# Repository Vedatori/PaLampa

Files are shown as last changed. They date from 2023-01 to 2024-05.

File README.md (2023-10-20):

# PaLampa [cz]
PaLampa je chytrá stolní lampička navržená jako výrobek na Letní robotický tábor 2023 organizovaný spolkem [Vědátoři](www.vedatori.cz). 
Jedná se o výrobek speciálně vyvinutý tak, aby si na něm člověk mohl zlepšit dovednosti při mechanické stavbě, pájení a programování. 
Účastníci dostali tento výrobek jako stavebnici, kdy pájeli nestandardní součástky na DPS s předem osazenými SMD součástkami a z předem připravených dílů sestavili mechanickou část. 
Po finalizaci je možné výrobek programovat a díky množství vstupních a výstupních periferií si naprogramované funkcionality přehledně demonstrovat. 
Nakonec je výrobek možné použít jako chytrou a praktickou stolní lampičku. 

Mechanickou část lze rozdělit na dvě hlavní části - spodní krabici a horní lampu. Vnější části krabice jsou vyřezány z překližky na laserové řezačce a obsahují zámkové západky. 
Ty se při stavbě lepí disperzním lepidlem a po vyschnutí tvoří pevný základ pro uložení ostatních dílů. 
Základní díl horní lampy je vytisknutý na 3D tiskárně a světelný difuzor je vyřezán z plexiskla, které bylo následně zmatněno. 
Spojení osmiček a krabice zajišťuje 3D tištěný nosník umístěný uvnitř krabice, který také fixuje desky plošných spojů (DPS). 
Spojení krabice a lampy zajišťuje překližkový nosník napojený skrze ohebné kouby, kdy spodní kloub disponuje aretací v několika polohách. 

Hlavní DPS obsahuje zejména mikrokontroler ESP32, který je na ni připájen. Programování a napájení je zajištěno přes USB-C. 
Hlavní DPS obsahuje také tlačítka, dotyková tlačítka, potenciometr, fotorezistory, teplotní senzor, OLED grafickou obrazovku a bzučák. 
V lampě je vsazena DPS osazená LED světly svítícími teplou a studenou bílou, stejně jako řadou adresovatelných RGB LED. Další takové LED jsou umístěny zezadu na nosníku, kde zajišťují ambientní podsvětlení prostoru za výrobkem. 
Výrobek je rozebiratelný, jednotlivé DPS jsou spojeny konektory, vzdálenější periferie pomocí kabelů.

Všechny periferie byly zvoleny tak, aby vytvořily výrobek s mnoha volitelnými postranními funkcionalitami. 
Díky nim je možné u účastníků tábora rozvíjet jejich schopnost algoritmizovat úlohu a programovat. 
Pro hodiny byla vytvořena softwarová knihovna, která výrazně zjednodušuje interakci s periferiemi. 
Pomocí této knihovny byl vytvořen vzorový software, pomocí kterého je možné výrobek používat v základním nastavení. 
Výrobek je možné ovládat pomocí vstupních periferií nebo přes WiFi skrz počítač nebo smartphone, které přistupojí k interně hostované webové stránce. 
Všechny tyto vlastnosti lze upravovat a přidávat nové funkcionality podle přání uživatele. Zařízení se programuje ve Visual studio Code v jazyce C++ pomocí frameworku esp32-arduino.

Myšlenkou tohoto projektu je, aby výrobek tvořil každodenní užitečný doplněk pokoje, ale aby mohl být jeho software jednoduše modifikován a rozvíjen tak, jak si každý jeho vlastník představuje.

## Návod
Při stavbě hodin Time-O-Mat postupujte podle připravených návodů v následujícím pořadí:
1. [Návod pro elektroniku](https://github.com/Vedatori/PaLampa/blob/main/Manuals/PaLampa_electronics_cz.md)
1. [Návod pro mechaniku](https://github.com/Vedatori/PaLampa/blob/main/Manuals/PaLampa_mechanics_cz.md)
1. [Návod pro programování](https://github.com/Vedatori/PaLampa/blob/main/Manuals/PaLampa_programming_cz.md)
1. [Lekce na programování](https://github.com/Vedatori/PaLampa/blob/main/Manuals/PaLampa_lectures_achievements.md)

# PaLampa [en]
PaLampa is a smart desk lamp designed as a product for the Summer Robotics Camp 2023 organized by the association Vědátoři. It is a product specially developed to help individuals improve their skills in mechanical construction, soldering, and programming. Participants received this product as a kit, where they soldered non-standard components onto a PCB with pre-mounted SMD components and assembled the mechanical part from pre-prepared pieces. After completion, the product can be programmed, and the programmed functionalities can be easily demonstrated thanks to the variety of input and output peripherals. In the end, the product can be used as a smart and practical desk lamp.

The mechanical part can be divided into two main components - the bottom box and the upper lamp. The outer parts of the box are laser-cut from plywood and include locking mechanisms. These are glued together with dispersion adhesive during construction, forming a sturdy foundation for the placement of other components.
The core component of the upper lamp is 3D-printed, and the light diffuser is cut from frosted plexiglass. The connection between the box and the lamp is ensured by a 3D-printed beam located inside the box, which also secures the printed circuit boards (PCBs).
The connection between the box and the lamp is facilitated by a plywood beam connected through flexible joints, with the lower joint having several locking positions.

The main PCB (Printed Circuit Board) primarily features the ESP32 microcontroller, which is soldered onto it. Programming and power supply are provided through USB-C. The main PCB also includes buttons, touch buttons, a potentiometer, photoresistors, a temperature sensor, an OLED graphic display, and a buzzer.
In the lamp, there is a PCB embedded with warm and cool white LEDs, as well as a series of addressable RGB LEDs. Additional LEDs of this kind are positioned at the rear on the beam, providing ambient lighting for the area behind the product. The product is modular, and the individual PCBs are connected via connectors, while remote peripherals are linked using cables.

All peripherals were selected to create a product with many optional side functionalities. Thanks to these features, participants in the camp can develop their ability to algorithmize tasks and program. A software library was developed for the lessons, significantly simplifying the interaction with peripherals. Using this library, a sample software was created that allows the product to be used in its basic configuration.
The product can be controlled through input peripherals or via Wi-Fi using a computer or smartphone connecting to an internally hosted web page. All of these features can be customized, and new functionalities can be added as per the user's desires. The device is programmed in Visual Studio Code using the C++ language and the esp32-arduino framework.

The idea behind this project is for the product to serve as an everyday useful addition to a room, but with software that can be easily modified and expanded as envisioned by each owner.

## Licence
* Obsah tohoto repozitáře mimo složku *Software* je sdílen pod licencí [Attribution-NonCommercial-ShareAlike 4.0 International (CC BY-NC-SA 4.0)](https://creativecommons.org/licenses/by-nc-sa/4.0/).
* Obsah složky *Software* je sdílen pod licencí [GNU Lesser General Public License v3.0](https://www.gnu.org/licenses/lgpl-3.0.en.html).

## License
* The contents of this repository excluding folder *Software* is shared under license [Attribution-NonCommercial-ShareAlike 4.0 International (CC BY-NC-SA 4.0)](https://creativecommons.org/licenses/by-nc-sa/4.0/).
* The contents of the folder *Software* is shared under license [GNU Lesser General Public License v3.0](https://www.gnu.org/licenses/lgpl-3.0.en.html).

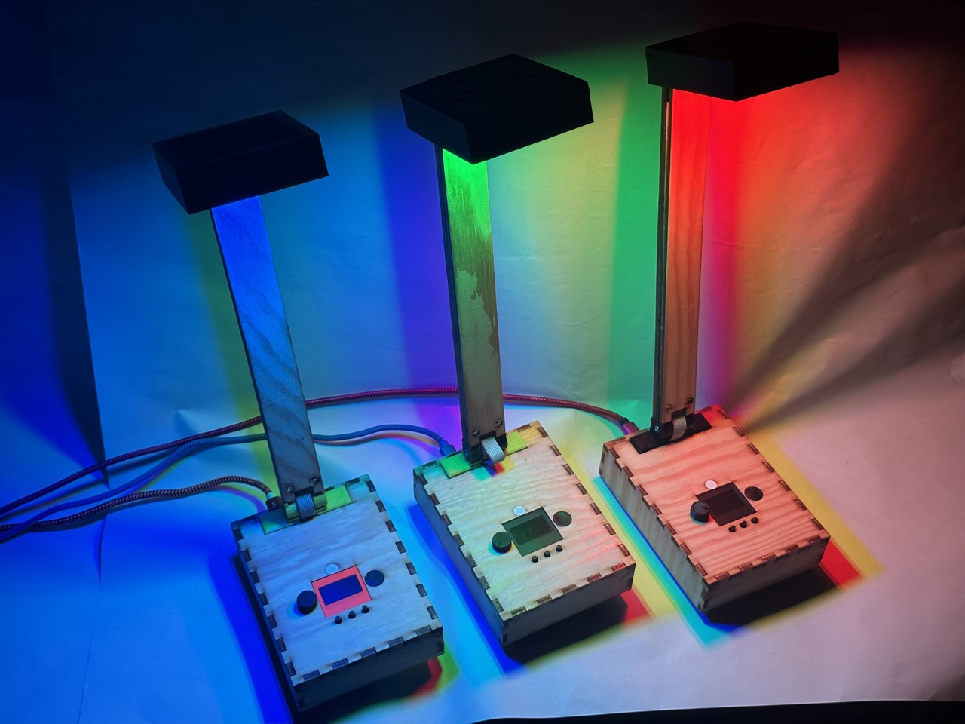
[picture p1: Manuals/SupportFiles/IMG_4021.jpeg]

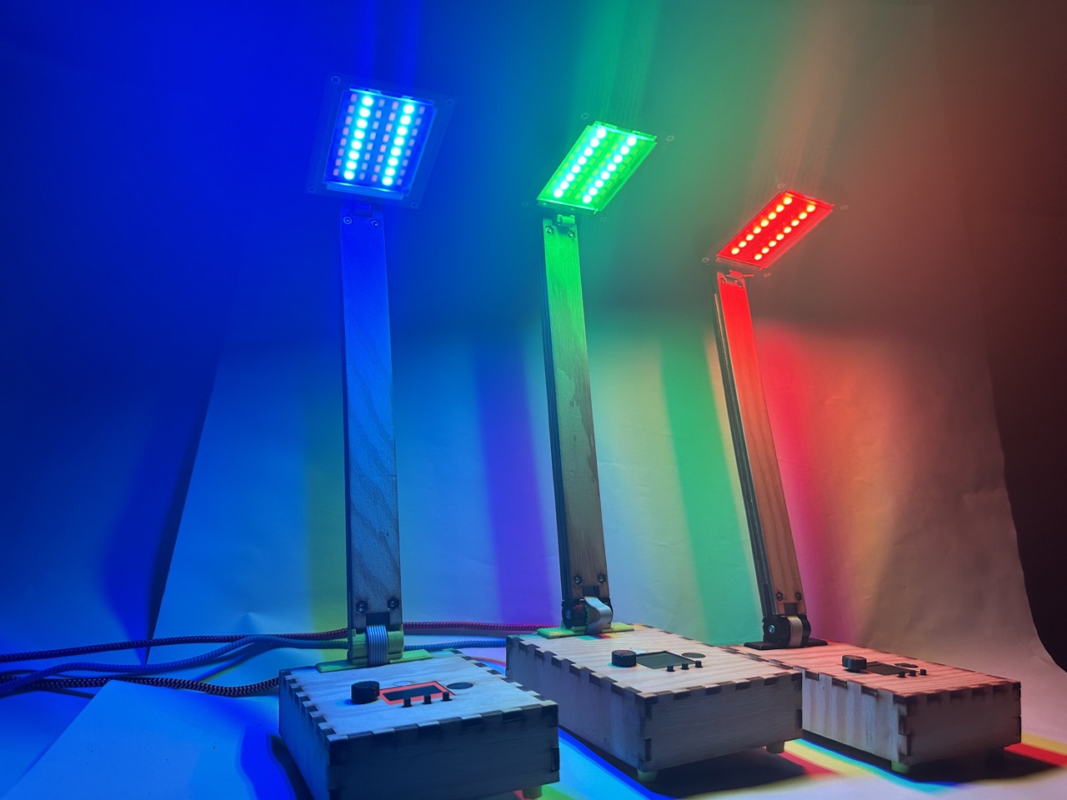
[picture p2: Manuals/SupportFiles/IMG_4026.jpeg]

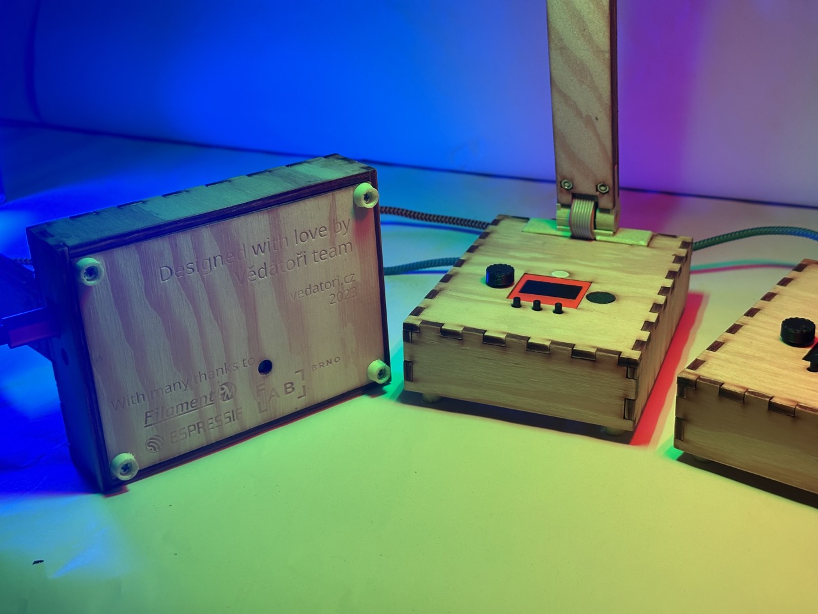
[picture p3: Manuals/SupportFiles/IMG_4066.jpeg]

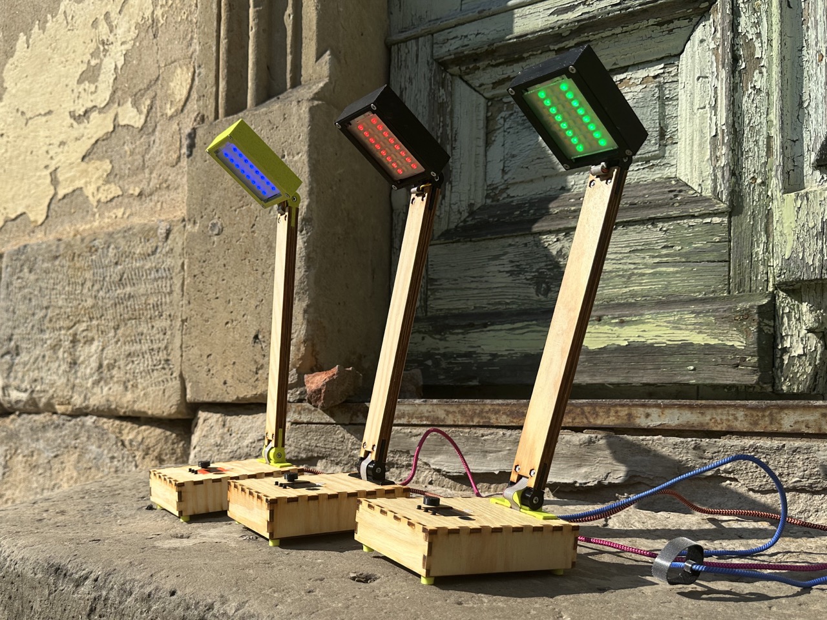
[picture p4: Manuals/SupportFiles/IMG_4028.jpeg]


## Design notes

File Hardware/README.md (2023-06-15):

# HW Designer's notes
## I2C addresses
+ OLED Display - `0x3C`
+ FUSB302 - `0x22`

## Current consumptions
+ Board's idle current consumption (with overhead) - ESP and OLED running, no LEDs - 150 - 200 mA
+ WW or CW string at 100% duty (without board's idle consumption) - 1400mA, the current consumption is approximately linear with the PWM duty cycle

## Misc
+ Potentiometer is wired backwards (eg. ADC value decreases when turning counter clockwise) - change it in the next Rev or in SW
+ Current sense resistor in the CC LED driver was probably DoA, check who's fault it was, maybye use 1206 reistors for current spikes from charged capacitors when connecting LEDs to running driver
+ Some LEDs were not soldered correctly - there is probably nothing I can do about it, just beware.
+ Change WW pin to IO17 (Pin 28), internal pullup on IO5 caused short flash on startup / ESP reset. The situation is much better on GPIO17, but for some reason the WW strings still flash on startup (but not on ESP rst, which is weird, might look into it later with more boards assembled).
+ Add JST for Neopixel
+ New Vedatori Logo

## 17.05.2023 - Developer's meeting
+ Add temperature measurement to LED board
+ Add milled grooves to LED board edges for better cooling
+ Add JST 3 pin for neopixel LEDs onto mainboard and create new Neopixel channel
+ Move one photoresistor to the back, switch it with the electrolytic capacitor, move the second photoresistor somewhere near
+ Add "do not remove while running" text near connectors 
+ Add 2 pin JST for touch
+ move buzzer

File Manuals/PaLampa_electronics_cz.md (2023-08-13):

V tomto dokumentu je uveden návod na osazení desky plošných spojů elektronickými součástkami. Některé součástky byly osazeny strojově při výrobě desek. Zbytek osazení je předmětem tohoto návodu.
Pro tento návod si zavedeme následující pojmy:
* DPS (Deska Plošných Spojů) - Laminátová deska pokrytá elektricky vodivými měděnými cestami, na kterou budeme nyní pájet součástky.
* PCB (Printed Circuit Board) - To stejné, co DPS.
* SMD (Surface Mount Device) - Tzv. bezvývodové elektronické součástky, které mají krátké nožičky. Tyto součástky jsou připájeny k DPS pouze z jedné strany. Tyto součástky byly osazevy strojově při výrobě DPS.
* THT (Through-hole Technology) - Tzv. vývodové elekotronické součástky, které mají dlouhé nožičky. Tyto nožičky jsou před zapájením součástky prostrčeny skrz otvory v DPS.

THT součástky budeme pájet následujícím způsobem:
1. Součástku vkládáme ze strany, kde je její obrys naznačen bílou čárou, tzv. silkscreenem.
1. Vývody (nožičky) součástek prostrčíme přisušnými otvory v DPS. Musí to jít lehce.
1. Součástku přitlačíme až k desce nebo co nejblíže.
1. Součástku pájíme ze strany, na kterou trčí její vývody. Tzn. z opačné strany, než je její bílý obrys na silkscreenu.
1. Vývody po zapájení zastřihneme.

___
# Obsah
* [Nízké součástky](#nizke)
* [Ovládací součástky](#ovladaci)
* [Měřicí součásstky](#meridla)
* [Vložení displeje](#displej)
* [LED deska](#LEDdeska)
* [Výroba kabelu](#tukabel)
* [Připevnění krytky](#krytka)
___

<!-- _________________________________________________________________ -->
# <a name = nizke>Nízké součástky</a>

## Potřebujeme:
* Hlavní PCB (černý)
* 2pin JST konektor
* piezoměnič
* 2x kondenzátor
* štípací kleště
* páječka

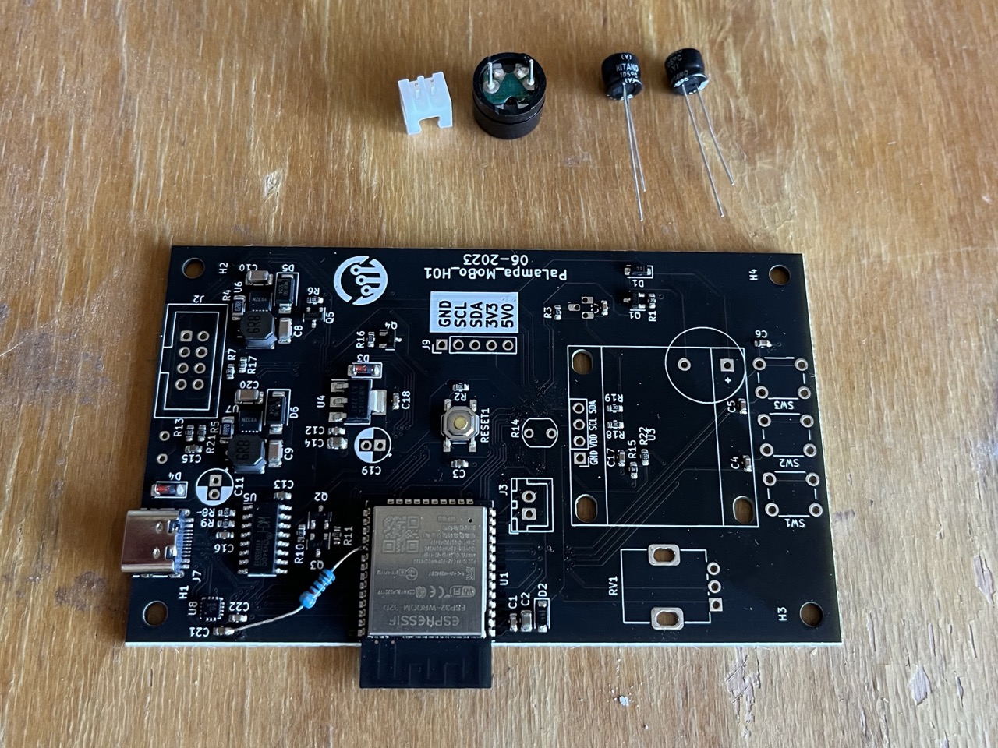
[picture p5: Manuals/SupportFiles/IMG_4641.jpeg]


## Postup:
Vložte piezoměnič na jeho místo v desce, Dávejte pozor na polaritu, symbol plus na součástce musí být u symbolu plus na desce.
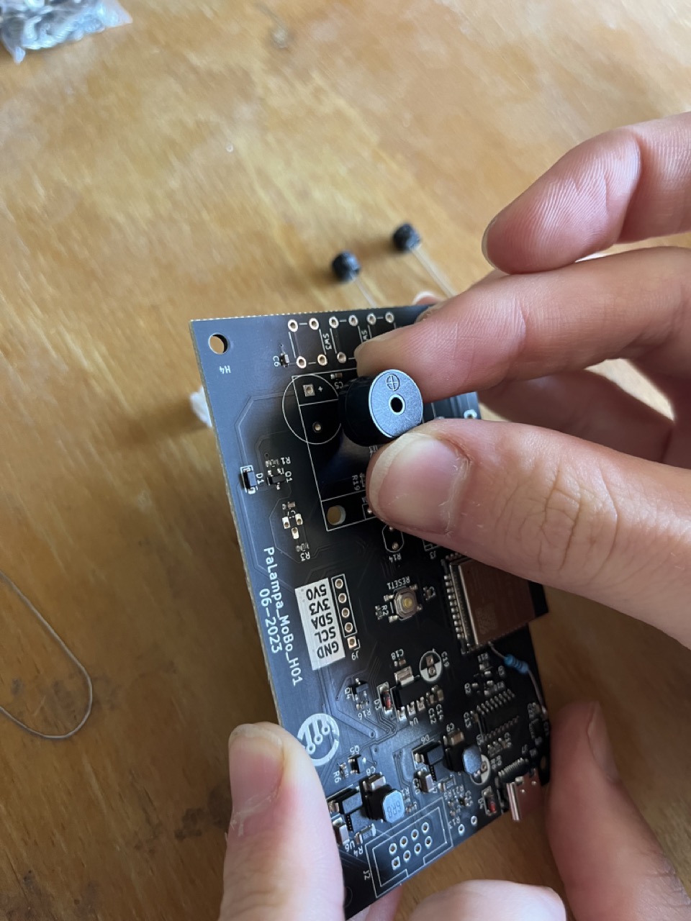
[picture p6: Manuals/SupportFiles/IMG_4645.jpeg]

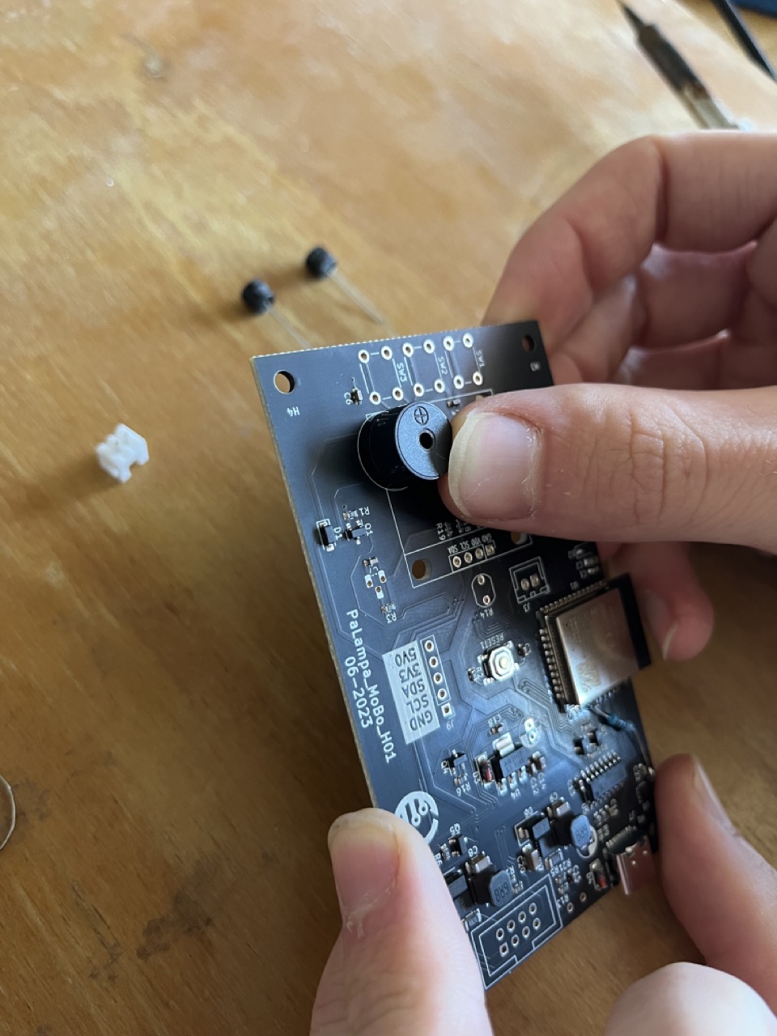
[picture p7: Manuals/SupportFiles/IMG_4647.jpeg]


Zapájejete piezoměnič. Pomocí štípacích kleští zakraťte vývody.
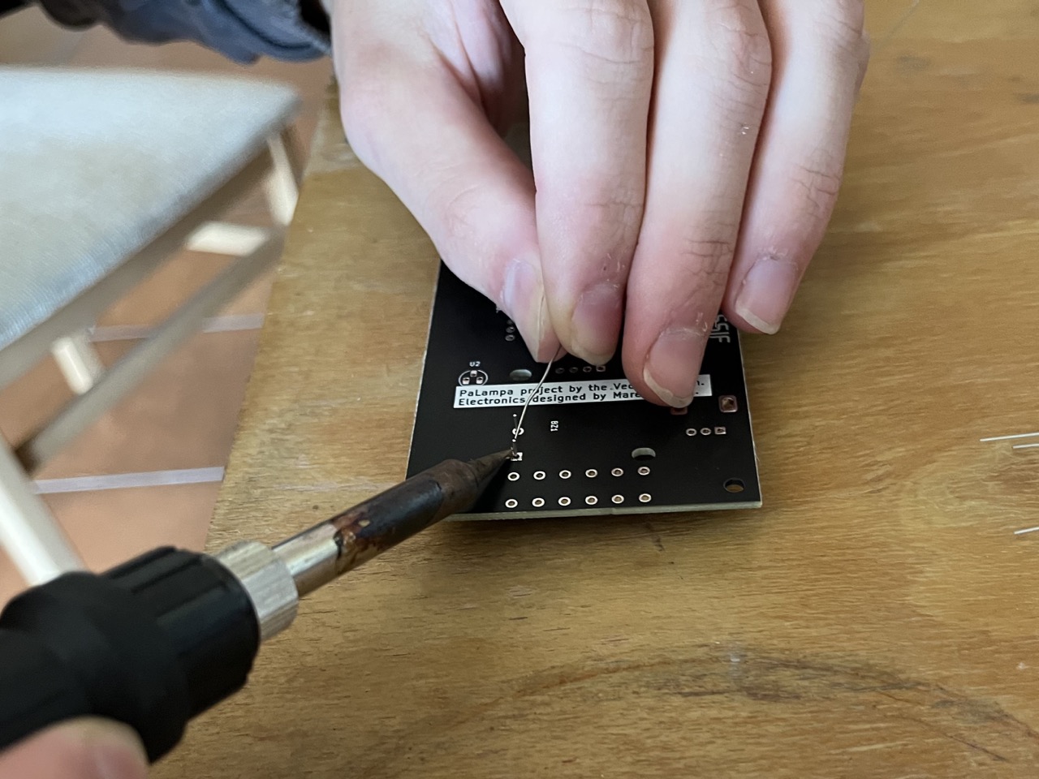
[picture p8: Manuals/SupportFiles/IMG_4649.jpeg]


Vložte do desky konektor JST.Pozor na orientaci, je důležité ho otočit přesně tak, jako je na obrázku.
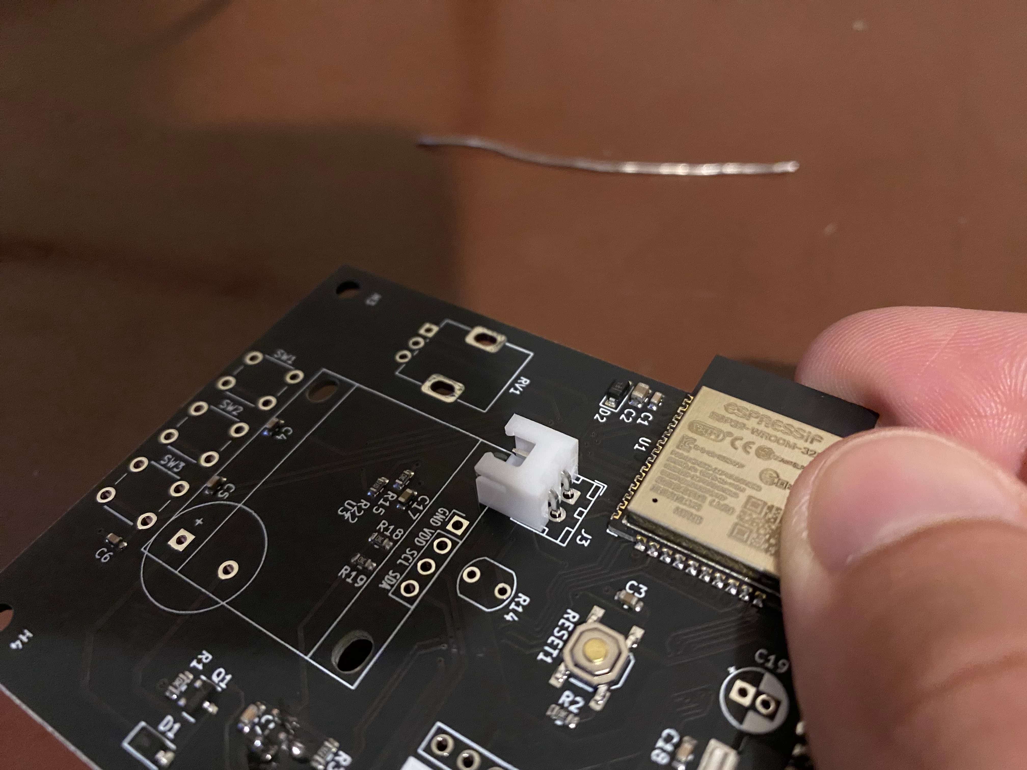
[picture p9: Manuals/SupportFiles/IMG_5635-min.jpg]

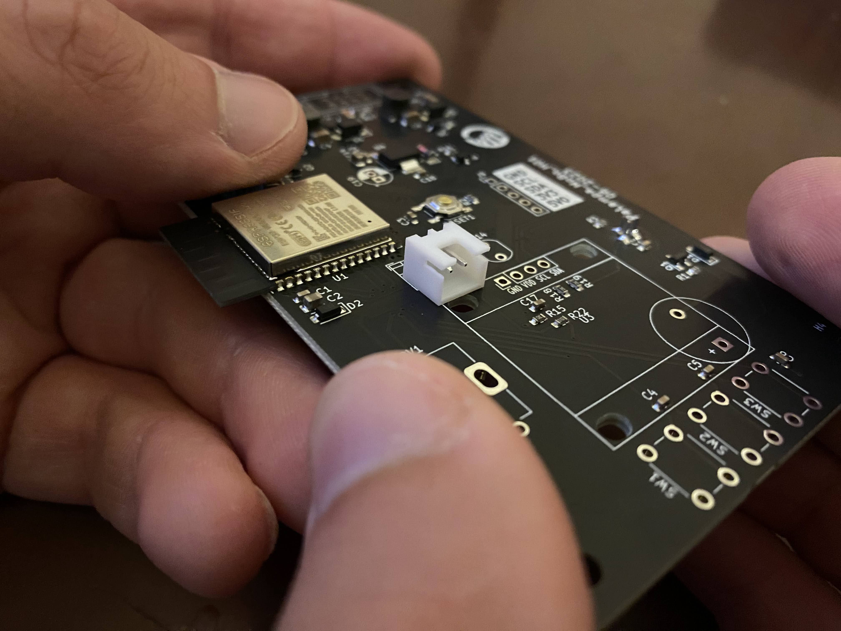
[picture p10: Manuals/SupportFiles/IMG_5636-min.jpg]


Zapájejte. Zakraťte vývody.
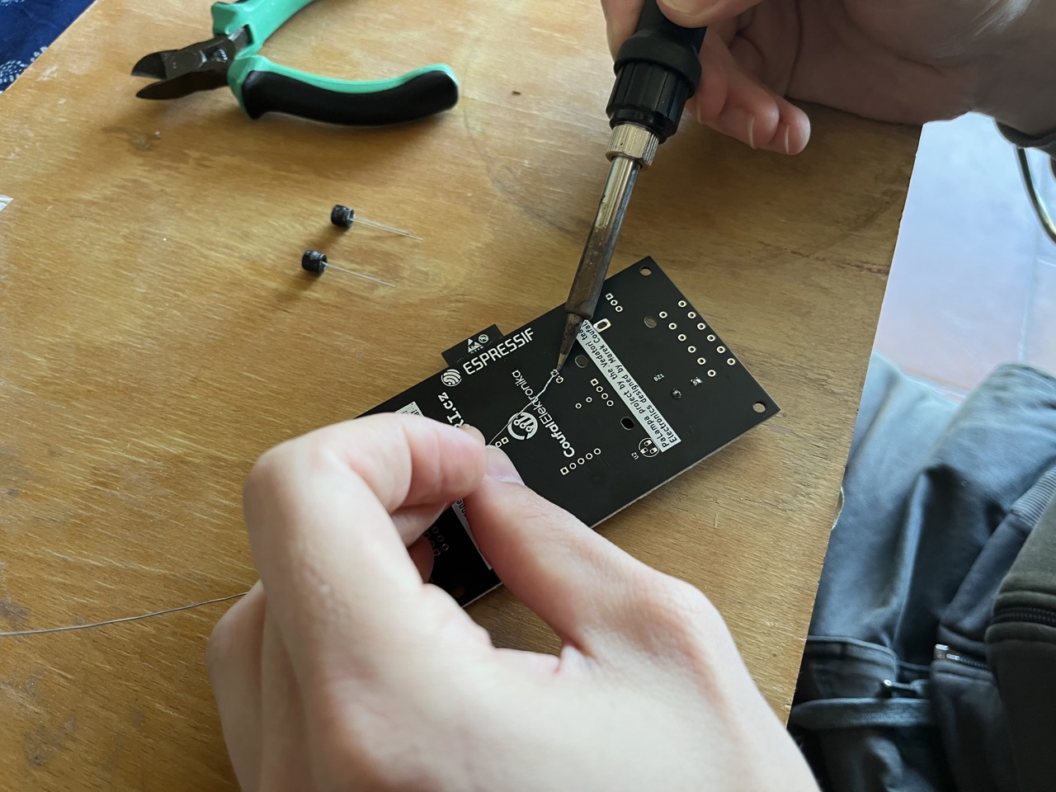
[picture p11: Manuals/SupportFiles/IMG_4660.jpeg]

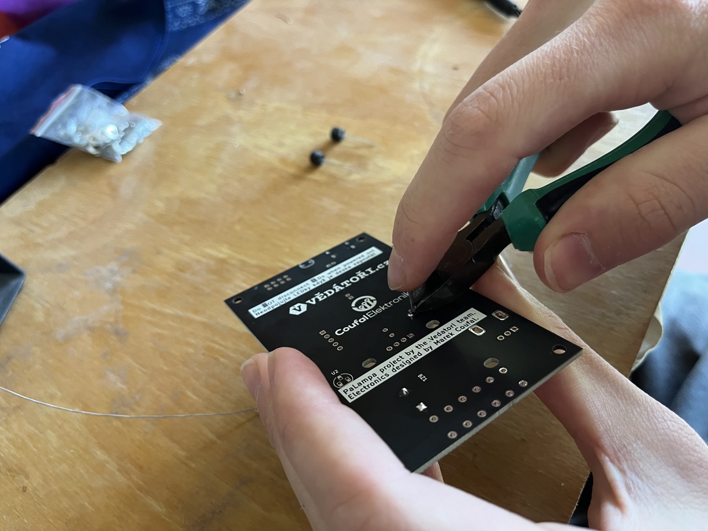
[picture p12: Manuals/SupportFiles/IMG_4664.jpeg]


Vložte do desky kondenzátor na místo označené C11. Pozor na polaritu, kratší vývod musí být zastrčený do poloviny kruhu, která je bíle vybarvená. Druhý kondenzátor vložte stejným způsobem na místo C19. Zapájejte, zakraťe vývody.
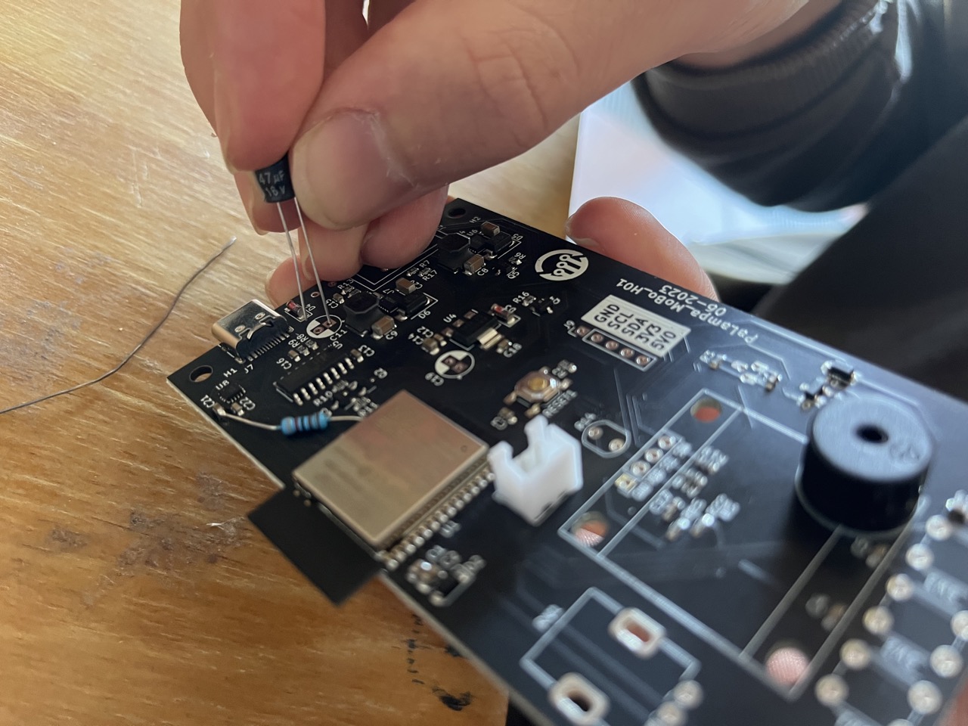
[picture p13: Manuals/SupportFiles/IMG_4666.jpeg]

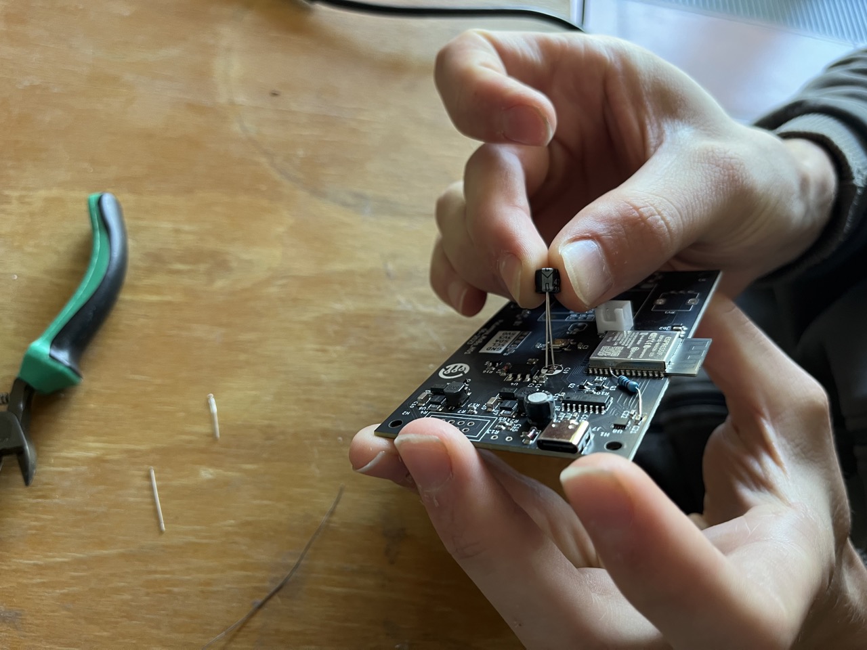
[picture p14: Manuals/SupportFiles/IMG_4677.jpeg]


Takto má deska vypadat po zapájení prvních součástí.
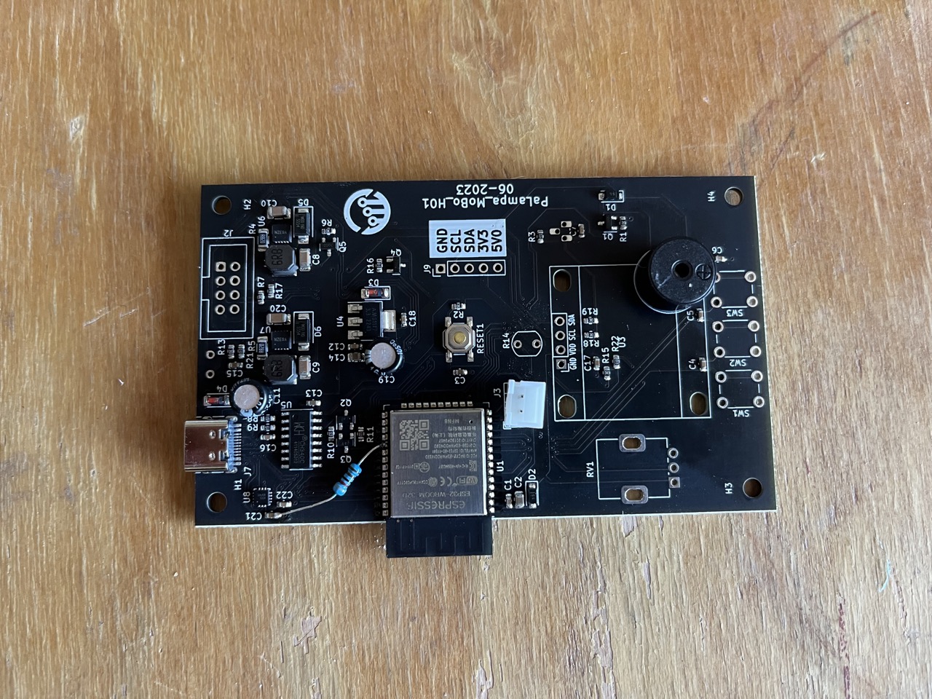
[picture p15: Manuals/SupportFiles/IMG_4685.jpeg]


Kleštěmi oddělte 4 piny z dutinkové lišty. Lištu rozstřihněte na místě, kde je pátý pin od kraje, ten se tím zničí.
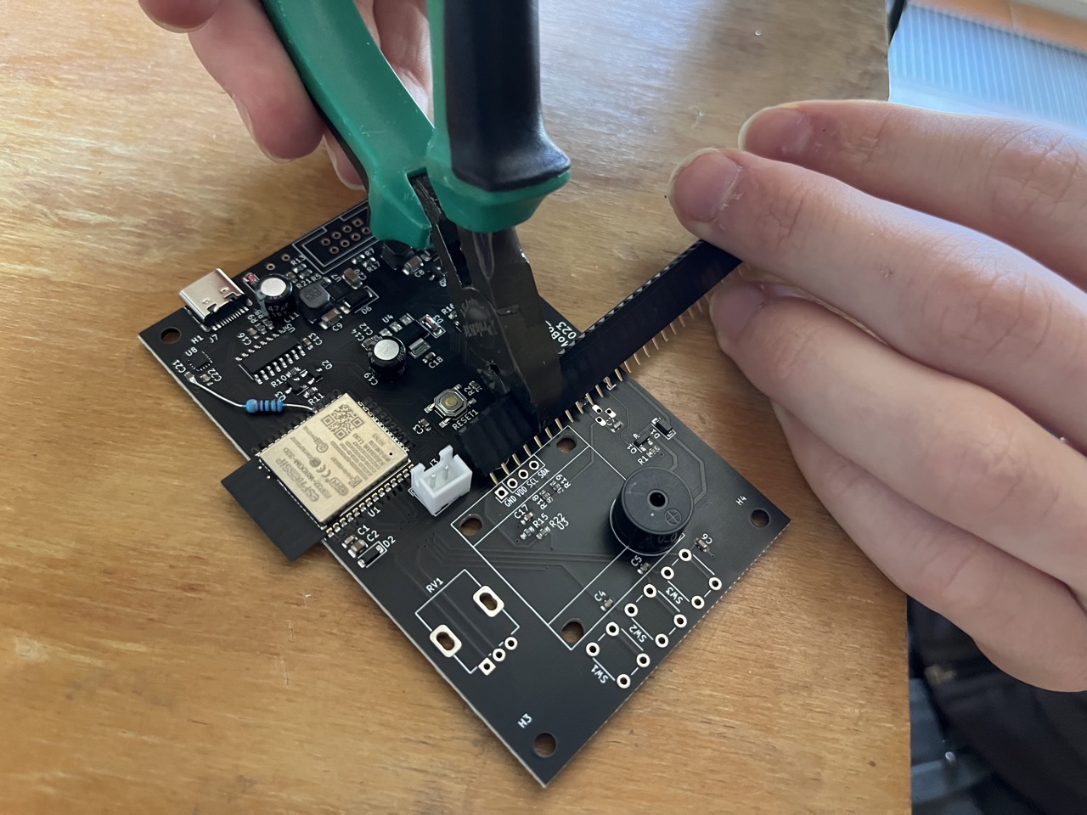
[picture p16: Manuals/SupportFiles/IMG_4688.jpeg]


Opatrně zařízněte boky lišty.
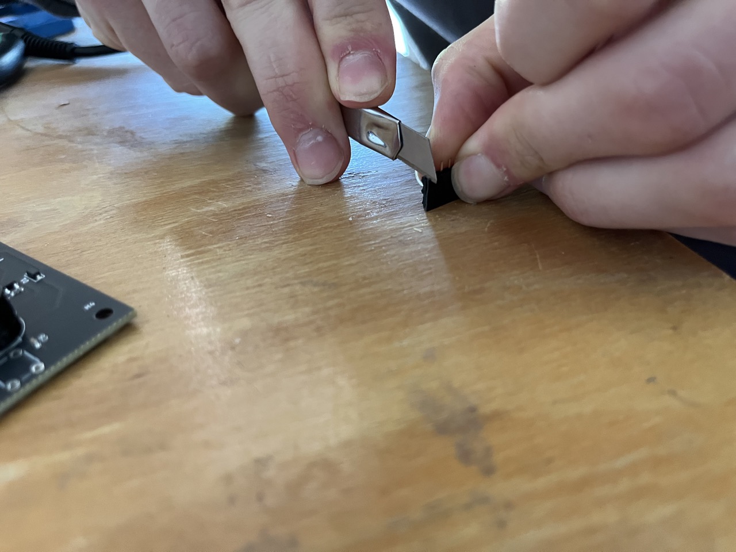
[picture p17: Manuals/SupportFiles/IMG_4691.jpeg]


Lištu vložte do prostoru konektoru na displej, jak vidíte na obrázku. Zapájejte ji.
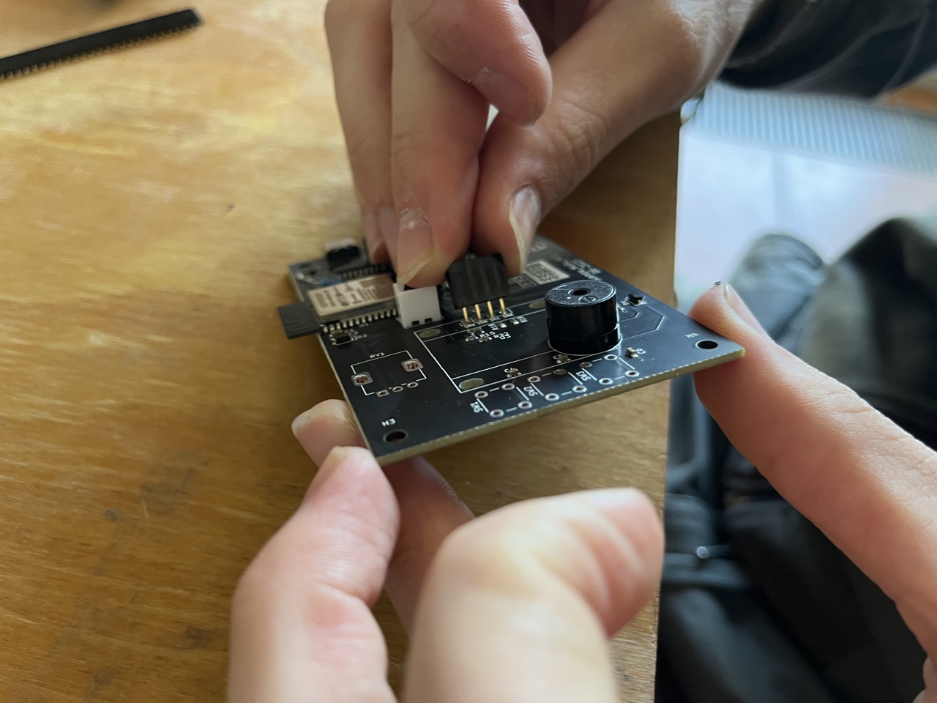
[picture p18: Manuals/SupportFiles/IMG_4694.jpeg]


Výsledný pohled
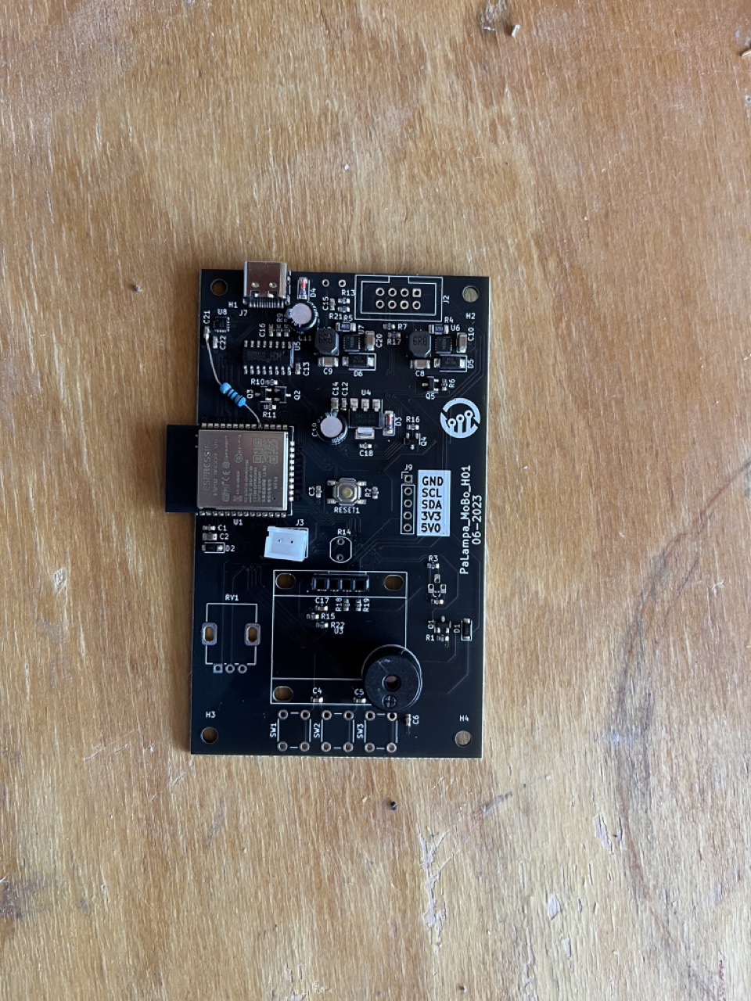
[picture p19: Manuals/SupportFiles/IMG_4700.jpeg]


<!-- _________________________________________________________________ -->
# <a name = ovladaci>Ovládací součástky</a>

## Potřebujeme:
* Hlavní PCB
* 3D tištěný tool pro tlačítka (3 díry)
* 3x tlačítko
* Potenciometr
* Konektor
* štípací kleště
* páječka

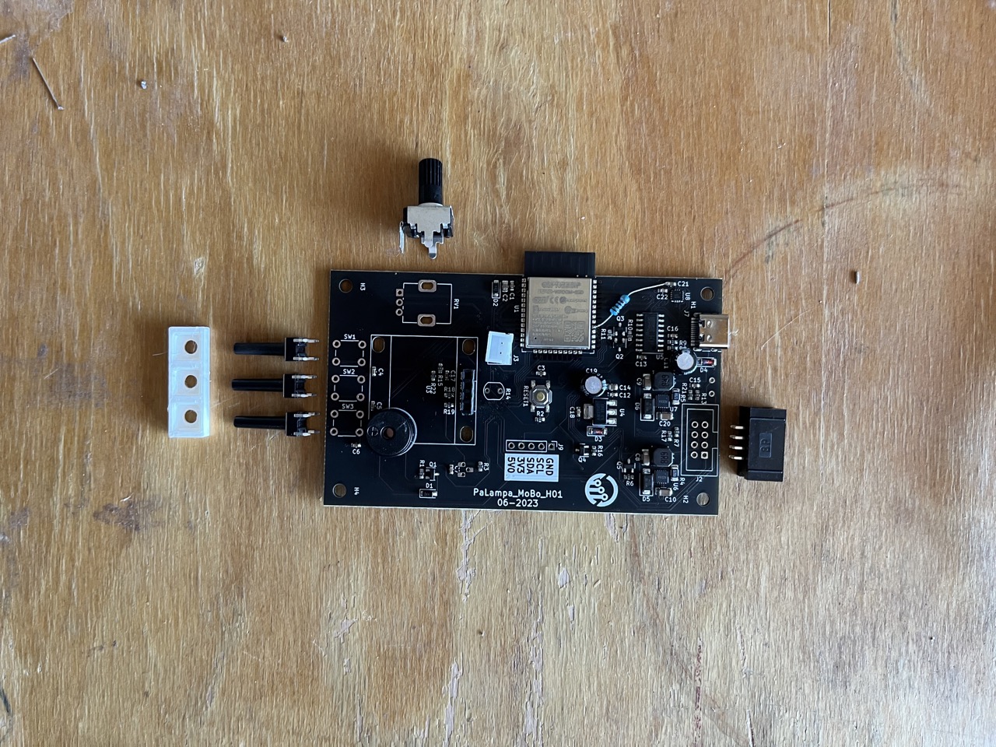
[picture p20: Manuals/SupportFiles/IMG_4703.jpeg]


## Postup:
Nasaďte konektor na hlavní PCB. POZOR! Mezi součástkami jsou dva podobné konektory, tady musíte použít ten, který má krátké nezahnuté nožičky. Konektor musí mít správnou polaritu, výřez musí být směřován na stejnou stranu, jako je na obrázku. Konektor zapájejte.
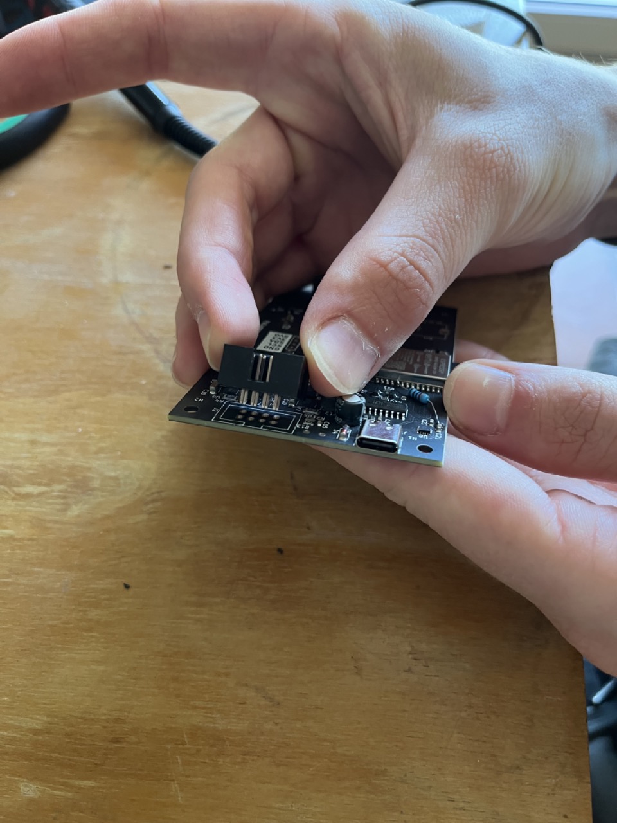
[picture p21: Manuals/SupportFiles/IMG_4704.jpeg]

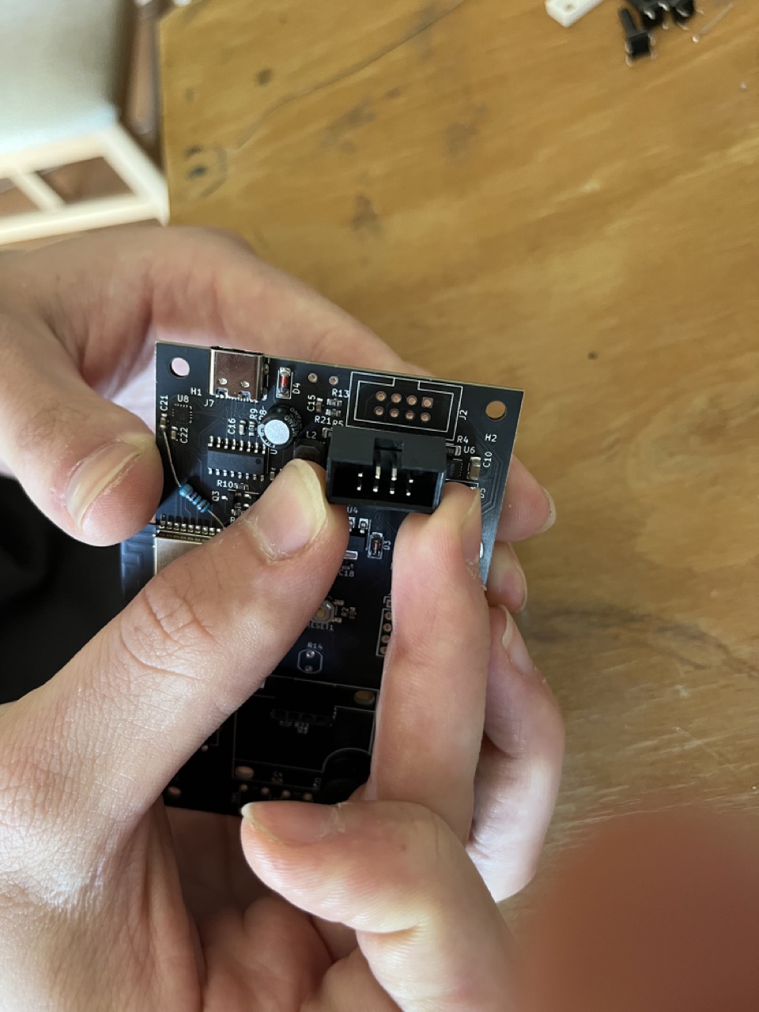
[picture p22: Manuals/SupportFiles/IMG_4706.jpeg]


Usaďte do desky potenciometr.
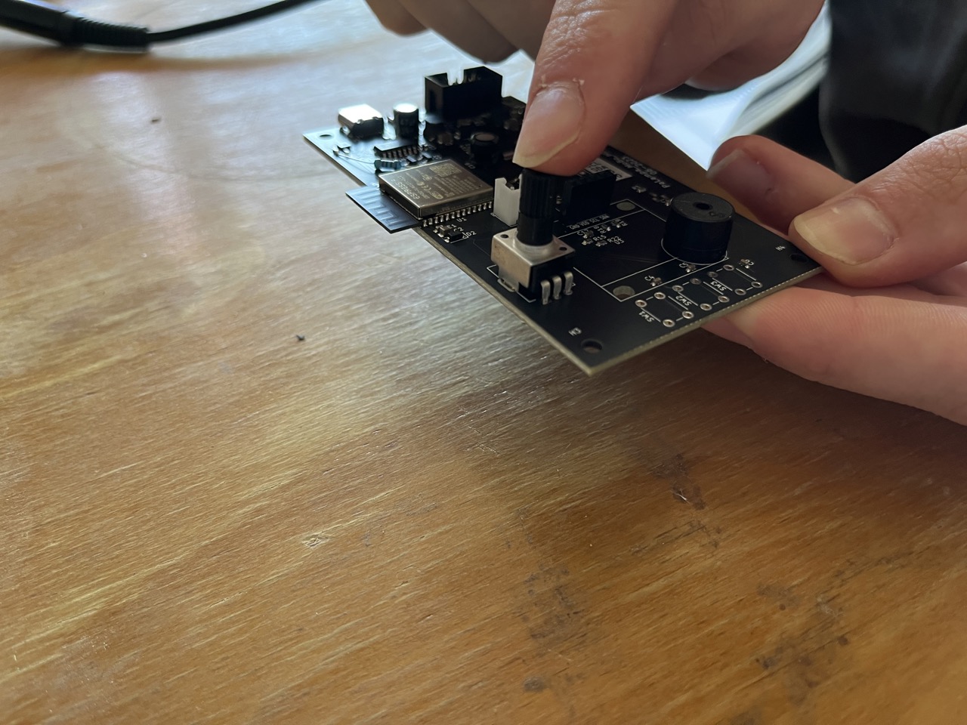
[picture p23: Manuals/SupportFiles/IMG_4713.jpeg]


 Zapájejte všechny vývody včetně velkých plochých. Zakraťte vývody.
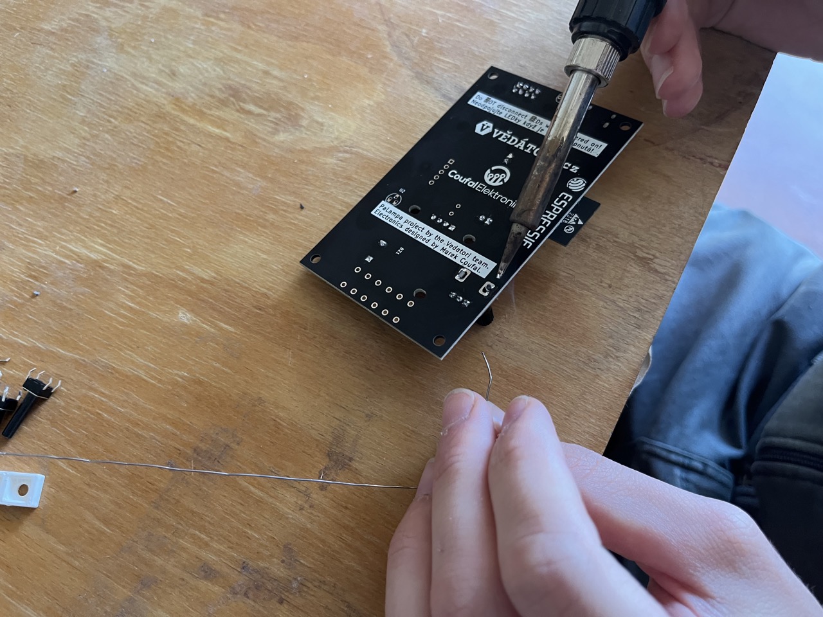
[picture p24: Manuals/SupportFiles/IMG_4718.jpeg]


Vložte tlačítka do hlavního PCB. 
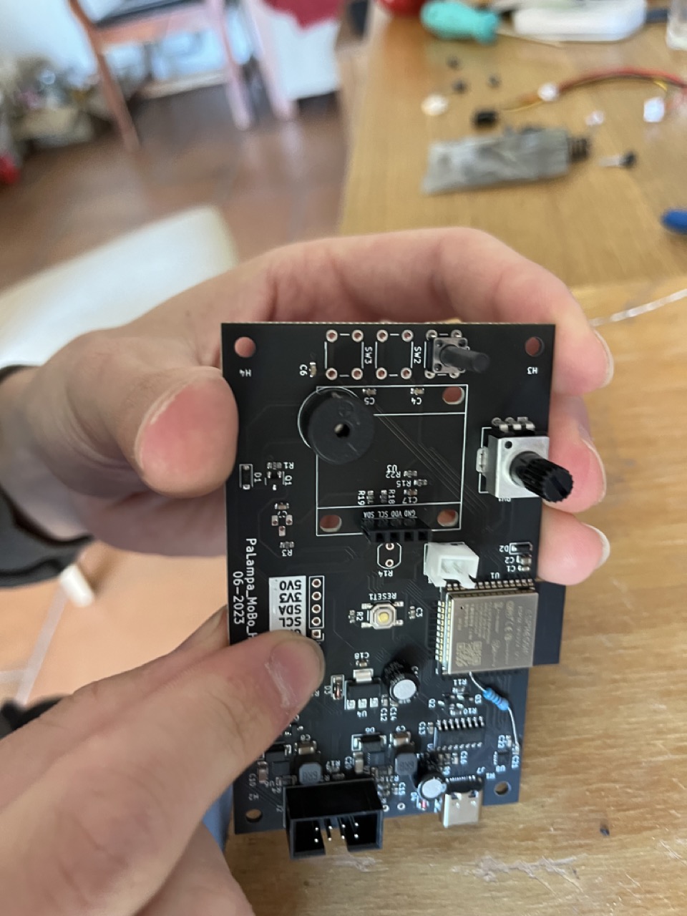
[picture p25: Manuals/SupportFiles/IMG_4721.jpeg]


Na tlačítka nasuňte nástroj s děrami. Musí padnout na všechna zároveň.
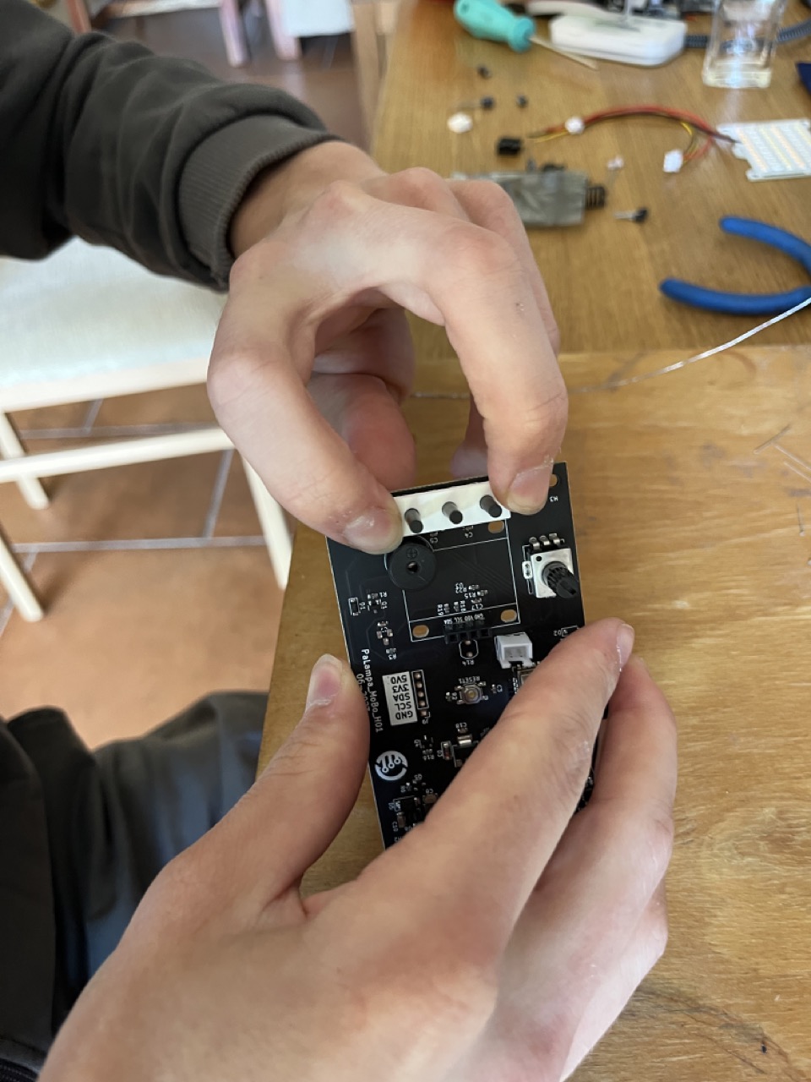
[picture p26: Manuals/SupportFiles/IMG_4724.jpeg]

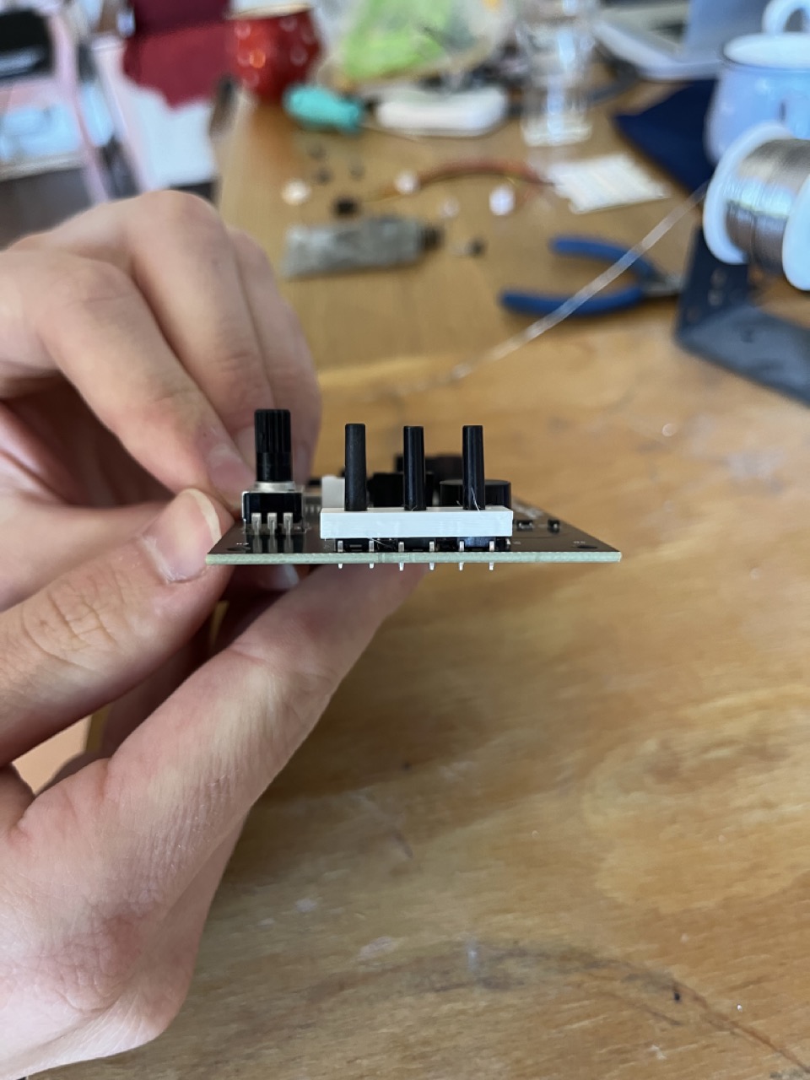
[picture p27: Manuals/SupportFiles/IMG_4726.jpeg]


Zapájejte tlačítka na hlavní PCB. Zakraťte vývody.

<!-- _________________________________________________________________ -->
# <a name = meridla>Měřicí součástky</a>

## Potřebujeme:
* Hlavní PCB
* 2x fotorezistor
* teplotní senzor
* Distanční díl na fotorezistor
* štípací kleště
* páječka

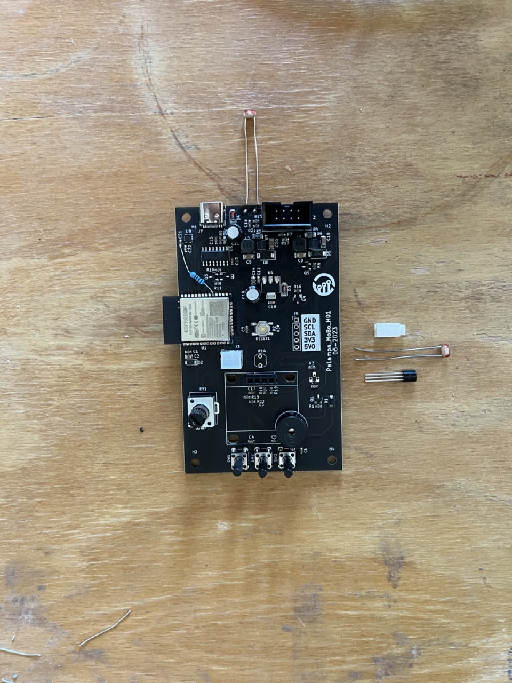
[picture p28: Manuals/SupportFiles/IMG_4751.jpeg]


Do otvoru označeného R13 nasuňte fotorezistor. Odměřte ho podle dříve použitého toolu tak, jak ukazuje obrázek. Zapájejte.




Druhý fotorezistor nasuňte do 3D tištěného distančního dílu. Zapájejte na místo R14. Zakraťte vývody obou fotorezitstorů.




Výsledný pohled na spodní fotorezistor.


Teplotní senzor zasuňte do desky pouze na několik milimetrů. 


Podložte si desku, aby se senzor při pájení neohnul.


Zapájejte. Po zapájení jednoho vývodu ověřte, že je senzor postavený rovně. Pokud ne, tak si senzor ohněte do směru kolmého k desce.


<!-- _________________________________________________________________ -->
# <a name = displej>Vložení displeje</a>

## Potřebujeme:
* hlavní PCB
* Displej s připájenou kolíkovou lištou
* Plastový držák displeje



# Postup:
Zastřihněte vývody kolíkové lišty vedoucí do displeje.


Opatrně vložte displej do držáku. Můžete ho mírně rozevřít, ale dávejte pozor, ať bok nevylomíte.



Zasuňte displej s držákem do hlavní desky pomocí kolíkové lišty.



<!-- _________________________________________________________________ -->
# <a name = LEDdeska>LED deska</a>

## Potřebujeme:
* LED desku
* Teplotní senzor
* Úhlový konektor černý 8 pin
* Úhlový konektor bílý JST 3 pin
* Nástroj pro usazení teplotního senzoru
* Epoxidové lepidlo s kovovým plnivem (namíchá vedoucí)
* Dávkovací špejli
* páječku



## Postup:
Vložte teplotní senzor do 3D tištěného nástroje tak, aby nápis směřoval směrem dovnitř. Ohněte podle nástroje nožičky.


Otočte senzor teploty tak, aby byl čitelný nápis na něm.


Naneste malé množství připraveného epoxidu na plochu senzoru.


Vložte senzor do desky tak, aby směřoval směrem doprostřed desky. Tento krok provádějte pod dohledem vedoucího.


Desku se senzorem pořád umístěným v nástroji přitlačte z druhé strany směrem ke stolu.


Senzor připájejte, zakraťte vývody.


Do desky vložte 3pin bílý konektor. Připájejte a zaktaťte vývody.


Černý konektor vložte do desky stejným směrem, jako vidíte na obrázku.


Desku z druhé strany podepřete nástrojem použitým v minulém kroku.


Konektor připájejte. Výsledný pohled


<!-- _________________________________________________________________ -->
# <a name = tukabel>Výroba kabelu</a>

## Potřebujeme:
* kabel o délce 46 cm
* Kleště nebo malý svěrák na krimpování kabelu
* 2x konektor
* 1x krytka konektoru



POZOR! Kabel se vyrábí pouze na speciálním stanovišti pod dohledem vedoucího. Pokud se konektory nakrimpují špatně, musí se odstřihnout a tím se celý kabel zničí.

## Postup:
Odměřte a ustřihněte si kabel o délce 46 cm.


Nasuňte konektor na kabel tak, aby výstupek směřoval ke kraji kabelu. Šipka na konektoru musí směřovat k červené žíle kabelu.


Zarovnejte konec kabelu s konektorem. Stlačením kabel nakrimpujte. Pozor, je to nevratná operace, nechte si tento krok předem potvrdit vedoucím.


Ohněte kabel přes konektor a upněte ho do krytky. Ta se do konektoru nacvakne.



Na druhý konec kabelu nasuňte konektor tak, aby výstupek směřoval ke kraji kabelu. Šipka na konektoru musí směřovat k červené žíle kabelu.


Zarovnejte konec kabelu s konektorem. Stlačením kabel nakrimpujte. Pozor, je to nevratná operace, nechte si tento krok předem potvrdit vedoucím.


Zapojte kabel. Konec kabelu, kde je na konektoru krytka, se zapojuje do bílé desky s LED, druhý konec do černé hlavní desky. Společně s vedoucím nahrajte firmware a proveďte funkční test sestavy.


<!-- _________________________________________________________________ -->
# <a name = krytka>Připevnění krytky</a>

## Potřebujeme:
* Epoxid bez kovového plniče (namíchá vedoucí)
* Dávkovací špejli
* LED desku
* 3D tištěnou krytku na vývody konektoru



## Postup:
Naneste malé množství epoxidu na plochy na krajích krytky.


Přilepte krytku přes vývody konektoru. Krytka musí být zarovnaná s krajem desky.


<!-- _________________________________________________________________ -->
# <a name = pasek>LED pásek</a>

## Potřebujeme:
* Kabel se 3 vývody
* LED pásek
* pájku



## Postup:
Naneste trochu cínu na LED pásek. Dávejte pozor, z jaké strany pásek pájíte, musí se připojovat na stranu, kde je na střední plošce napsáno Din. Strana, kde je u prostřední plošky napsáno Do musí zůstat volná.


Připájejte kabely v následujícím pořadí:
Černá - 5V
Žlutá - Din
Červená GND


Výsledné zapojení


<!-- _________________________________________________________________ -->
# <a name = touch>Kabel na touch senzor</a>

## Potřebujeme:
* Kabel se 2 vývody
* Měděná páska
* Záslepku pro dotykové tlačítko

## Postup:
Ustřihněte si kusy měděné pásky o délce 10 mm a 20 mm. 


Na střed obou kusů naneste cín.


K 10mm kusu připájejte červený drátek z kabelu. Cu pásku pájejte kolmo ke kabelu.



Stejným způsobem připájejte i černý akbel k 20mm kusu pásky.

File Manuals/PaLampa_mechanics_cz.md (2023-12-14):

Tento dokument je návodem k sestavení mechanické části PaLampy. Hlavními postupy jsou lepení disperzním lepidlem (Herkules) a spojování šrouby.
Lepení dílů je mnohdy nevratný postup! Pokud si před zalepením dílu nejste něčím jistí, je dobré si to buďto vyzkoušet ještě před nanesením lepidla a nebo zavolat vedoucího, který vám poradí. 

Používaná lepidla a jejich vlastnosti
* **Herkules** - disperzní vodou ředitelné lepidlo na dřevo. Doba zasychání záleží na objemu naneseného lepidla, obecně platí, že pomocí tečkování aplikátorem ho naneseme takové množství, aby moc nebo vůbec nevytékalo z lepeného spoje po jeho zmáčknutí. Nanášíme pouze na jednu lepenou plochu a tečky můžeme poté špičkou lepidla rozetřít do plochy.
* **Lepidlo na plasty** - slouží pro upevnění matek ve slotových dírách. Sloty jsou udělané tak, aby se v nich matka nemohla protočit, lepidlo má pouze zafixovat matku, aby celá nevypadla. Nejlepší je tedy nanést malé množství lepidla na hranu matky (nezanášet lepidlem závit) a matku poté zatlačit až na doraz do slotu.

Při práci je důležité mít pořád čisté ruce a pracovní podložku, abyste si dřevo neumazali.
K lakování jsme vybrali polyurethanový lak, který je ředitelný vodou. Pro dobrý výsledek stačí nanést tenkou vrstvu laku na ohlazený a očištěný povrch tak, aby byla pokrytá celá lakovaná plocha (poznáte po naklonění plochy proti světlu). Nanáší se dvě vrstvy, to je v návodu popsáno.

**Pohledové plochy** poznáte tak, že je okolo okrajů lehká rovnoměrná stopa po ožehu a má světle hnědou barvu. Druhá strana není pohledová a obsahuje po obvodu tmavě hnědé nebo černé stopy. 



___
# Obsah
* [Vylití podstavy sádrou](#sadra)
* [Příprava plexiskla](#plexisklo)
* [Příprava překližkových dílů](#preklizka)
* [Sestavení krku](#krk)
* [Slepení krabičky](#krabice)
* [Sestavení části s hexagony](#hexagony)
* [Sestavení podstavy](#spodek)
* [Sestavení spodního kloubu](#spodnikloub)
* [Sestavení horního dílu](#hornidil)
* [Sestavení horního kloubu](#hornikloub)
* [Finalizace](#finalizace)
* [Příloha: Seznam spojovacího materiálu](#spojovacimaterial)
___

<!-- _________________________________________________________________ -->
# <a name = sadra>Vylití podstavy sádrou</a>

## Potřebujeme:
* Spodní díl krabice
* Ohrádku na sádru
* Sádru
* Vodu
* Sádrovací misku
* Špachtli
* Igelitový sáček
* 4 šrouby M3x30 + matky 



## Postup:
Ukliďte si pracovní plochu po předchozích krocích, tj. odstraňte pájku, příslušenství k pájení a zbytky po něm.
Odlévání sádry nedělejte sami. Proveďte to po skupinách pod dozorem vedoucího.

*Připravte si dopředu všechny díly a potřeby. Pokud si je nepřipravíte předem, budete je hledat, když bude sádra tuhnout a místo odlitku budete mít nekompatibilní sádrový talířek.*

Protáhněte šroub jednou dírou v rohu dřeva. Igelit propíchněte šroubem.



Na šroub dejte ohrádku na sádru tak, jak vidíte na obrázku. 



Našroubujte matku, zcela neutahujte.

Než budete propichovat igleit dalšími šrouby, natáhněte jej. Obdobným způsobem provlečte ostatní tři šrouby. Celá plocha igelitu by měla být přiměřeně napnutá.

Na šrouby nasaďte matky a utáhněte je.



Rozmíchejte sádru s vodou do mírně řidší konzistence. 

Sádru vylejte do připravené vaničky. Hladina sádry by měla být jeden až dva milimetry pod úrovní ohrádky. 



Pro lepší rozlití sádry ve vaničce můžete s odlévaným dílem lehce zatřást nebo lehce klepat o nějaký povrch. 

Výsledný díl vylitý sádrou by měl vypadat přibližně takto:



Nechte sádru zatuhnout a mezitím připravte plexisklo podle dalšího kroku.

<!-- _________________________________________________________________ -->
# <a name = plexisklo>Příprava plexiskla</a>

## Potřebujeme:
* díl z plexiskla
* Hrubý smirek (hnědý - 240)
* Jemný smirek (černý - 600)
* Brusná pasta 
* Papírová utěrka



## Postup:
Z plexiskla odstraňte krycí fólie. 



Hrubým smirkem lehce zaoblete hrany dílu z plexiskla. 



Nyní krouživým pohybem hrubým smirkem zdrsněte průhlednou plochu plexiskla z obou stran.  



Stejný postup proveďte s jemným smirkem (600).



Výsledný povrch plexiskla by měl vypadat následovně:



Nyní plexisklo položte na papírový ubrousek. To je důležité kvůli tomu, aby při leštění nedošlo k jeho poškrábání nečistotami!

Na vrchní stranu plexiskla dřívkem naneste malé množství brusné pasty z kelímku. 



Druhým ubrouskem brusnou pastu krouživými pohyby roztírejte po povrchu plexiskla, čímž dojde k jeho vyleštění. 



Stejný postup opakujte i pro druhou stranu plexiskla. Po dokončení leštění díl umyjte. 

<!-- _________________________________________________________________ -->
# <a name = preklizka>Příprava překližkových dílů</a>

## Potřebujeme:
* všechny díly z překližky 
* Hrubý smirek (žlutý - 240)
* Jemný smirek (černý - 600)

## Postup:
Ukliďte si do čista pracovní plochu. Jakékoli zbytky sádry nebo jiného nepořádku zašpiní překližku.

Pokud dřevo stále obsahuje nějaké části, které měly po vyřezání laserem vypadnout, odstraňte je tak, že je vytlačíte ven. Vytlačte je směrem k nepohledové pološe. 



Pokud dřevo obsahuje nějaké otřepy a zbytky po vytlačení odpadních částí, odstaňte je buďto rukou, nožem nebo hrubým (žlutým) smirkem. Ten můžete kvůli tomu přehnout, ale přehněte pouze část u kraje. Dále podle obrázku níže zkoste nožem hranu asi do 1,5 cm od okraje, a to na obou stranách. 



Obruste smirkem pohledové plochy překližky. Přeburuste plochu nejdříve hrubým smirkem (žlutým) a potom ji dohlaďte jemným (černým) smirkem. Většinou je plocha už od začátku v pořádku, takže není potřeba moc brousit, stačí pouze mírně obrousit lehce opálené okraje pohledové strany.



<!-- _________________________________________________________________ -->

# <a name = krk>Sestavení krku</a>

Ukliďte si pracovní plochu po předchozích krocích, tj. setřete prach vzniklý broušením (nejlépe mokrou hadrou nebo kapesníkem).

## Potřebujeme: 
* Děravý a neděravý díl krku
* 2 díly na bok krku (úzké dlouhé tyčky)
* LED pásek s napájenými přívodními drátky
* Tenký dřevěný díl na oporu LED pásku
* 4 díly kloubů
* Herkules
* Tavná pistole
* Nůž
* 4 šrouby M3x12 se zápustnou hlavou + matky

 

## Postup:
Na nepohledové straně dílu v místě naznačeném na obrázku seřízněte nožem vnitřní hranu. Jedná se o hranu směrem k plastovému kloubu s kulatými okraji (bez zoubků).



Od této chvíle je potřeba dávat pozor, aby byl výřez na vrchní straně krku. V dalších krocích budou výřezem protaženy kabely k LED pásku, které musí vést shora. 

Sestavte vždy 2 a 2 díly kloubů dohromady podle obrázku níže. Později je vyndáte, takže nemusíte přemýšlet, jaká dvojice přijde kam. 



Přišroubujte klouby k děravému dílu krku na obou stranách. Matky dejte tak, aby kopírovaly natočení, které je vystouplé z dílu.



Zkusmo přiložíte neděravý díl krku, matky do něj musí padnout na obou stranách. 



Díl zase odstraňte.

Na jednu stranu úzké tyčky naneste lepidlo. 



K dílu s otvorem přilepte první úzkou dlouhou tyčku tak, aby bok tyčky byl souběžný s bokem podkladového dílu.



Stejným způsobem přilepte druhou tyčku. 



Na okraje tenkého podpůrného dílu naneste lepilo podle následujícího obrázku a do otvoru vložte LED pásek tak, aby jeho kabely směřovaly směrem k vytvořenému výřezu. Pozor, kabely LED pásku směřují k plastovému kloubu s kulatými okraji (bez zoubků), ne tak jako na obrázku (křížek) i dalších obrázcích.



Podpůrný díl přilepte do drážky podle obrázku níže. Výřez v podpůrném dílu přisuňte k hraně s kabelem. 



Po zaschnutí lepidla na podpůrném dílu odlepte krycí fólii na zadní straně LED pásku. 



LED pásek nalepte na podpůrný díl podle obrázku:



Pod vystupující kabely LED pásku naneste kapku z tavné pistole. Kabely do ní vmáčkněte:



Nechte zchládnout.

Do vzniklého prostoru vložte plochý kabel. **POZOR! orientace kabelu musí být přesně taková, jako je na obrázku.** Zkontrolujte si, že máte na stejné pozici červený pás na kabelu i stejně orientované konektory.



V horní části dílu s otvory pro matky udělejte z vnitřní (nepohledové) strany výřez pro vyvedení kabelů: 



Naneste lepidlo na úzké části:



Přilepte poslední díl krku.



<!-- _________________________________________________________________ -->
# <a name = krabice>Slepení krabičky</a>

## Potřebujeme:
* Všechny díly krabice kromě spodního
* Lepidlo Herkules
* Papírová páska



## Dobrá rada pro lepení:
Nanášejte vždy odpovídající množství lepidla. 



Pokud vám lepidlo po stlačení dílů vyteče na pohledové hraně, otřete ho papírovým ubrouskem směrem ven z krabice, nikdy směrem dovnitř.



## Postup:
Slepte "ohrádku" ze zadní, přední, levé a pravé stěny krabičky. Zalepte první spoj, lepidlo naneste na všechny plochy, které se spojí. Slepený spoj poté stáhněte kusem papírové pásky o délce cca 5 cm. Pro držení tvaru je možné použít horní díl, zatím ho nelepte. Dávejte pozor, abyste správně nalepili díl, kde je díra na USB konektor (viz fotky níže).





Stejně slepte i další rohy.

Před přilepením horního dílu se ujistěte, že je správně otočený - široká členitá díra má být u té strany krabice, kde je díra na USB konektor.



Přilepený díl zajistěte na cca 4 místech páskou. Ujistěte se, že nejsou nikde mezery mezi díly. Pokud ano, vedoucí vám pomůže.

Případné nedořezy ve členitém otvoru spravte pomocí nože nebo hrubého (žlutého) brusného papíru. 

Zkuste do otvoru vsadit tištěný díl s pantem podle obrázku:



Pokud je možné bez problémů díl vsunout do krabičky, můžete pokračovat k dalšímu kroku.

<!-- _________________________________________________________________ -->
# <a name = hexagony>Sestavení části s hexagony</a>

## Potřebujeme:
* Překližka s šestiúhleníkovými výřezy
* 4 rohové díly s šestihrannými otvory
* 4 rohové díly s kruhovými otvory
* Jemný brusný papír (černý)
* Lepilo Herkules
* 2 tooly na lepení rohových dílů



## Postup: 
Dřevo s šestiúhleníkovými výřezy položte pohledovou stranou dolů. S pomocí tištěného toolu přilepte do rohu desky dílek s šestiúhleníkovým otvorem na matku. Všechny hrany musí být v jedné rovině, jinak je nebude možné později vsadit do tištěného dílu. 

Dávejte pozor na pořadí lepených dílů, na velkou obdélníkovou část musí být přilepený díl, který má výřez na matku. 



Po zaschnutí lepidla na tento dílek přilepte rohový díl s kruhovým otvorem pro šroub, jak je ukázáno na obrázku:



Stejným způsobem přilepte i dílky ve zbývajících rozích. Výsledek:



<!-- _________________________________________________________________ -->
# <a name = lak1>Nanesení první vrstvy laku</a>

## Potřebujeme:
* Slepená krabička
* Spodní část krabice
* Slepený krk
* Slepená část s hexagony
* Štětec
* Kelímek s polyurethanovým lakem, kelímek s vodou pro odložení štětce
* Čistá odkládací plocha, obrácený hrníček na odložení krabice

## Postup: 
Ukliďte si do čista pracovní plochu a očistěte krabičku od prachu.  Jakýkoli nepořádek, který se na dřevo v této fázi přichytí, je velmi těžké odstranit. Štětcem naneste první vrstvu bezbarvého laku na horní stranu krabičky. 



Po zaschnutí naneste lak na další strany a nechte zaschnout. Laku nenanášejte velké množství, stékal by a vytvořil by kapky na okrajích dřeva. Nakloněním dílu proti světlu zkontrolujte, že máte lakem pokrytou cleou plochu. Stejným způsobem nalakujte i zbylé pohledové polochy. Lakované plochy se snažte co nejméně dotýkat.

Štětec po skončení práce odložte do kelímku s vodou, nesmí zatuhnout. Nechte lak dostatečně zaschnout.

Stejným způsobem nalakujte i složený díl krku. 



Nalakujte také spodní stranu krabičky. 



Lak nechte zaschnout. Tímto je lakování první vrstvy hotové. 

<!-- _________________________________________________________________ -->
# <a name = lak2>Nanesení druhé vrstvy laku</a>

## Potřebujeme:
* Slepená krabička
* Spodní část krabice
* Slepený krk
* Slepená část s hexagony
* Štětec
* Kelímek s polyurethanovým lakem, kelímek s vodou pro odložení štětce
* Čistá odkládací plocha, obrácený hrníček na odložení krabice
* Jemný (černý) smirek

## Postup:

Ověřte si, že je lak suchý. Když se dílu dotknete, nesmí lepit. 
Jemným smirkem zbruste lakované plochy. Vystoupla z nich na některých místech struktura dřeva, tu je potřeba zabrousit. Mělo by stačit jemné přejetí smirkem, nezbrušujte celou plochu. Dotekem kontrolujte, jestli už je dřevo hladké, přestaňte. 

**Důležité - osmirkované díly očistěte od pilin navlhčeným ubrouskem - výsledný povrch bude hladší.**

Ukliďte si do čista pracovní plochu. Jakýkoli nepořádek, který se na dřevo v této fázi přichytí, je velmi těžké odstranit.

Naneste druhou vrstvu laku. Štětec po dokončení práce odlože do kelímku s vodou.

Nalakujte díly druhou vrstvou laku. Pokryjte všechny pohledové plochy a přilehlé hrany. Když díl nakloníte, v odlesku uvidíte, jeslti je pokrytá celá plocha. Lakované plochy se snažte co nejméně dotýkat.

Nechte lak dostatečně zaschnout.

<!-- _________________________________________________________________ -->
# <a name = spodek>Sestavení podstavy</a>

## Potřebujeme:
* Slepená nalakovaná krabička
* Zasádrovaný díl
* Spodní část krabičky
* 3D tištěný držák konstrukce
* Část spodního kloubu se širokou podstavou
* Hlavní PCB 
* Sestava krku
* Menší 3D tištěný kruhový kryt fotorezistoru
* Větší 3D tištěná plocha kapacitního tlačítka
* 1x šroub M3x8 
* 2x šroub M3x12
* 2x šroub M3x16
* 4x šroub M3x30
* 9x matice M3
* 4x podložka M3
* 4x gumová nožička
* Lepidlo Pattex



## Postup:
Do otvorů v 3D tištěném držáku konstrukce vsuňte matky. 



V případě, že matku nejde vložit snadno, použijte k jejímu zatlačení do otvoru šroubovák.



Výsledný díl bude vypadat takto:



**Důležité:**
Dalším krokem je vsazení matek do části spodního kloubu se širokou podstavou. Na tento krok nezapomeňte, protože to jinak se to bude muset celé rozmontovat :-)

Na bok matky naneste malé množství lepidla a vsuňte ji do prostředního otvoru.





Stejným způsobem vložte matky s kapkou lepidla i do bočních otvorů. 



V případě, že je matku obtížné vsunout, pomozte si nějakým nástrojem. 



Lepidlo nechte chvíli zatvrdnout, aby matky nevypadly. Dalším krokem je prostrčení šedého kabelu shora do krabičky podle obrázku:



Shora do krabičky zasuňte 3D tištěný díl kloubu se širokou podstavou podle obrázku:



Dalším krokem je vložení držáku konstrukce do krabičky, širší stranou ke členitému otvoru v krabičce - podle obrázku:



Nyní šroubem M3x8 (nejkratší z připravených pro tento krok) sešroubujte díl vnitřní konstrukce s dílem kloubu podle obrázku:



Flex kabel vedoucí do krabice přehněte podle obrázku a lehce přehyby zmáčkněte prsty, aby kabel držel požadovaný tvar. To je důležité pro to, aby se kabel dal připojit k základové desce. Šroubovák na fotce je jen kvůli přidržení kabelu na fotku. 



Nyní si připravte hlavní PCB s připájeným fotorezistorem. Ten zahněte do pravého úhlu směrem ven z desky, nezahýbejte ho však hned nad deskou, ale s malým odstupem od desky, aby se jeho vývody nezlomily. 



Konektor přehnutého kabelu zasuňte do hlavní desky podle obrázku:



Připravte si červeno-černý dvoužilový kabel s konektorem a napájenými měděnými ploškami. Dále si připravte plastový díl kapacitního tlačítka (kruhový plastový díl s **větším** průměrem). Přiložte menší měděnou plošku od červeného kabelu z vnitřní strany k plastovém dílu a zastřihněte její rohy tak, aby se vešla dovnitř.



Odlepte krycí fólii této zastřižené plošky a nalepte ji dovnitř plastového dílu.



Na okraj kapacitního tlačítka naneste malé množství lepidla na plasty Pattex. Konektor protáhněte otvorem a tlačítko vmáčkněte **zvěnčí** do připraveného otvoru, případné vyteklé lepidlo otřete papírovým ubrouskem.



Plošku tlačítka zarovnejte s plochou dřeva, jak je ukázání na obrázku:



Po zaschnutí lepidla na plasty naneste do vnitřku kapacitního tlačítka kapku z tavné pistole, aby byl spoj mezi měděnou ploškou a plastovým tělem tlačítka spolehlivější. Nechte zchládnout. 

Po obvodu menšího 3D tištěného kruhového krytu fotorezistoru naneste malé množství lepidla Pattex a opět jej vmáčkněte z vnější strany krabičky dovnitř a zarovnejte plošku krytky s plochou dřeva. 



Černý kabel s měděnou ploškou umístěte libovolně po obvodu nebo vrchní straně krabičky. Tím vytvoříte vaše *tajné* tlačítko. 

Ohnutý flex kabel a kabel kapacitních tlačítek připojte k hlavní PCB:



PCB vsuňte do krabičky tak, že nejprve nasunete fotorezistor do připraveného otvoru vedle otvoru pro USB a desku *"položíte"* dovnitř. 

Nyní si připravte 4 kusy podložky M3 a dvě dvojice šroubů M3x12 a M3x16. Na každý šroub navlečte podložku. Kratšími šrouby nejprve zašroubujte zadní okraj desky (okraj dále od USB konektoru). Šrouby zatím neutahujte napevno. Zbylými dvěma delšími šrouby (M3x16) přišroubujte desku ve zbylých místech. Pokud se šrouby protáčí a nejde je zašroubovat, asi jste zapomněli vložit matky :-/.

Nyní si připravte 4 šrouby M3x30, 4 gumové nožičky, díl vylitý sádrou a spodní díl krabičky.



Gumové podložky navlečte na šrouby. 



Nyní všechny šrouby protáhněte skrz spodní díl krabičky a sádrový výlitek tak, aby otvor v dřevěném dílu lícoval s otvorem v sádrovém výlitku. 



Sádrový výlitek má na jedné kratší straně zkosení kvůli fotorezistoru. Dřevěné dno se sádrovým výlitkem otočte zkosením k fotorezistoru. 

Spodní díl krabičky zatím nešroubujte k kornímu dílu, pouze jej přitlačte. Pokud se vám některá nožička součástky obtiskla do sádry, vyškrábněte v tomto místě sádru a udělejte tak místo pro nožičku/nožičky. 



Tímto je spodek lampy sestavený. 

<!-- _________________________________________________________________ -->
# <a name = spodnikloub>Sestavení spodního kloubu</a>

## Potřebujeme:
* 2 tištěné díly spodního kloubu (jeden se zoubky a protikus)
* 1 šroub M3x25
* 1 samojistná matka (s gumovým kroužkem uvnitř)
* 2 šrouby M3x12 se zápustnou hlavou 
* 2 matky M3
* 1 gumový O-kroužek

## Postup:
Vyšroubujte 2 šrouby M3x12 ze spodní části krku. Šrouby vyjměte i s matkami a následně vyjmětě plastové díly z krku.
Zkontrolujte, že máte správné plastové díly - spodní kloub je z jedné strany tvořen zoubky. K němu najděte protikus, jehož zámečky do něj zapadají. Pokud nemáte správné, vyměňte je s díly z horní části krku.

Na díl s kruhovou drážkou nasaďte jeden z O-kroužků podle obrázku. 



Díl přitiskněte k dílu kloubu, který je již přištoubován v podtavci, viz obrázek níže:



Protikus se zoubky přilož k podstavcovému dílu z druhé strany, jak je ukázáno na obrázku tak, aby zoubky zapadly do sebe:



Nyní otáčením dílku s O-kroužkem zacvakni zámečky na dílech do sebe. Kloub by nyní měl vypadat takto:



Do dílku, ve kterém je šestiúhleníkový otvor vlož samojistnou matku. Šroub M3x25 prošroubuj z druhé strany a lehce dotáhni v matce. 



Slepený díl krku nyní nasuň na plastový kloub, který jsme právě vytvořili:



Do šestiúhleníkových otvorů ve dřevě nyní vlož 2 obyčejné matky M3, které jsme dříve vyjmuli. 



Ty teď z druhé strany je zašroubuj dvěma šrouby M3x12, které jsme dříve vyjmuli.



<!-- _________________________________________________________________ -->
# <a name = hornidil>Sestavení horního dílu</a>

## Potřebujeme:
* PCB s LEDkami
* 2 tenké 3D tištěné držáčky PCB
* 3D tištěný držák dřevěného dílu vrchu (na obrázku níže)
* složený dřevěný díl s šestiúhleníkovými otvory a rohovými držáky matek
* Vnější 3D tištěný díl s kloubem
* Držák plexiskla
* Plexisklo
* 4 šrouby M3x12 se zápustnou hlavou
* 4 šrouby M3x20 se zápustnou hlavou
* 8 matek M3 
* Úzkou tištěnou sponu na kabely
* Krytku konektoru
* Lepidlo Herkules
* Lepidlo Pattex



## Postup:
Šedý flex kabel a tři barevné dráty vedoucí k LED pásku secvakněte pomocí tištěné spony podle obrázku níže:



Konektor flex kabelu provlečte krytkou konektoru, která je na obrázku níže. Krytku neche volně na kabelu, ten poté připojte a následně krytku přetáhněte přes spojené konektory. Krytka je zde kvůli tomu, aby se při velkém otočení krku lampy konektory nerozpojily.



Konektor LED pásku připojte k PCB s diodami:



Oběma otvory tenkého tištěného držáčku PCB protáhněte šrouby M3x12 se zápustnou hlavou podle obrázku:



Držáčky nyní nasaďte na PCB ze strany LED diod tak, aby výstupky na držáčcích směřovaly směrem *dovnitř* k LED diodám. Nyní na PCB nasaďte 3D tištěný držák dřevěného dílu tak, jak je zobrazeno na obrázku níže, tedy drážkou tak, aby jí prošly kabely:





Pozn.: Na předchozích obrázcích není na spojení černých konektorů nasazená krytka, my ji tam ale správně máme :-). 

Nyní do otvorů v rozích dřevěného slepeného dílu vložte 4 matky. Na každou z nich naneste trochu lepidla a nechte jej zaschnout.



Dřevěný díl s vlepenými matičkami vložte na plastový díl podle obrázku níže a zašroubujte šrouby do matiček:



Nyní si připravte: 
* Vnější 3D tištěný díl s kloubem
* Zbylou dvojici pantů
* Plexisklo
* Držák plexiskla
* 4 matky M3
* 4 šrouby M3x20
* 1 šroub M3x25
* Samojistnou matku



Do otvorů ve vnějším tištěném dílu s kloubem vložte 4 matky M3 a pojistěte je proti vypadnutí kapkou lepidla Pattex. Při vsazování do otvorů si můžete pomoct kleštěmi. 



Lepidlo nechte zaschnout.

Plexisklo vsaďte do držáku plexiskla tak, aby držák plexiskla byl hladkou stranou směrem dolů a plexisklo leželo shora. 



Tento díl nyní nasuňte zespodu na dříve složenou část plexisklem k diodám a výřezem ke kabelu podle obrázku:





Díly k sobě stlačte podle obrázku:



Na takto složený vrch lampy nyní shora nasuňte vnější díl s výstupkem kloubu:



Nasazený díl zatlačte tak, aby byla jeho hrana zarovnaná s povrchem dřeva.

Celý díl sešroubujte čtyřmi šrouby M3x20:



<!-- _________________________________________________________________ -->
# <a name = hornikloub>Sestavení horního kloubu</a>

## Potřebujeme:
* 2 tištěné díly horního kloubu (zbylé)
* 1 šroub M3x25
* 1 samojistná matka (s gumovým kroužkem uvnitř)
* 2 gumové O-kroužky

Vyšroubujte 2 šrouby M3x12 z horní části krku. Šrouby vyjměte i s matkami a následně vyjmětě plastové díly z krku.

Vložte jeden O-kroužek mezi výstup z vršku lampy a boční díl kloubu. 



Stejným způsobem vložte druhý O-kroužek na druhé straně a otáčením jedním z bočních dílků zacvakněte zámečky do sebe.





Do šestiúhleníkového otvoru vložte samojistnou matku a celý kloub prošroubujte šroubem M3x25. 



Stejně jako při stavbě spodního kloubu, vsuňte plastový díl do drážky v dřevěném krku lampy. 



Do šestiúhelníkových otvorů ze spodní strany krku vložte dvě dříve vyjmuté matky M3 a z druhé strany je přišroubujte dříve vyjmutými šrouby M3x12 se zápustnou hlavou, stejně jako na spodní straně krku.

V případě potřeby dotáhněte / povolte šrouby v kloubech.

<!-- _________________________________________________________________ -->
# <a name = finalizace>Finalizace</a>

Natočte potenciometr úplně doleva (na minimum). Přiložte krytku potenciometru tak, aby její značka byla vlevo dole.



Nasaďte takto natočenou krytku na potenciometr a zatlačte tak, aby se na něj zasunula až na doraz.



Gratulujeme - tímto je mechanická stavba hotová :-).

<!-- _________________________________________________________________ -->
# <a name = spojovacimaterial>Příloha: Seznam spojovacího materiálu</a>

1. Šroub M3x30 s kulatou hlavou: 4
1. Šroub M3x25 s kulatou hlavou: 2
1. Šroub M3x20 se zápustnou hlavou: 4
1. Šroub M3x16 s kulatou hlavou: 2
1. Šroub M3x12 s kulatou hlavou: 2
1. Šroub M3x12 se zápustnou hlavou: 8
1. Šroub M3x8 s kulatou hlavou: 1
1. Matice M3: 21
1. Samojistná matice M3: 2
1. Podložka M3: 4



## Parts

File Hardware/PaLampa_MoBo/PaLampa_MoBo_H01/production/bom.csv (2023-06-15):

Designator | Footprint | Quantity | Value | LCSC Part #
BZ1 | Buzzer_12x9.5RM6.6 | 1 | Buzzer
C1, C12, C16, C18, C22, C4, C5, C6, C7 | 0603 | 9 | 100n | C14663
C10, C20, C8, C9 | 1206 | 4 | 10u/50V | C13585
C11, C19 | CP_Radial_D5.0mm_P2.00mm | 2 | 100u | C43348
C13, C21 | 0603 | 2 | 10u | C19702
C14, C2 | 0805 | 2 | 10u | C15850
C15, C17, C3 | 0603 | 3 | 1u | C15849
D1, D2 | D_SOD-123 | 2 | B5819W | C8598
D3 | D_MiniMELF | 1 | 3V3 | C8056
D4 | D_MiniMELF | 1 | 5V6 | C8062
D5, D6 | D_SMA | 2 | SS54 | C22452
J2 | IDC-Header_2x04_P2.54mm_Vertical | 1 | Conn_02x04_Odd_Even
J3 | JST_XH_B2B-XH-A_1x02_P2.50mm_Vertical | 1 | Conn_01x02
J7 | USB_C_Receptacle_HRO_TYPE-C-31-M-12 | 1 | 918-418K2023S40001 | C167321
J9 | PinHeader_1x05_P2.54mm_Vertical | 1 | Conn_01x05_Male
L1, L2 | L_Cenker_CKCS5040 | 2 | 6u8 | C354608
Q1, Q4, Q5 | SOT-23 | 3 | 2N7002 | C8545
Q2, Q3 | SOT-23 | 2 | S8050 | C2146
R1, R13, R15, R18, R19, R2, R6, R7 | 0603 | 8 | 10K | C25804
R10, R11 | 0603 | 2 | 12K | C22790
R12, R14 | R_LDR_5.1x4.3mm_P3.4mm_Vertical | 2 | R_Photo
R16, R17 | 0603 | 2 | 1K | C21190
R21, R22 | 0603 | 2 | 100K | C25803
R3 | 0603 | 1 | 4K7 | C23162
R4, R5 | 1206 | 2 | 820m | C175854
R8, R9 | 0603 | 2 | 470R | C23179
RESET1 | SW_SPST_TL3342 | 1 | SW_SPST | C318884
RV1 | Potentiometer_Alps_RK09K_Single_Vertical | 1 | R_Potentiometer
SW1, SW2, SW3 | SW_PUSH_6mm_H13mm | 3 | SW_SPST
U1 | ESP32-WROOM-32 | 1 | ESP32-WROOM-32D | C529577
U2 | TO-92_HandSolder | 1 | DS18B20
U3 | Display_128x64_096_I2C_3Hole | 1 | OLED_I2C
U4 | SOT-223-3_TabPin2 | 1 | AMS1117-3.3 | C6186
U5 | SOIC-16_3.9x9.9mm_P1.27mm | 1 | CH340G | C84681
U6, U7 | DFN-10-1EP_3x3mm_P0.5mm_EP1.75x2.6mm | 2 | SY7203 | C125894
U8 | WQFN-14-1EP_2.5x2.5mm_P0.5mm_EP1.45x1.45mm | 1 | FUSB302BMPX | C132291

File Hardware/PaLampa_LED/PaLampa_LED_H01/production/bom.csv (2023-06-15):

Designator | Footprint | Quantity | Value | LCSC Part #
C1, C2 | 0603 | 2 | 10uF | C19702
CW1, CW10, CW11, CW12, CW13, CW14, CW15, CW16, CW2, CW3, CW4, CW5, CW6, CW7, CW8, CW9 | HL-A-5730 | 16 | HL-A-5730D1W-S1-08-HR3(LY) | C210348
CWS1, CWS10, CWS11, CWS12, CWS13, CWS14, CWS15, CWS16, CWS2, CWS3, CWS4, CWS5, CWS6, CWS7, CWS8, CWS9 | 0402 | 16 | 100n | C1525
G1 | Coufal_elektronika_notext_10mm | 1 | CoufalElektronika_logo
G2 | VedatoriNew_40x5,7mm | 1 | Vedatori_logo
H1, H2, H3, H4 | MountingHole_3.2mm_M3 | 4 | MountingHole
J1 | IDC-Header_2x04_P2.54mm_Horizontal | 1 | Conn_02x04_Odd_Even
J2 | JST_XH_S3B-XH-A_1x03_P2.50mm_Horizontal | 1 | Conn_01x03
R1 | 0402 | 1 | 470R | C25117
R2 | 0402 | 1 | R | C25900
U1 | TO-92_Inline | 1 | DS18B20
WS1, WS10, WS11, WS12, WS13, WS14, WS15, WS16, WS2, WS3, WS4, WS5, WS6, WS7, WS8, WS9 | LED_WS2812B_PLCC4_5.0x5.0mm_P3.2mm | 16 | XL-5050RGBC-WS2812B | C2843785
WW1, WW10, WW11, WW12, WW13, WW14, WW15, WW16, WW2, WW3, WW4, WW5, WW6, WW7, WW8, WW9 | HL-A-5730 | 16 | HL-A-5730D34W-S1-08-HR3(LY) | C210345

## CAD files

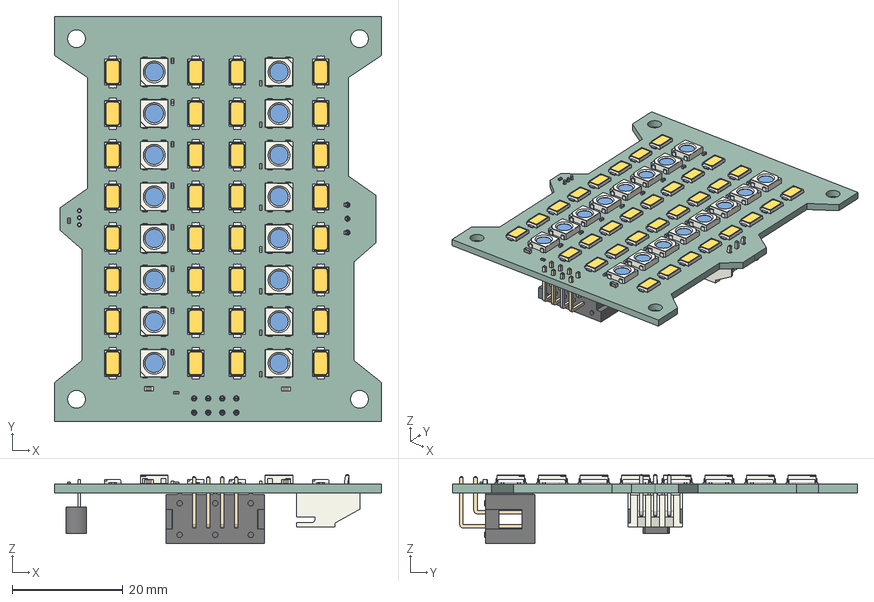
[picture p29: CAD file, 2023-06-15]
Hardware/PaLampa_LED/PaLampa_LED_H01/PaLampa_LED_H01.step
59.0 x 73.0 x 12.5 mm
PCB

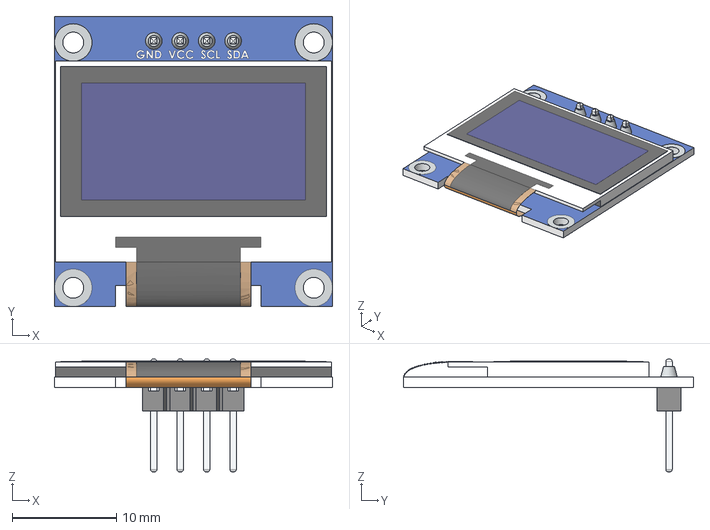
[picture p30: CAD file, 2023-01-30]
Hardware/PaLampa_Library/OLED-128x64-0.96.step
26.7 x 27.9 x 10.8 mm

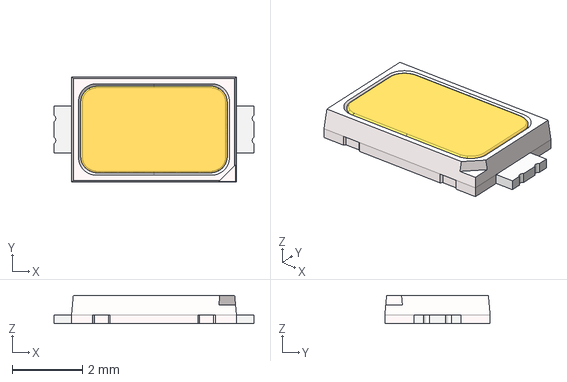
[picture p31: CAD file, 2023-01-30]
Hardware/PaLampa_Library/LED 5730.stp
5.70 x 3.00 x 0.8 mm

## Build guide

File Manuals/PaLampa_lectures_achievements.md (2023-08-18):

V tomto dokumentu se nachází rozpis programovacích lekcí a zadání programovacích úkolů. 

**Programovací lekce** nejsou povinné, ale jsou velmi vhodné pro začátečníky.

**Programovací úkoly** jsou úkoly, které budete řešit samostatně. Ke každému úkolu potřebujete soubor znalostí, který je obsažen v některých z lekcí.

# Lekce 0
Zprovozníme programovací prostředí VS Code + PlatformIO tak, abyste mohli nahrát kód do PaLampy z vašeho PC.

## Úkol 0 - Demo program
Nahrát do výrobku připravený demo program z PaLampa repozitáře.

# Lekce 1
Blikneme LED světlem ve funkci `setup` a budeme jím blikat ve funci `loop`.

## Výsledný kód

```cpp
#include "PaLampa/PaLampa.h"

void setup() {
    paLampa.begin();
    // id panelu, (0 = warm, 1 = cool)
    // brightness, (0-1)
    paLampa.lights.setWhite(0, 0.5);
    
    // delay(ms), 2000 ms = 5 s
    delay(2000);
    paLampa.lights.setWhite(0, 0.0);
}

void loop() {
    paLampa.lights.setWhite(1, 0.5);
    delay(500);
    paLampa.lights.setWhite(1, 0.0);
    delay(500);
}
```

## Úkol 1 - Rozsviť teplé ledky
Napište program, který každou vteřinu krátce rozsvítí teplé bíle ledky. Doba zobrazení je 250 ms v každé vteřině.

## Úkol 2 - Rozsviť studené a teplé ledky střídavě
Napište program, který bude blikat jako železniční přejezd. Blikat budou střídavě studené ledky, a teplé ledky v 500 ms intervalu.

# Lekce 2
Rozsviť barevné LED na horním a zadním segmentu.

## Výsledný kód
```cpp
#include "PaLampa/PaLampa.h"

void setup() {
    paLampa.begin();
    // panel, (0 = top, 1 = back)
    // id, (0-15 top, 0-6 back)
    // color, (red, blue ...)
    paLampa.lights.setColor(0, 0, red);
    paLampa.lights.setColor(1, 0, blue);
}

void loop() {
    paLampa.lights.setColorPanel(0, red);
    delay(500);
    paLampa.lights.setColorPanel(0, black);
    delay(500);
}
```

## Úkol 3 - Blikání LED
Napište program, který bude blikat třetí barevnou LED ze zadního segmentu červenou barvou. Doba svitu i doba zhasnutí je 300 ms.

## Úkol 4 - Železniční přejezd na horním segmentu
Napište program, který bude blikat jako železniční přejezd. Blikat budou LED 0 a 15 na horním panelu, oba červenou barvou.

## Úkol 5 - Noční jezdec
Napište program, který bude postupně rozvěcovat LED na zadním segmentu červenou barvou tak, že vždy svítí jen jedna LED a každá svítí 333 ms.

# Lekce 3
Přečteme stav tlačítka, ukážeme si binární proměnnou a v závislosti na ní rozesvítíme LED.

## Výsledný kód

```cpp
#include "PaLampa/PaLampa.h"

void setup() {
    paLampa.begin();
}

void loop() {
    // čísla tlačítek jsou zleva 0, 1, 2
    if(paLampa.buttonRead(0)) {
        paLampa.lights.setWhite(0, 0.1);
    }
    else {
        paLampa.lights.setWhite(0, 0);
    }
}
```

## Úkol 6 - Manuální blikání LED 
Napište program, který bliká libovolnou LED pouze při stisknutém pravém tlačítku. Doba svícení je 200 ms. Doba zhasnutí je 200 ms.

## Úkol 7 - Stabilní stav LED
Napište program, který bude stiskem tlačítka přepínat svícení dvou různých LED. Vždy bude svítit pouze jedena LED, stiskem tlačítka se jedna LED vypne a zapne se ta druhá. Dalším stiskem tlačítka se znovu zapne pouze ta původní LED a proces lze opakovat.

# Lekce 4
Přečteme stav potenciometru a zapíšeme ho do červeného kanálu na horním rgb panelu.

Vlastní rgb barvy si můžeme vytvořít pomocí ColorRGB{R, G, B}. Hodnoty R, G a B zaměňte za hodnoty 0-1 které chcete nastavit.

```cpp
#include "PaLampa/PaLampa.h"

void setup() {
    paLampa.begin();
}

void loop() {
    float potVal = paLampa.potentiometerRead();
    ColorRGB color = {potVal, 0, 0};
    paLampa.lights.setColorPanel(0, color);
    delay(100);
}
```

## Úkol 8 - Zesilování LED
Napište program, který bude regulovat jas teplé LED pomocí potenciometru.

## Úkol 9 - Barevný formát HSV
Napište program, který bude při otočení potenciometru postupně měnit barvy barevné LED.

# Lekce 5
Ukážeme si fotorezistor a hodnotu jeho výstupu si zobrazíme na LED.

```cpp
#include "PaLampa/PaLampa.h"

void setup() {
    paLampa.begin();
}

void loop() {
    float illumination = paLampa.photoresistor.get(1);
    paLampa.light.setWhite(0, illumination / 2);
}
```

## Úkol 10 - Světelná signaliazce tmy
Napište program, který zvýší jas pokud vstoupíme s PaLampou do tmy. Doporučuji dělit hodnotu z fotorezistoru číslem 3.

## Úkol 11 - Automatické světlo
Napište program, který upravuje svítivost LED podle okolního osvětlení. Čím temější prostředí tím víc bude lampa svítit, a čím světlejší tím bude lampa méně svítit. Doporučuji použít zadní fotorezistor.

# Lekce 6
Ukážeme si ja zjistit hodnotu teploměru a jak se pracuje se sériovou linkou

## Výsledný kód

```cpp
#include "PaLampa/PaLampa.h"

void setup() {
    paLampa.begin();
}

void loop() {
    float topTemp = paLampa.thermometer.get(1 /*0 = bottom, 1 = top*/);
    float bottomTemp = paLampa.thermometer.get(0);
    Serial.print("top = ");
    Serial.print(topTemp);
    Serial.print("°C, bottom = ");
    Serial.print(bottomTemp);
    Serial.println("°C");
    delay(500);
}

```

## Úkol 13 - Přehřívání 
Napište program, který bude hlídat teplotu horního segmentu za pomoci teploměru a když teplota přesáhne 30°C tak vypne LED světla.

## Úkol 14 - Teplota okolí 
Napište program, který bude hlídat teplotu zadního teploměru a podle ní bude měnit barvu RGB podle zadání. Modrá je pod 25°C, zelená je 25°C až 28°C, žlutá 28°C až 30°C, červená je 30°C plus.

# Lekce 7

Ukážeme si jak funguje dotykové tlačítko a funkce random();

```cpp
#include "PaLampa/PaLampa.h"

void setup()
{
    paLampa.begin();
}

void loop()
{
    paLampa.capButton.update(); // update hodnoty tlačítka.

    if(paLampa.capButton.getPadPressed(0/*id, (0 = upper, 1 = secret)*/)){
        //nastavíme celý led pásek na černou
        paLampa.lights.setColorPanel(1, black);
        //nastavíme náhodný pixel na červenou
        paLampa.lights.setColor(1, random(7), red);
        delay(500);
    }
    delay(20)
}
```

## Úkol 14 - Dotyk
Napiš program, který zapne a vypne jakoukoliv sadu LED pomocí horního dotykového tlačítka a pomocí vašeho tajného tlačítka změní barvu na náhodnou barvu pomocí funkce random.

# Lekce 8 
Ukážeme si jak rozeznít piezo.

## Výsledný kód

```cpp
#include "PaLampa/PaLampa.h"

void setup() {
    paLampa.begin();
    paLampa.piezo.begin(3, 13);
}

void loop() {
    if(paLampa.buttonRead(0)) {
        paLampa.piezo.tone(100);
    }
    else {
        paLampa.piezo.stop();
    }
    delay(20);
}
```

## Úkol 15 - Dlouhé pííp
Napište program, který po stisknutí horního kapacitního tlačítka rozezní piezo tónem komorní a (a', A4). Zvuk je vypnut až po stisknutí tajného kapacitního tlačítka.

## Úkol 16 - Základní melodie
Napište program, který na piezu přehraje krátkou melodii po stisknutí libovolného tlačítka.

# Lekce 9 
Ukážeme si jak ovládat obrazovku.

PaLampa ještě nemá hotové funkce na displej = tato lekce nelze udělat.

## Výsledný kód

```cpp
#include "ToMat/ToMat.h"

void setup() {
    ToMat.begin();
}

void loop() {
    ToMat.display.setLED(0, 5, blue);
    delay(500);

    ToMat.display.setLED(0, 5, black);
    delay(500);    
}
```

## Úkol 17 - TEXT 
Zobrazte na displeji libovolný krátký text.

## Úkol 18 - Tvar 
Zobrazte na displeji čtverec.

## Úkol 19 - Obrázek 
Zobrazte na displeji obrázek libovolného výběru.

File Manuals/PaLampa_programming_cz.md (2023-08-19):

Toto je návod na programování výrobku PaLampa. Začneme instalací vývojového prostředí na váš PC, následně si ukážeme základní pravidla programovacího jazyka C++ a poté začneme využívat funkce výrobku PaLampa.

V tomto návodu se budeme zabývat programováním mikrokontroléru (mikropočítače) ESP32. K tomu je od výrobce ESP32 připraven framework (sada nástrojů urychlujících vývoj) ESP-IDF v jazyce C. Nadstavbou tohoto frameworku je další framework [arduino-esp32](https://github.com/espressif/arduino-esp32), který přidává další sadu nástrojů a je již napsán v jazyce C++. Framework Arduino-esp32 používáme pro programování výrobku PaLampa. Bylo k němu potřeba přidat množství kódu (knihovna *PaLampa*), který se stará o *základní životní funkce* a umožňuje jednodušší používání jeho funkcionalit (z `main.cpp`). V tomto návodě se budeme zabývat jen uživatelským pohledem na používání knihovny *PaLampa*.

___
# Obsah

* [Vývojové prostředí](#IDE)
* [Nahrání demo programu - kontrola](#kontrola)
* [Ovládání demo programu](#ovladani)
* [Nový projekt](#novyprojekt)
* [První program](#prvniprogram)
* [Komentáře](#komentare)
* [Proměnné](#promenne)
* [Podmínky](#podminky)
* [Cyklus](#cyklus)
* [Funkce](#funkce)
* [LEDky](#ledky)
* [Tlačítka](#tlacitka)
* [Kapacitní tlačítka](#kapacitní-tlačítka)
* [Piezoakustický měnič](#piezo)
* [Fotorezistory](#fotorezistory)
* [Dotyková lišta](#lista)
* [Teploměr](#teplomer)
* [Sériová linka](#seriovka)
* [Pokročilé ovládání LED](#ledky2)
* [Obrazovka](#obrazovka)
* [WiFi](#wifi)
* [Vzdálený příkazový řádek](#prikazy)
___

<!-- _________________________________________________________________ -->
# <a name = IDE>Vývojové prostředí</a>

Pro programování PaLampa je použito vývojové prostředí [Visual Studio Code](https://code.visualstudio.com/download) s rozšířením PlatformIO. Pro instalaci prostředí a rozšíření můžete použít tento [návod](https://docs.platformio.org/en/latest/ide/vscode.html#installation), jehož hlavní část je na obrázku níže:

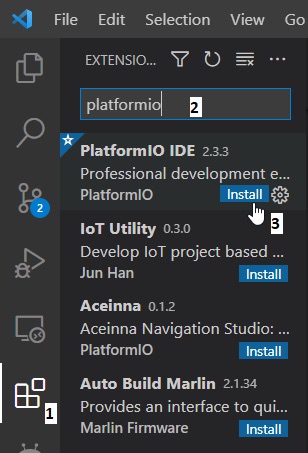
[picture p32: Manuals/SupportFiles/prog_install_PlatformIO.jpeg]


<!-- _________________________________________________________________ -->
# <a name = kontrola>Nahrání demo programu - kontrola</a>

V této části nahrajete do PaLampa připravený program pro jeho otestování a poskytující základní funkcí výrobku.

Pro naprogramování výrobku je potřeba si stáhnout knihovnu s připraveným software. Toho je možné dosáhnout dvěma způsoby. 
* Jednodušším způsobem je stažení [tohoto repozitáře](https://github.com/vedatori/PaLampa/archive/refs/heads/main.zip). Stáhnutý soubor *PaLampa-main.zip* si rozbalte na disk svého PC na libovolnou lokaci tak, abyste ho našli. Tento způsob má však z dlouhodobějšího hlediska nevýhody jako náročnější aktualizaci software a nemožnost kooperace ve vývoji.
* Složitějším způsobem je použití programu [Github Desktop](https://desktop.github.com) případně jiného Git klienta. Po instalaci Github Desktop si zkopírujte [URL adresu tohoto repozitáře ve webovém prohlížeči](https://github.com/Vedatori/PaLampa/). Po stisku tlačítek *Add*, *Clone repository* a *URL* zadejte do Github Desktop zkopírovanou adresu a potvrďte klonování repozitáře na váš lokální disk, nejlépe do nabízené souborové cesty.

**Pozor:** PlatformIO nedokáže pracovat s diakritikou v cestě souborového systému k projektu. Všechny projekty musí být uloženy v cestě bez háčků a čárek!
Pokud vaše uživatelské jméno obsahuje diakritiku, tak nemůžete používat Plochu ani složku Dokumenty, ale musíte vytvořit například *C:/Vedatori/PaLampa-main*.

Ve VS Code otevřete nabídku *File*, klikněte na *Open Folder* a zvolte složku *Software/demo_project* ze stažené složky-repozitáře *PaLampa*.

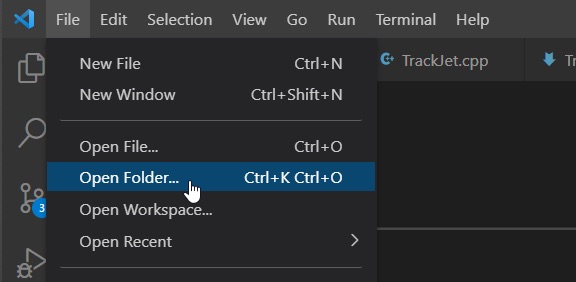
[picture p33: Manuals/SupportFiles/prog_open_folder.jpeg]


Otevřete soubor *main.cpp* který je v cestě *demo_project/src/main.cpp*.

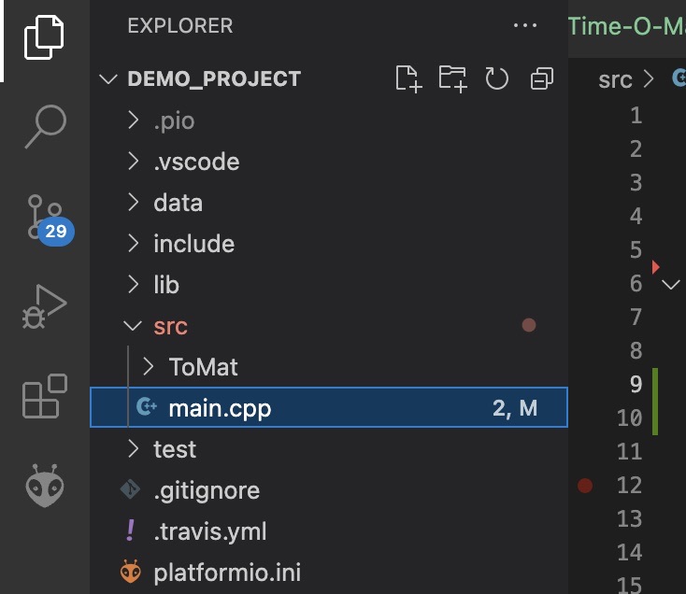
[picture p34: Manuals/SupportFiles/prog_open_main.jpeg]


V souboru *main.cpp* upravte název výrobku "<your_name>" tak, aby byl poznatelný, např. jako "Jirka" nebo "Blanka".
Je možné přidat i heslo pro přihlašování např. takto
`paLampa.startWiFiCaptain("<your_name>", "12345678");`.
Heslo musí mít minimálně 8 znaků, jinak nebude použito.

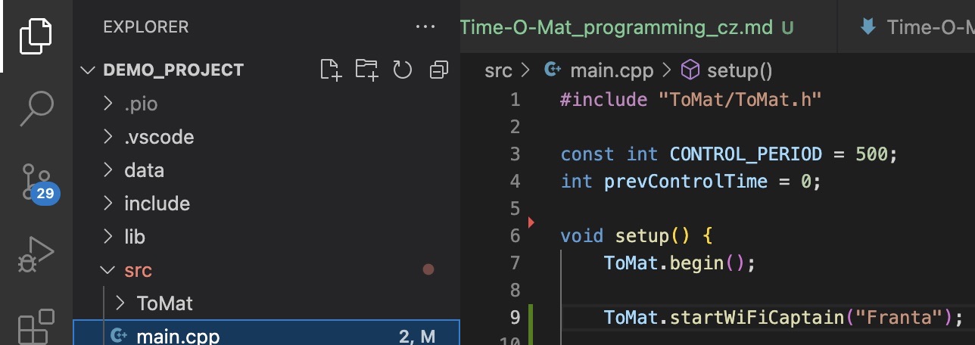
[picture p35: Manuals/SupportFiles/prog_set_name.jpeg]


Po otevření projektu bude VS Code chvíli pracovat. Pokud ještě pracuje, počkejte, dokud text na dolní liště nezmizí.



Připojte PaLampa pomocí USB-C kabelu k PC.

V dolní liště PlatformIO stiskněte šipku a tím nahrejte program do výrobku.



Počkejte, až se dokončí nahrávání a zobrazí v dolním terminálu *SUCCESS*.

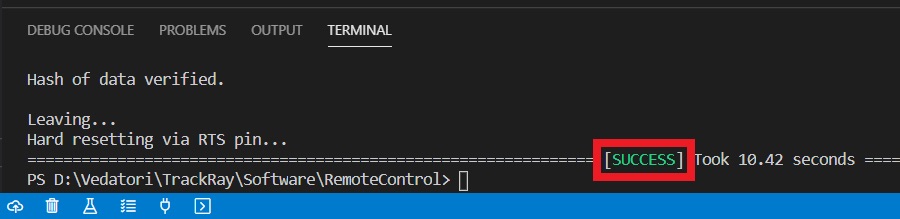
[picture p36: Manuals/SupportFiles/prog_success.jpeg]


V dolní liště PlatformIO stiskněte tlačítko úplně v pravo a tím spusťe PlatformIO terminál.

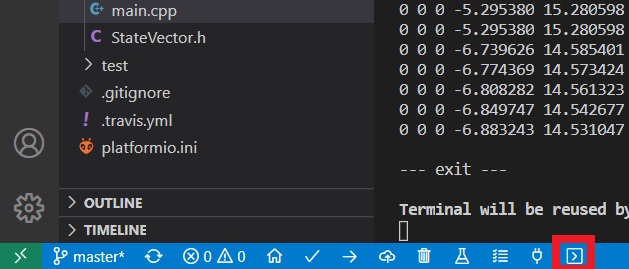
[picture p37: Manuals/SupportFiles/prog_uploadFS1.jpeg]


Do nově otevřeného termínálu v dolní částí VS Code zadejte příkaz `pio run -t uploadfs` a stiskněte *ENTER*. Tímto nahrajeme soubory webových stránek hostovaných ve výrobku pro jeho ovládání a další potřebné soubory.

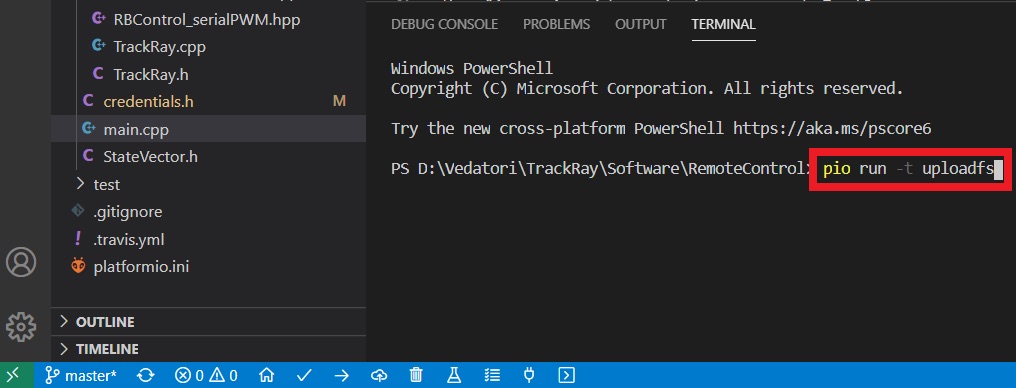
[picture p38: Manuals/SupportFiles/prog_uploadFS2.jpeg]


Počkejte, až se dokončí nahrávání a zobrazí v dolním terminálu *SUCCESS*.



Nyní je výrobek plně naprogramován. Pro ovládání na svém chytrém zařízení vyhledejte WiFi síť s názvem *PaLampa_<your_name>*. Zadejte do webového prohlížeče adresu *192.168.4.1* nebo jakoukoli jinou ve tvaru *www.neco.cz*. Načte se hlavní stránka pro ovládání PaLampa.

Pro přihlášení PaLampa k externí WiFi síti klikněte na tlačítko *WiFi setup*. Po delší chvíli se zobrazí stránka s dostupnými WiFi sítěmi. Zde zadejte přihlašovací údaje od externí WiFi a potvrďte přihlášení. Pro úspěšné přihlášení k externí WiFi síti může být potřeba ještě restart výrobku.

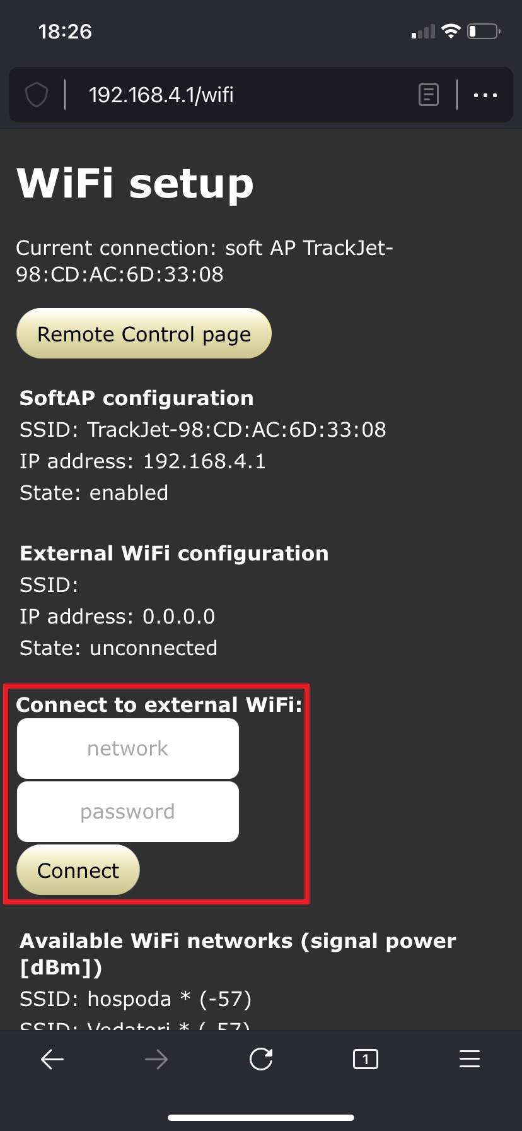
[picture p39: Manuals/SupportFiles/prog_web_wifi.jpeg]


Pokud přihlášení k externí WiFi proběhne úspěšně, objeví se potvrzení *connected* a přidělená IP adresa. Tato síť bude uložena a vyhledána i po restartu. Připojte se se svým chytrým zařízením také na externí WiFi a zadejte do prohlížeče IP adresu přidělenou PaLampa. V tomto případě *192.168.88.197*.

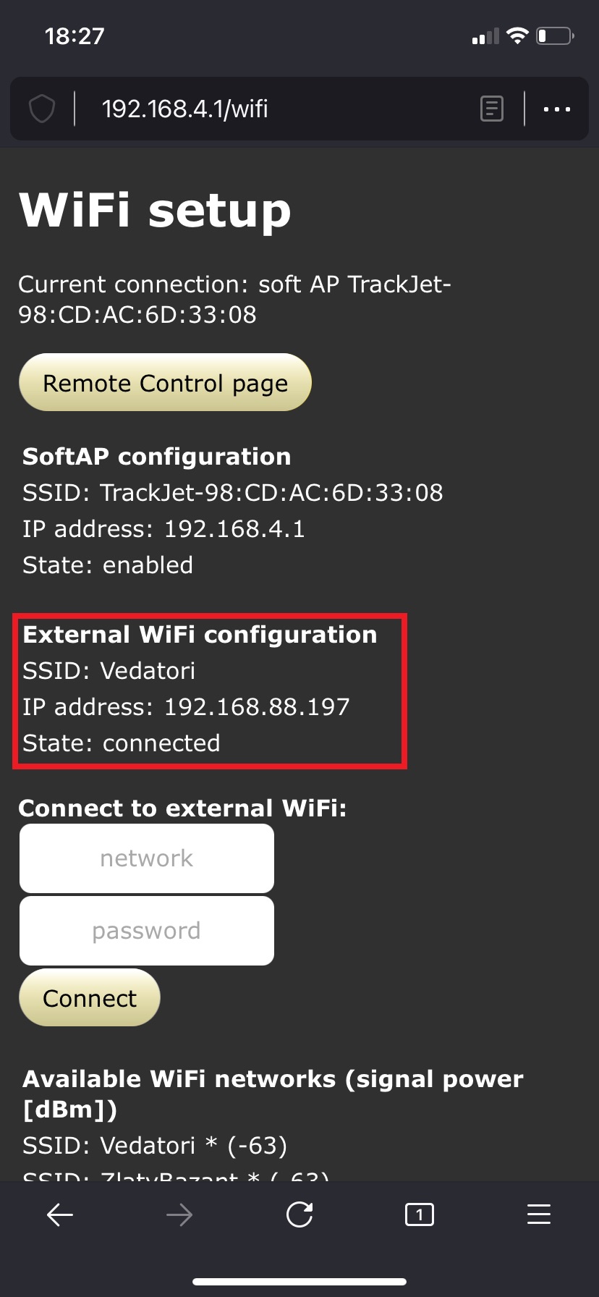
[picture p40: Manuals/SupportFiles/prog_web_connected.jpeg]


Načte se opět hlavní stránka ovládání PaLampa. Po několika minutách bez připojeného zařízení na interní WiFi síťi *PaLampa_<your_name>* bude tato síť vypnuta. Pro její opětovné zapnutí přejděte do nastavení WiFi a klikněte na tlačítko *Enable AP* nebo restartujte PaLampa.

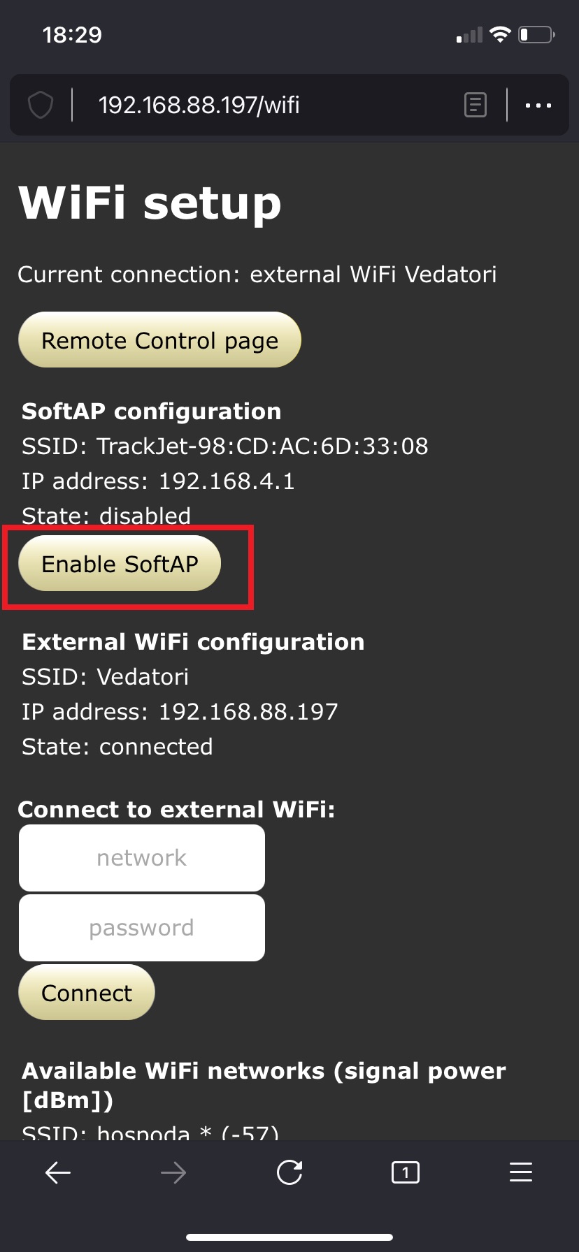
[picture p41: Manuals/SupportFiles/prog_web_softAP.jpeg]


Demo program umožňuje také následující nastavení výrobku:
* Nastavení jasu a barvy světla pomocí tlačítek a potenciometru.

<!-- _________________________________________________________________ -->
# <a name = ovladani>Ovládání demo programu</a>

Výrobek je možné skrze právě nahraný demo program uživatelsky ovládat a nastavovat jeho parametry. Jedná se o uživatelské funkce PaLampa SW knihovny, které jsou zpravidla nastaveny v hlavním souboru *main.cpp*. Zde je také možné je jednoduše měnit a přizpůsobovat si funkčnost PaLavýrobkumpa. Demo program je možné ovládat násedujícími způsoby:

## Fyzická tlačítka a dotyková lišta
* Nastavení jasu světla:
* Nastavení barvy světla:
* Nastavení času:
* Zahrání táborové znělky: Stiskem ______ spustíme demo skladbu *We are not going to make it*.
* Reset:

## Webové rozhraní
* Nastavení času: Do pole *Command entry* zadáme příkaz je ve tvaru `settime HH MM`. Parametry `HH` a `MM` odpovídají hodinám a minutám. Například pro nastavení času 12:34 použijeme příkaz `settime 12 34`. Příkaz odešleme stiskem tlačítka *Enter*.
* Nastavení časové zóny: Do pole *Command entry* zadáme příkaz je ve tvaru `setzone X`. Parametr `X` je textový řetězec (kód) popisující danou časovou zónu. [Seznam časových zón a jejich kódů je zde](https://github.com/nayarsystems/posix_tz_db/blob/master/zones.csv). Například pro nastavení české časové zóny včetně časových posuvů použijeme příkaz `setzone CET-1CEST,M3.5.0,M10.5.0/3`. Změna času po úspěšné změně časové zóny se za dostupného internetu projeví okamžitě. Pozor, v případě zadání nesprávného kódu časové zóny bude automatická sychronizace času vypnuta (neprobíhá kontrola validnosti zadaného kódu).
* Nastavení barvy světla: Do pole *Command entry* zadáme příkaz je ve tvaru `rgb R G B`. Parametry `R`, `G` a `B` odpovídají jednotlivým hodnotám RGB kódu zvolené barvy v rozsahu 0-255. Například pro nastavení zelené barvy použijeme příkaz `rgb 0 255 0`. Příkaz odešleme stiskem tlačítka *Enter*.

<!-- _________________________________________________________________ -->
# <a name = novyprojekt>Nový projekt</a>

Vytvoříme nový projekt a nahrajeme program do PaLampa.

## Postup
Vytvořte si na disku svého PC složku pro vaše budoucí programy, například *C:/user/Dokumenty/PaLampa-programy*.

Do této nové složky překopírujte soubor ze stáhnutého repozitáře *Software/demo_project/src/main.cpp* ze stáhnutého repozitáře *PaLampa-main*. V nové složec si soubor přejmenujte třeba na *original.cpp*. Tento soubor bude obsahovat původně poskytnutý kód pro výrobek, přesněji jeho hlavní, uživatelskou část v *main.cpp*. Podobným způsobem si budete ukládat další své vlastní programy, vždy jako nový textový soubor *nazev_programu.cpp" v nově vytvořené složce. Pro práci na daném programu a jeho nahrání do výrobku si obsah daného textového souboru překopírujete do *main.cpp* ve stáhnutém repozitáři. 

Ve VS Code otevřete soubor *main.cpp* ve stáhnutém repozitáři a nahraďte jeho obsah následujícím kódem šablony:
```cpp
#include "PaLampa/PaLampa.h"

void setup() {
    paLampa.begin();
}

void loop() {
    
}
```
Jednotlivé řádky šablony mají následující význam:
* `#include "PaLampa/PaLampa.h"` - Příkaz *#include* přidává do našeho programu kód z jiných míst. Nyní nám stačí přidání knihovny *PaLampa.h* ze složky PaLampa.
* `void setup() {}` - Toto je definice funkce. Funkce jsou kusy kódu, které můžete opakovaně spustit tak, že zavoláte jejich jméno. Kód (tělo) funkce je ohraničen složenými závorkami { a }, a mezi nimi odsazen. Tato funkce se jmenuje *setup* a je spuštěna jedenkrát po zapnutí PaLampa. O to se postará arduino-esp32 framework.
* `paLampa.begin();` - Toto je volání funkce z knihovny *PaLampa*, která knihovnu inicializuje a připraví všechny její komponenty pro budoucí použití. Toto je třeba provést pouze jednou po startu výrobku, proto je příkaz umístěn ve funkci *setup*.
* `void loop() {}` - Toto je definice funkce *loop*. Ta je spouštěna stále dokola dokud je výrobek zapnutý s provádí kód umístěný mezi složenými závorkami.

Připojte PaLampa pomocí USB-C kabelu k PC.

V dolní liště PlatformIO stiskněte šipku (*Upload*) a tím nahrajte program do PaLampa.


Počkejte až se dokončí nahrávání a zobrazí v dolním terminálu *SUCCESS*. Nyní je nový program nahrán.


<!-- _________________________________________________________________ -->
# <a name = prvniprogram>První program</a>

Nyní napíšete svůj první vlastní program pro PaLampa. Do šablony kódu na konec funkce *setup* připiště příkaz `PaLampa.lights.setWhite(0, 0.5);`, tedy nad uzavírací závorku `}`. Tento příkaz vydá požadavek, aby se LED svítící teplou bílou barvou rozsvítily na 50% výkonu.

Všimněte si, že při psaní vám VS Code napovídá. Stačí napsat `PaLampa.` a uvidíte nabídku připravených modulů a funkcí z knihovny *PaLampa*. Pokud se tak nestane, nabídku vyvoláte stisknutím *Ctrl + Space*.


Nahrajte program do PaLampa a počkejte, až se LED rozsvítí. Gratulujeme, toto byl váš první vlastní program pro PaLampa :-)

## Výsledný kód

```cpp
#include "PaLampa/PaLampa.h"

void setup() {
    paLampa.begin();
    paLampa.lights.setWhite(0, 0.5);
}

void loop() {}
```

<!-- _________________________________________________________________ -->
# <a name = komentare>Komentáře</a>

Do svého kódu je někdy vhodné psát komentáře. Komentáře jsou kusy textu, které jsou viditelné pro programátora, čili vás, ale TracJet si jich nevšímá (ani se do něj nenahrají). Jsou vhodné zejména v místech, kdy ze samotného funkčního kódu není zřejmé, co dělá a k čemu slouží.

V jazyce C++ máme 2 typy komentářů:
1. Jenořádkový komentář je uvozen dvojitým lomítkem `//`. Celý zbytek řádku za dvojitým lomítkem je považován za komentář.
1. Víceřádkový komentář je uvozen lomítkem a hvězdičkou `/*`. Ukončen je hvězdičkou a lomítkem `*/`. Veškerý text mezi je považován za komentář. Začátek a konec mohou být na různých řádcích.

Příklad: Tento program rozsvítí LED a nechá ji rozsvícenou.
```cpp
#include "PaLampa/PaLampa.h"

void setup() {
    paLampa.begin();
    paLampa.lights.setWhite(0, 0.5); // Toto je komentář
    //paLampa.lights.setWhite(0, 0.0); tento řádek se neprovede

    /* Toto je 
    víceřádkový komentář. */
}

void loop() {}
```

<!-- _________________________________________________________________ -->
# <a name = promenne>Proměnné</a>

## Motivace
Při psaní programů brzy dojdete k tomu, že potřebujete, aby si program něco *zapamatoval*. Může se jednat o výsledek matematicé operace, počítadlo kroků, uchování měřené hodnoty a tak dále. K tomuto účelu se v programech používají **proměnné**. Proměnné si můžeme představovat jako šuplíky s textovými popisky na sobě. Do šuplíku můžeme *vložit* nějakou informaci a někdy později ji opět vytáhnout. Popisek šuplíku zde představuje název proměnné.

## Vytvoření proměnné
Proměnnou vytvoříme následujícím příkazem:
```
typ_promenne nazev_promenne = hodnota;
```
`typ_promenne` udává jaký typ informace budeme do proměnné ukládat. Říkáme mu také *datový typ proměnné*. Může to být číslo, text atd.

`nazev_promenne` udává název proměnné, pomocí kterého dokážeme od sebe jednotlivé proměnné odlišit. Proto musí mít každá proměnná svůj jedinečný název. Snaž se pojménovávat proměnné výstižně, tedy např. *rychlost* je mnohem lepší než *prom*. V názvu proměnné můžeš používat znaky anglické abecedy, tj. bez diakritiky, velká a malá písmena, čísla a speciální znaky jako podrtžítko `_`. Podtžítkem můžeme oddělovat slova v názvu jedné proměnné.

`=` je operátor sloužící k přiřazení (vložení) určité hodnoty do proměnné.

`;` čili středník slouží k oddělování příkazů a píšeme ho vždy na konec příkazu. Na české klávesnici se nachází pod klávesou *ESC* vlevo nahoře.

## Základní datové typy proměnných
* `int` označuje proměnnou pro ukládání celých čísel, například `3`.
* `float` označuje proměnnou pro ukládání desetinných čísel, například `3.14`.
* `char` označuje jeden textový znak -> znak se udává v apostrofech, například `'c'` označuje znak *c*.
* `bool` označuje pravdivostní hodnotu -> *true* pro pravdu a *false* pro nepravdu.
* `String` označuje řetězec textových znaků -> řetězec se ohraničuje uvozovkami, například `"Ahoj svete"`.

## Operace s proměnnými

Operace *přiřazení* slouží k uložení dané hodnoty do proměnné. Hodnota, která je napravo od rovnítka `=` je uložena do proměnné uvedené nalevo od `=`: 
```
nazev_promenne = hodnota;
```

Číselné proměnné můžeme sčítat (+), odečítat (-), násobit (*) a dělit (/). 

Příklad:
```cpp
#include "PaLampa/PaLampa.h"

void setup() {
    paLampa.begin();
    int cele_cislo = 0;
    cele_cislo = cele_cislo + 10;   // Zvýšíme hodnotu v proměnné o 10
    cele_cislo += 10;   // Zkrácený zápis stejné operace jako výše
    // Nyní je v proměnné cele_cislo uložena hodnota 20
}

void loop() {}
```

Zde jsou uvedeny příklady vytvoření proměnných zmíněných datových typů a uložení hodnoty do nich.
```
// proměnná pro celá čísla se jménem cele_cislo, ve které je hodnota 0
int cele_cislo = 0; 

// promenna pro desetinne cislo ve které je hodnota 3.14
float desetinne_cislo = 3.14; 

// proměnná znak, do které jsme uložili znak 'a'
char znak = 'a';

// proměnná otevreno, do které jsme uložili hodnotu pravda (true)
bool otevreno = true; 

// proměnná pro textový řetězec s hodnotou "nejaky text"
String text = "nejaky text";
```

<!-- _________________________________________________________________ -->
# <a name = podminky>Podmínky</a>

## Motivace
Při programování brzo zjistíte, že potřebujete, aby se váš program choval různě v různých situacích. Jinými slovy aby prováděl určité úseky kódu pouze za splnění daných podmínek. K tomu se používají *podmínky*. Ty umožňují programu provádět *rozhodnutí*.

## Konstrukce `if`
`if` je základní podmínka. Základem této konstrukce je *podmínka*, která se uvádí za `if` do kulatých závorek. Podmínka může být proměnná nebo logický výraz.
```
if(podminka) {
    ...kód který se provede, pokud je podmínka splněna (true)...
}
```

U `if` konstrukce docházi k vyhodnocení podmínky, tj. zjistí se, zda je podmínka pravdivá (`true`) nebo nepravdivá (`false(`). Pokud je pravdivá, provede se kód, který je za `if` uveden ve složených závorkách `{...kód...}`. V opačném případě program pokračuje až za `if`.

## Konstrukce `else`
Může existovat jen v případě, že před ní byl uvedený `if`. Úkolem `else` je provést kód v něm napsaný jen v případě, že předchozí `if` nebyl splněn.
```
if(podminka) {
    ...kód který se provede, pokud je podmínka splněna (true)...
}
else {
    ...kód který se provede, pokud není podmínka splněna (false)...
}
```

## Konstrukce `else if`
Pokud chceme postihnout více možných příapadů než dva dříve zmíněné (`true` a `false`), použijeme konstrukci `else if`.
```
if(podminka_1) {
    ...kód který se provede, pokud je podmínka 1 splněna (true)...
}
else if(podminka_2) {
    ...kód který se provede, pokud je podmínka 2 splněna (true)...
}
else {
    ...kód který se provede, pokud není podmínka 1 ani 2 splněna (false)...
}
```

Poznámka: Do jednotlivých konstrukcí větvení je možné libovolně vnořovat další konstrukce větvení.

## Podmínka
Podmínka dotazovaná při větvení určuje zda se bude daný úsek kódu provádět. K tomu je porovnávána s logickými hodnotami `true` a `false`. Tato hodnota může být uložena v pravdivostní proměnné typu `bool`:
```
bool podminka = true;
if(podminka) {
    ...kód je vykonán, protože podmínka je pravdivá...
}
```

K vytvoření podmínky z číselné hodnoty budeme používat tzv. *relační operátory*:
* `==` označuje porovnávání, takže 1 == 1 označuje, že se 1 rovná 1
* `!=` vykřičník před rovnítkem označuje opak, tudíž tento operátor značí nerovnost, tedy 1 != 2 označuje, že se 1 nerovná 2
* `<` menší než
* `>` větší než
* `<=` menší nebo rovno než
* `>=` větší nebo rovno než
Výsledek výrazu s relačními operátory nabývá hodnotu pravda `true` nebo nepravda `false`.
Příklad relačního operátoru:
```
int cele_cislo = 3;
if(cele_cislo < 5) {
    if (cele_cislo > -5) {
        cele_cislo = 0;
    }
}
// V proměnné cele_cislo je uložena hodnota 0, protože obě podmínky byly splněny
```

## Propojování podmínek
Podmínky je možné propojovat do jedné složitější pomocí logických operátorů. Jsou jimi
* `&&` (logické *A*) říká nám, že musí platit obě podmínky, aby byla podmínka splněna, jinak je nesplněna
* `||` (logické *NEBO*) říká nám, že musí platit alespoň jedna podmínka z nich, aby byla podmínka splněna, jinak je nesplněna
Ukázka: Následující program funguje stejně jako předchozí, používá ovšem využívá logické operátory.
```
int cele_cislo = 3;
if(cele_cislo < 5 && cele_cislo > -5) {
    cele_cislo = 0;
}
// V proměnné cele_cislo je uložena hodnota 0, protože obě podmínky byly splněny
```

<!-- _________________________________________________________________ -->
# <a name = cyklus>Cyklus</a>

## Motivace
Při programování se nám často stane, že potřebujeme některé úkony vykonat vícekrát. Případně vykonat velké množství podobných úkonů. K tomuto budeme používat *cykly*, které nám umožní opakovaně vykonávat úseky kódu.

Pro jedno bliknutí LEDkou poslouží tento program:
```cpp
#include "PaLampa/PaLampa.h"

void setup() {
    paLampa.begin();
    paLampa.lights.setWhite(0, 0.5);
    delay(500);
    paLampa.lights.setWhite(0, 0.0);
}

void loop() {}
```

V tomto programu používáme příkaz *delay()* pro čekání na místu v kódu o určitý čas. Tento čas čekání je určen v milisekundách (1000 ms = 1s).

Pro 2 bliknutí LEDkou poslouží tento program, ve kterém jsme pouze zopakovali příkazy z minulého:
```cpp
#include "PaLampa/PaLampa.h"

void setup() {
    paLampa.begin();

    paLampa.lights.setWhite(0, 0.5);
    delay(500);
    paLampa.lights.setWhite(0, 0.0);
    delay(500);
    paLampa.lights.setWhite(0, 0.5);
    delay(500);
    paLampa.lights.setWhite(0, 0.0);
}

void loop() {}
```

Ale co kdybychom chtěli bliknout 1000 krát? Kód by nás přerostl. Cykly nám pomohou tento problém vyřešit. 

## Cyklus `while`
Cyklus `while` použijeme v případě, kdy předem nevíme, kolikrát chceme kód opakovat. Cyklus `while` se opakuje dokud je splněna jeho podmínka (`true`).
```
while(podminka){
    ...Co se ma provest pri kazdem opakovani...
}
```

V následném úseku kódu budeme blikat LEDkou dokud bude výrobek zapnutý:
```
while(true){
    paLampa.lights.setWhite(0, 0.5);
    delay(500);
    paLampa.lights.setWhite(0, 0.0);
    delay(500);
}
```

## Cyklus `for`
Cyklus `for` použijeme v případě, kdy dopředu známe, kolikrát chceme kód opakovat. Cyklus `for` má následující formu:
```
for(vytvoreni_promenne; podminka; operace){
    ...Co se ma provest pri kazdem opakovani...
}
```

Oproti cyklu while je zde podmínková část složitější. Skládá se ze 3 částí:
* Vytvoř proměnnou, kterou využiješ v podmínce
* Zadej podmínku, která bude udávat, do kdy máme kód opakovat
* Uprav hodnotu proměnné, pokud je podmínka splněna

Následující program ukazuje, jak bliknout 10x s LED číslo 1 pomocí cyklus `for`.
```
for(int pocet_bliku = 0; pocet_bliku < 10; pocet_bliku++){
    paLampa.lights.setWhite(0, 0.5);
    delay(500);
    paLampa.lights.setWhite(0, 0.0);
    delay(500);
}
```
Vytvořili jsme proměnnou `pocet_bliku`, která obsahuje celé číslo 0. Dokud je hodnota této proměnné menší než 10, zvýší se její hodnota 1 a provede se kód uvnitř cyklu. Jakmile hodnota proměnné rovna 10, cyklus se ukončí a program pokračuje směrem dolů.

<!-- _________________________________________________________________ -->
# <a name = ledky>LEDky</a>
V této kapitole si podrobněji ukážeme ovládání LED světel na výrobku.

Bílá LED světla ovládáme pomocí již známého příkazu `PaLampa.lights.setWhite(int ledID, float brightness)`. Jedná se o volání funkce s parametry v kulatých závorkách:
* `ledID` udává, kterou LED daného digitu chceme ovládat.
* `brightness` udává, jak jasně má daná LED svítit.

Parametr `ledID` nabývá následujících hodnot:
* `0` pro teplou bílou LED.
* `1` pro studenou bílou LED.
==================

Barevná LED světla ovládáme pomocí příkazu `PaLampa.lights.setColor(int segmentID, int ledID, ColorRGB color)`. Jedná se o volání funkce s parametry v kulatých závorkách:
* `segmentID` udává, který digit chceme ovládat.
* `ledID` udává, kterou LED daného digitu chceme ovládat.
* `color` udává, jakou barvou má daná LED svítit. Můžeme použít předdefinované barvy *red, green, blue, cyan, magenta, yellow, black, white*, nebo si definovat vlastní.

Parametr `segmentID` nabývá následujících hodnot:
* `0` pro horní segment.
* `1` pro zadní segment.

Parametr `ledID` čísluje LEDky v jednotlivých digitech v následujícím pořadí:
* `0` až `15` pro horní segment.
* `0` až `6` pro zadní segment.

Pro definování vlastní barvy použijeme kontrukci podobnou vytváření proměnných. Existují 2 formáty, pomocí kterých můžeme definovat vlastní barvu:
* RGB (red-červená, green-zelená, blue-modrá) příkazem `ColorRGB cervena = {1, 0, 0};`
* HSV (hue-chromatičnost, saturation-saturace, value-jas) příkazem `ColorHSV cervena = {0, 1, 1};`

Oba formáty dokážou definovat jakoukoli barvu, kterou umí barevné LEDky vysvítit, ale každý má své výhody a nevýhody. RGB popisuje barvy podobně jako stroje, tj. jak intenzivně má svítit která barevná složka každé z LEDek v rozsahu 0 až 1, např. 0.5. HSV naopak popisuje barvy podobně, jako lidé a je v mnoha případech pohodlnější k použití, např. pro změnu barvy při zachování jasu.

Pomocí komentářů si v následujícím kódu vyberte jednu z definic barvy `cervena` a ověřte, že výsledkem je stejná červená barva.
```cpp
#include "PaLampa/PaLampa.h"

void setup() {
    paLampa.begin();

    ColorRGB cervena = {1, 0, 0};
    ColorHSV cervena = {0, 1, 1};
    paLampa.lights.setColor(0, 0, cervena);
}

void loop() {}
```

<!-- _________________________________________________________________ -->
# <a name = tlacitka>Tlačítka</a>
Nejjednodušším způsobem, jak můžete PaLampa ovládat je pomocí tlačítek, která najdete na podstavě pod obrazovkou. Pro zjištění jestli je tlačítko zmáčknuto, budeme používat příkaz `PaLampa.buttonRead(int buttonID)`. Parametrem `buttonID` určujeme, na které tlačítko se ptáme. Tlačítka jsou číslována od 0 (vlevo) po 2 (vpravo).

Příklad: Tento program rozsvítí LED při stisku tlačítka 0.
```cpp
#include "PaLampa/PaLampa.h"

void setup() {
    paLampa.begin();
}

void loop() {
    if(paLampa.buttonRead(0)) {
        paLampa.lights.setColor(0, 0, white);
    }
    else {
        paLampa.lights.setColor(0, 0, black);
    }
    delay(20);
}
```

<!-- _________________________________________________________________ -->
# <a name = KapacitniTlacitka>Kapacitní tlačítka</a>
Pro získaní stavu tlačítka voláme funkci paLampa.capButton.getPadPressed(pinID);
pinID může mít hodnotu 0 = viditelné tlačítko vedle displeje, a hodnotu 1 = vámi skryté tlačítko.

Příklad: Tento program rozsvítí LED při stisku kapacitního tlačítka 0.
```cpp
#include "PaLampa/PaLampa.h"

void setup() {
    paLampa.begin();
}

void loop() {
    paLampa.capButton.update(); // update hodnoty tlačítka.
    if(paLampa.capButton.getPadPressed(0)) { // zjištění stavu tlačítka
        paLampa.lights.setColor(0, 0, white);
    }
    else {
        paLampa.lights.setColor(0, 0, black);
    }
    delay(20);
}
```

<!-- _________________________________________________________________ -->
# <a name = piezo>Piezoakustický měnič</a>
## Základy
PaLampa obsahuje tzv. piezoakustický měnič, pomocí kterého dokáže vydávat zvuk.

* Stálý tón zapneme pomocí `paLampa.piezo.tone(uint16_t freq);`, kde `freq` je freqence v Hz.
* Veškerý zvuk vypneme pomocí `paLampa.piezo.stop();`.

Následující příklad přerušovaně "pípá" na frekvenci 1kHz.
```cpp
#include "PaLampa/PaLampa.h"

void setup() {
    paLampa.begin();
}

void loop() {
    paLampa.piezo.tone(1000);
    delay(500);
    paLampa.piezo.stop();
    delay(500);
}
```

## Melodie
PaLampa zvládá i jednoduché melodie. Jen pamatujte na to, že nedokáže hrát více tónů zároveň.
Pro spuštění melodie budeme používat `paLampa.piezo.playMelody(melodie);`.

### Melodie z Arduino songs
Asi nejjednoduším způsobem, jak přehrát melodii, je stáhnout ji z https://github.com/robsoncouto/arduino-songs.
Tam si najděte melodii, otevřte ji a zkopírujte `int melody[] = { ...` a `int tempo = ...`.
Melodii poté přehrajete pomocí `paLampa.piezo.playMelody(melody, sizeof(melody)/sizeof(melody[0]), tempo);`

Následující příklad zahraje melodi Nokie.

```cpp
#include "PaLampa/PaLampa.h"

// Zkopírováno z Arduino songs
int nokieTempo = 180;
int nokieMelody[] = {
  // Nokia Ringtone, Score available at https://musescore.com/user/29944637/scores/5266155
  NOTE_E5, 8, NOTE_D5, 8, NOTE_FS4, 4, NOTE_GS4, 4, 
  NOTE_CS5, 8, NOTE_B4, 8, NOTE_D4, 4, NOTE_E4, 4, 
  NOTE_B4, 8, NOTE_A4, 8, NOTE_CS4, 4, NOTE_E4, 4,
  NOTE_A4, 2, 
};

void setup() {
    paLampa.begin();
    paLampa.piezo.playMelody(nokieMelody, sizeof(nokieMelody)/sizeof(nokieMelody[0]), nokieTempo);
}

void loop() {}
```

### Vlastní melodie
Psaní vlastních melodií je trochu složitější, ale zvládnutelné.

Vlastní melodii budeme zapisovat pomocí klasického notového zápisu, který v našem provedení vypadá následovně (celou melodii musíme psát do uvozovek): 
`Melody nazevMelodie("F5#/8 F5#/8 D5/8 B4/8 R/8*");`

Každá nota se skládá ze dvou částí.
* Před lomítkem se udává výška noty. `#` zvedá notu o 1/2 noty. `R` znamená pauza.
* Za lomítkem se udává délka noty. `*` prodlužuje notu o půlku.
    * `1` -> celá nota
    * `8` -> 1/8 celé noty
    * `2*` -> 1/2 + 1/4 -> 3/4 celé noty

#### Tempo
Vlastní melodii musíme nastavit i tempo. To se udává v BPM (beats per minute), nebo-li počet čtvrtnot za minutu.
Tempo lze nastavit dvěma způsoby.

Při definici melodie: 
```
Melody nazevMelodie("TEMPO=180 F5#/8 F5#/8 D5/8 B4/8 R/8*");
```

Nebo později:
```
Melody nazevMelodie("F5#/8 F5#/8 D5/8 B4/8 R/8*");
nazevMelodie.tempo = 180;
```
Ale pozor! `nazevMelodie.tempo = 180;` lze volat pouze uvnitř funkce (`void setup()`, `void loop()`, ... ). Proto doporučuji spíše první způsob.

#### Přehrání
Vlastní melodii přehrajeme pomocí `paLampa.piezo.playMelody(nazevMelodie);`.

Příklad:
```cpp
#include "PaLampa/PaLampa.h"

Melody melodyTest("TEMPO=180 c3/4 d3/4 e3/4 f3/4 g3/4 g3/4 a3/4 h3/4 c4/2* c4#/1*");

void setup() {
    paLampa.begin();
	paLampa.piezo.playMelody(melodyTest);
}

void loop() {
}
```

## Další funkce PaLampa.piezo
`paLampa.piezo.getState();` vrací aktuální stav.
* `0` -> nic nehraje
* `1` -> stálý tón
* `2` -> hraje melodie

<!-- _________________________________________________________________ -->
# <a name = fotorezistory>Fotorezistory</a>

Pro snímání úrovně osvětlení v okolí výrobku slouží fotorezistory. Výrobek je osazen dvěma fotorezistory:
* Fotorezistor ID 0 je umístěn na horní straně spodní podstavy, pod plastovým krytem nad obrazovkou.
* Fotorezistor ID 1 je umístěn na zadní straně spodní podstavy.

Pro zjištění úrovně osvitu jednotlivých fotorezistorů použijeme příkaz `paLampa.photoresistor.get(int photoresID);`, kde `photoresID` udává index fotorezistoru. Vrácena je nám celočíselná hodnota v rozsahu 0.0 (tma) až 1.0 (světlo).

Následující příklad zjistí hodnotu osvitu fotorezistoru 0 a nastaví podle něj červený jas LED.
```cpp
#include "PaLampa/PaLampa.h"

void setup() {
    paLampa.begin();
}

void loop() {
    float osvit = paLampa.photoresistor.get(0);
    ColorRGB barva = {osvit*255, 0, 0};
    paLampa.lights.setColor(0, 0, barva);
    delay(20);
}
```

<!-- _________________________________________________________________ -->
# <a name = lista>Dotyková lišta</a>

Pro pohodlné zapínání a vypínání výrobku slouží dotykové tlačítko umístěné napravo od obrazovky. Pro zjištění, jestli je zmáčknuto, použijeme příkaz `paLampa.touchBar.getPressed(int buttonID);`. Vrácena je binární hodnota 0 (nezmáčknuto) nebo 1 (zmáčknuto).

Následující příklad rozsvítí LED při zmáčknutí dotykového tlačítka.
```cpp
#include "PaLampa/PaLampa.h"

void setup() {
    paLampa.begin();
}

void loop() {
    if(paLampa.touchBar.getPressed(0)) {
        paLampa.lights.setWhite(0, 0.5);
    }
    else {
        paLampa.lights.setWhite(0, 0.0);
    }
    delay(20);
}
```

<!-- _________________________________________________________________ -->
# <a name = teplomer>Teploměr</a>

Pro zjištění teploty v okolí je výrobek vybaven dvěma teploměry DS18B20. Pro zjištění měřené teploty použijeme příkaz `paLampa.thermometer.get(int thermometerID);`. Vráceno je desetinné číslo reprezentující teplotu ve stupních Celsia. Parameter `thermometerID` udává index teploměru nabývající hodnot:
* `0` pro dolní teploměr měřící teplotu okolního vzduchu.
* `1` pro horní teploměr měřící teplotu LED panelu za účelem zabránění přehřátí.

Následující příklad zjistí teplotu okolního vzduchu, uloží ji do proměnné `teplota` a rozsvítí červenou LED pokud je vyšší než 25.
```cpp
#include "PaLampa/PaLampa.h"

void setup() {
    paLampa.begin();
}

void loop() {
    int teplota = paLampa.thermometer.get(0);
    if(teplota > 25.0) {
        paLampa.lights.setColor(0, 0, red);
    }
    else {
        paLampa.lights.setColor(0, 0, black);
    }
    delay(200);
}
```

<!-- _________________________________________________________________ -->
# <a name = seriovka>Sériová linka</a>

## Motivace
Při programování výrobků se často stane, že potřebujete s programem ve výrobku komunikovat. Například když se snažíte odhalit chybu, vypisovat hodnotu senzorů nebo informovat uživatele o ději v programu. Pro tento účel nám poslouží sériová linka.

## Program pro výpis textu na sériové lince
Pro výpis textu na sériové lince budeme používat příkaz `printf`. Abyste na sériové lince jedenkrát vypsali text *Hello World!*, použijte následující program:
```cpp
#include "PaLampa/PaLampa.h"

void setup() {
    paLampa.begin();
}

void loop() {
    printf("Hello World!\n");
    delay(1000);
}
```

Okolo textu, který chceme vypsat, je třeba vložit dvojité uvozovky `"text"`. Řetězec `\n` označuje znak pro odřádkování, čili obdoba tlačítka *ENTER* v textových editorech. 

## Spuštění sériové linky
1. Po nahrání programu do PaLampa necháme PaLampa zapnutý a připojený USB kabelem k PC.
1. Pomocí tlačítka v levé dolní liště PlatformIO ve tvaru zásuvky spustíme sériovou linku.
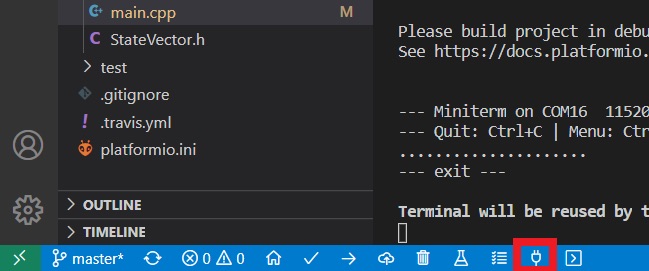
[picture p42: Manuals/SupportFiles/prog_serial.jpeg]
    
1. V monitoru sériové linky v dolní částí okna VS Code najdete příchozí zprávy z PaLampa. Uvidíte, že každou vteřinu přijde nová zpráva ve tvaru *Hello World!*, vždy na novém řádku:
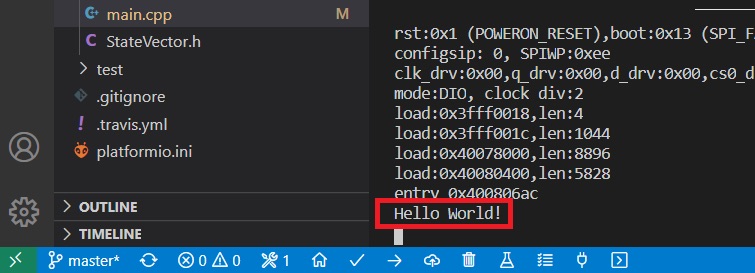
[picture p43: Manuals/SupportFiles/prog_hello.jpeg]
    

## Výpis hodnot proměnných
Často potřebujeme vypsat i hodnotu některé z našich proměnných. V tomto případě můžeme použít takzvaná formátovací direktiva. V textu začínají znakem `%`:
* %d - (decimal) označuje proměnnou pro ukládání celých čísel, například `3`.
* %f - (float) označuje proměnnou pro ukládání desetinných čísel, například `3.14`.
* %c - (char) označuje jeden textový znak, například `'c'` označuje znak *c*.
* %s - (string) označuje řetězec textových znaků -> řetězec se ohraničuje uvozovkami, například `"Ahoj svete"`.

Pro úpravu formátu vypisovaných proměnných máme mnoho dalších možností, které jsou například na [Wiki](https://cs.wikipedia.org/wiki/Printf#Form%C3%A1tovac%C3%AD_%C5%99et%C4%9Bzec). Pro výpis celočíselné proměnné `cele_cislo` do sériové linky použijeme následující příkaz:
```
printf("%d\n", cele_cislo);
```

Příklad: Pro opakovaný výpis času od startu PaLampa použijeme následující program. Hodnota času je uvedena v milisekundách:
```cpp
#include "PaLampa/PaLampa.h"

void setup() {
    paLampa.begin();
}

void loop() {
    printf("%d\n", millis());
    delay(1000);
}
```

Funkce `millis()` nám vrací počet uplynulých milisekund od startu PaLampa jako celé číslo. 

<!-- _________________________________________________________________ -->
# <a name = ledky2>Pokročilé ovládání LED</a>

Pro ovládání teploty bílých LED lze použít funkci `paLampa.lights.setWhiteMix(float brightness, float mix)`, která nastaví teplotu bílých světel v závislosti na hodnotě mix (0.0 až 1.0). Pro stejnou funkcionalitu lze také použít funkci `paLampa.lights.setWhiteTemp(float brightness, float temp)` při které se teplota světel nastavuje v kelvinech v rozmezí 2700 pro teplé světlo až po 5200 pro studené světlo. Hodnota brightness (v rozmezí 0.0 až 1.0) nastavuje jas bílých světel u obou funkcí.

Pro ovládání LED světel je možné použít i schopnější funkce než `.setColor()`, která umí ovládat pouze jednu barevnou LED.

Pro rosvícení celého segmentu LED jedním příkazem je možné použít konstrukci `paLampa.lights.setColorPanel(int segmentID, ColorRGB color);`. Jedná se o volání funkce s parametry:
* `segmentID` udává index segmentu (úseku LED), který chceme ovládat. Segmenty odpovídají rozdělení jako u funkce `.setColor()`.
* `color` udává, jakou barvou má daný segment svítit.

Pro rozsvícení několika vybraných segmentů jedním příkazem použijeme konstrukci `paLampa.lights.setColorSegments(SegmentSelector selector, ColorRGB color);`. Jedná se o volání funkce s parametry:
* `selector` který definuje skupinu segmentů, které mají svítit. 
* `color` udává, jakou barvou mají dané segmenty svítit.

Parametr `selector` zde nabývá následujících hodnot:
* `all` - Svítí všechny barevné LED.
* `top` - Svítí všechny LED na horním panelu.
* `back` - Svítí všechny LED na zadním LED pásku.

Příkaz `paLampa.lights.setColorBrightness(SegmentSelector selector, float brightness);` nastaví jas všech barevných LED na vybraných segmentech. Všechny následující příkazy nastavující barvu LED vybraných segmentů budou nastavovat barvu se sníženým jasem. Jedná se o volání funkce s parametry:
* `selector` udává výběr segmentů pro provedení nastavení.
* `brightness` nastavuje hodnotu jasu v rozsahu 0.0 (nesvítí vůbec) po 1.0 (svítí naplno).

Příkaz `paLampa.lights.setColorTransition(SegmentSelector selector, TransitionType aTransitionType, float aTransitionRate);` slouží k nastavení přechodových animací barevných LED, např. pro nastavení plynulých přechodů mezi různými stavy rozsvícení. Jedná se o volání funkce s parametry v kulatých závorkách:
* `selector` udává výběr segmentů pro provedení nastavení.
* `aTransitionType` udává druh přechodové animace. Možnosti jsou `Linear` a `Exponential`, kde 2. varianta je vizuálně přirozenější.
* `aTransitionTime` udává dobu trvání přechodové animace ve vteřinách. Např. `1.0` odpovídá přechodu plného rozsahu z tmy až do plného bílého svitu přechodem trvajícím 1 vteřinu.

Podobně lze použít příkaz `paLampa.lights.setWhiteTransition(std::vector<bool> selectLed, TransitionType aTransitionType, float aTransitionRate);` pro nastavení přechodových animací bílých LED. Prvním parametrem je vektor udávající, kterých bílých LED se příkaz týká, čili např hodnota parametru `{1, 1}` zvolí obě bílé LED (teplou i studenou). Zbylé parametry jsou shodné s předchozí funkcí `setColorTransition()`.

Následující příklad nastaví jas předního displeje na `0.5`, plynulý přechod s rychlostí `2.0`.
```cpp
#include "PaLampa/PaLampa.h"

void setup() {
    paLampa.begin();
    paLampa.display.setColorBrightness(all, 0.5);
    paLampa.display.setColorTransition(all, linear, 2.0);)
}

void loop() {}
```

Jas LED je shora omezen maximálním elektrickým proudem, který je možné udebírat z USB zdroje. Proto není vždy možné dosáhnout plného jasu všech LED. Některé USB zdroje umožňují automatické zjištění maximálního dodávaného proudu, což PaLampa podporuje. V standardním nastavení je zjišťování proudového limitu nabíječky automatické. Režim omezení odebíraného proudu je však možné nastavit i manuálně pomocí funkce `PaLampa.power.setMode(PowerMode mode)`, kde parametr `mode` nabývá hodnot:
* `USB2_500mA` - Omezení proudu na 500mA
* `USB3_900mA` - Omezení proudu na 900mA
* `Medium_1500mA` - Omezení proudu na 1500mA
* `High_3000mA` - Omezení proudu na 3000mA
* `Automatic` - Automatické nastavení

Tuto funkci stačí zavolat pouze jednou a to umístěním do funkce `setup(){}`.

<!-- _________________________________________________________________ -->
# <a name = obrazovka>Obrazovka</a>

Pro základní ovládání OLED obrazovky je možné použít přímo knihovnu [Adafruit GFX](https://github.com/adafruit/Adafruit-GFX-Library). Objekt obrazovky této knihovny je možné získat příkazem `PaLampa.oled.getDisplay()`. Přidáním další tečky můžeme připojovat a provádět příkazy z knihovny Adafruit GFX.

<!-- _________________________________________________________________ -->
# <a name = wifi>WiFi</a>

Pro spuštění WiFi a ovládací webové aplikace slouží funkce `paLampa.startWiFiCaptain("<your_name>")`. Po jejím zavolání bude postaráno o vytvoření WiFi přístupového bodu (AP) v PaLampa a také o připojní k externí WiFi, jakmile má PaLampa správné přihlašovací údaje a je v dosahu. Také je spuštěn server hostující webovou aplikaci pro dálkové ovládání PaLampa.

<!-- _________________________________________________________________ -->
# <a name = prikazy>Vzdálený příkazový řádek</a>

Pro dálkové ovládání PaLampa můžete použít i textové příkazy. Ty budete zadávat do pole *Command entry* na webové stránce dálkového ovládání. Po stisku tlačítka *Enter* (funguje i na klávesnici) je zadaný příkaz odeslán do PaLampa. K použítí přijatého příkazu budeme používat následující funkce:
* `paLampa.commandGet()` - vrací textový řetězec (proměnnou typu *String*) obsahující aktuálně přijatý příkaz.
* `paLampa.commandGetIndexed(index)` - vrací textový řetězec obsahující jedno slovo z přijatého příkazu. Slova jsou oddělena mezerami a číslována od 0.
* `paLampa.commandClear()` - vymaže obsah celého aktuálně přijatého příkazu.

Příklad: Následující program blikne LED po obdržení příkazu "blink":
```cpp
#include "PaLampa/PaLampa.h"

void setup() {
    paLampa.begin();
    paLampa.startWiFiCaptain("<your_name>");
}

void loop() {
    if(paLampa.commandGet() == "blink") {
        paLampa.lights.setWhite(0, 0.5);
        delay(500);
        paLampa.lights.setWhite(0, 0.0);
        paLampa.commandClear();  // nutné jinak bude v paměti pořád příkaz "blink" a LED bude pořád svítit
    }
    delay(100);
}
```

PaLampa umožňuje textovou komunikaci i opačným směrem, tedy z PaLampa do webové stránky dálkového ovládání.
* `paLampa.commandDisp(command)` - odešle textový příkaz *command* z PaLampa a zobrazí ho šedě v poli *Command entry*.

Příklad: Následující program bude v textovém poli *Command entry* vypisovat stav tlačítka 1 na PaLampa:
```cpp
#include "PaLampa/PaLampa.h"

void setup() {
    paLampa.begin();
    paLampa.startWiFiCaptain("<your_name>");
}

void loop() {
    paLampa.commandDisp(String(paLampa.buttonRead(1)));
    delay(500);
}
```

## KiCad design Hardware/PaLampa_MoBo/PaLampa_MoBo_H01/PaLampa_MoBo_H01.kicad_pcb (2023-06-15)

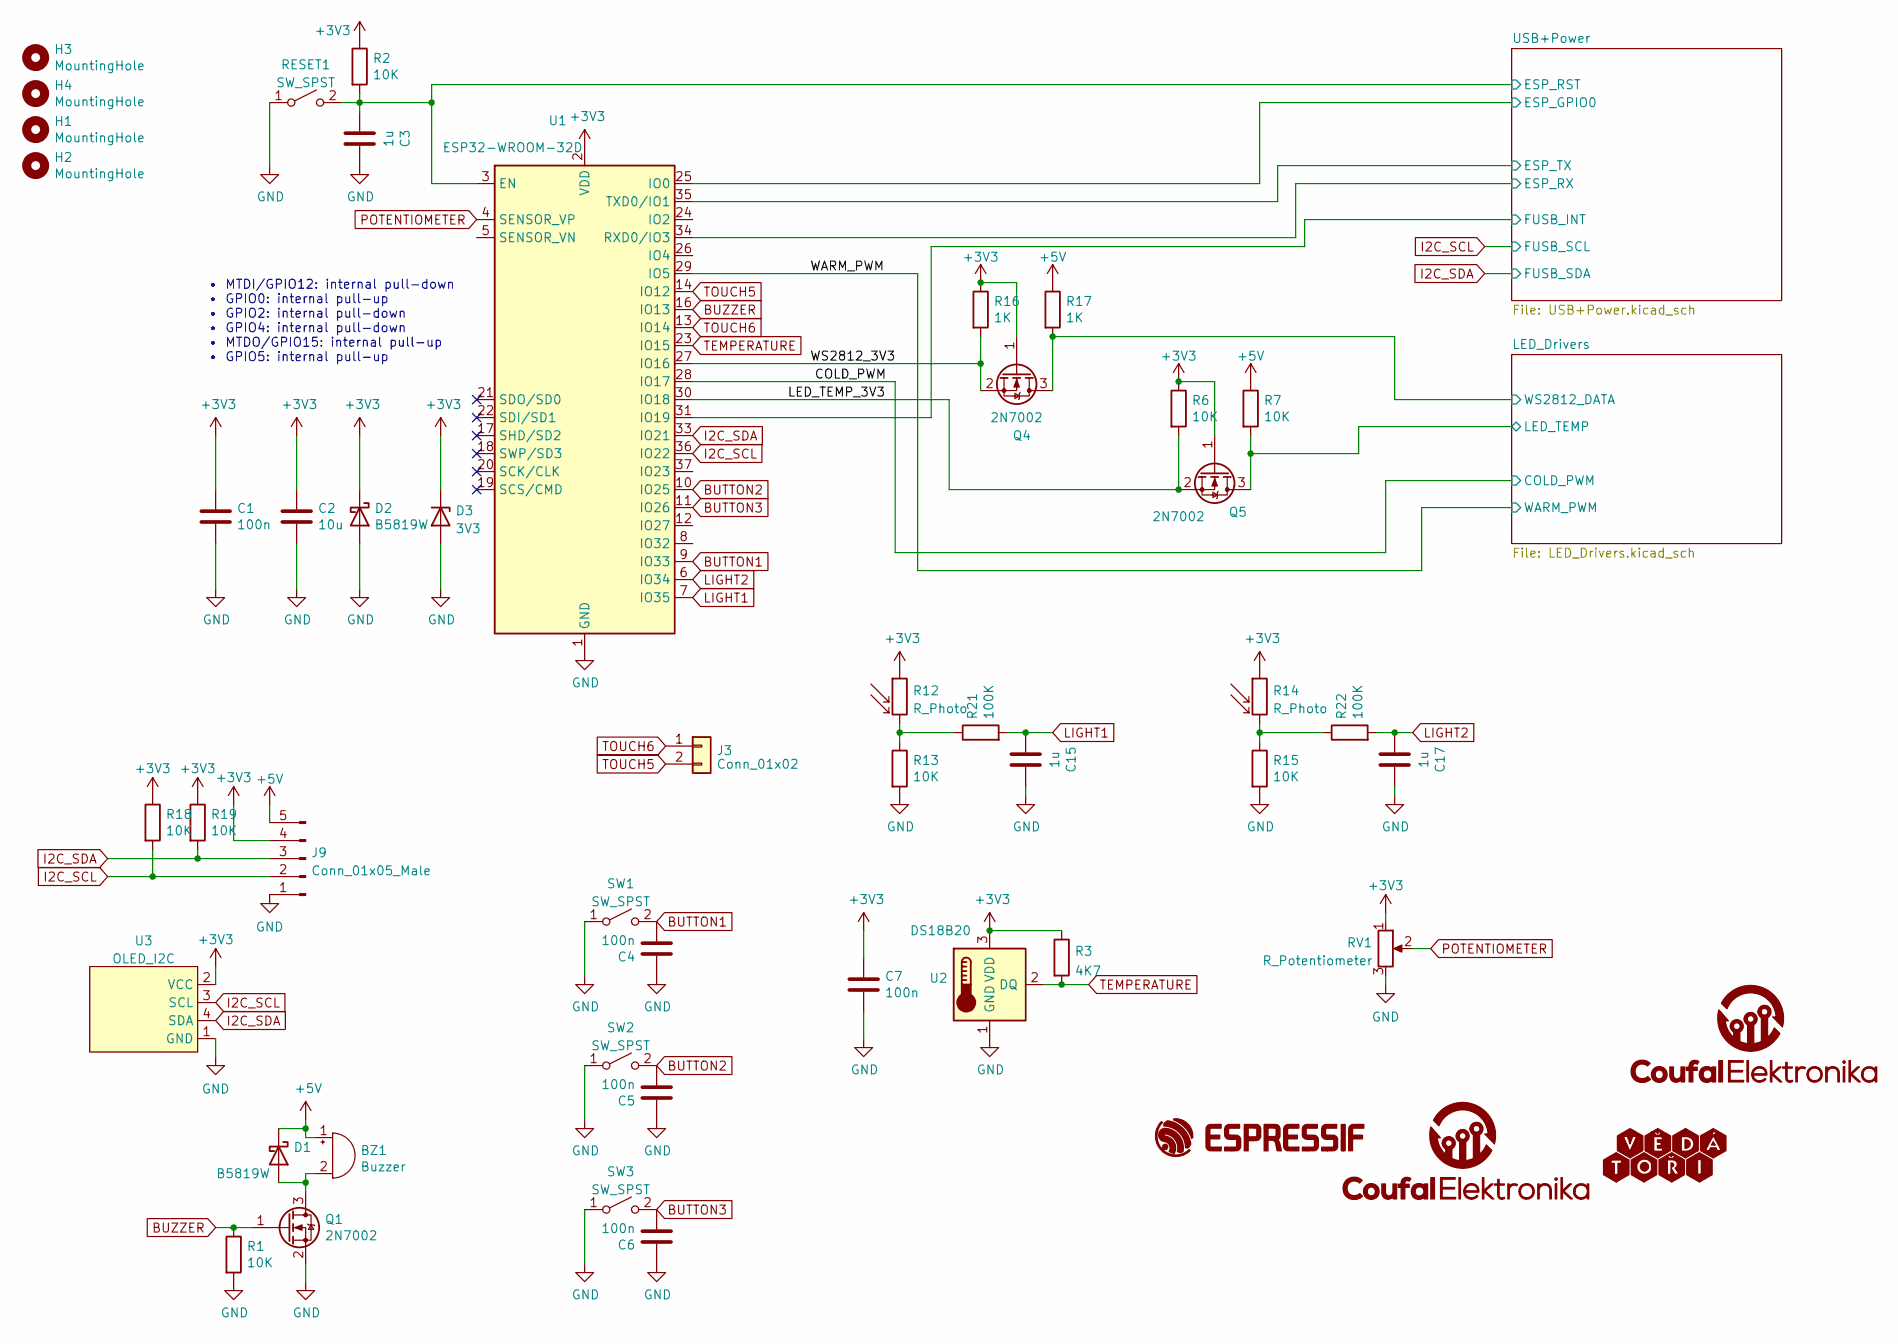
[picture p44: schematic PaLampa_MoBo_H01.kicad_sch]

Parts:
BZ1: Buzzer; Buzzer_12x9.5RM6.6
C1, C4, C5, C6, C7: 100n; C_0603_1608Metric; LCSC C14663
C2: 10u; C_0805_2012Metric; LCSC C15850
C3, C15, C17: 1u; C_0603_1608Metric; LCSC C15849
D1, D2: B5819W; D_SOD-123; LCSC C8598
D3: 3V3; D_MiniMELF; LCSC C8056
G1: CoufalElektronika_logo; Coufal_elektronika_text_30x13mm
G2: Vedatori_logo; VedatoriNew_40x5,7mm
G4: CoufalElektronika_logo; Coufal_elektronika_notext_10mm
G5: Espressif_logo; Espressif_logo_30mm
H1, H2, H3, H4: MountingHole; MountingHole_3.2mm_M3
J3: Conn_01x02; JST_XH_B2B-XH-A_1x02_P2.50mm_Vertical
J9: Conn_01x05_Male; PinHeader_1x05_P2.54mm_Vertical
Q1, Q4, Q5: 2N7002; SOT-23; LCSC C8545
R1, R2, R6, R7, R13, R15, R18, R19: 10K; R_0603_1608Metric; LCSC C25804
R3: 4K7; R_0603_1608Metric; LCSC C23162
R12, R14: R_Photo; R_LDR_5.1x4.3mm_P3.4mm_Vertical
R16, R17: 1K; R_0603_1608Metric; LCSC C21190
R21, R22: 100K; R_0603_1608Metric; LCSC C25803
RESET1: SW_SPST; SW_SPST_TL3342; LCSC C318884
RV1: R_Potentiometer; Potentiometer_Alps_RK09K_Single_Vertical
SW1, SW2, SW3: SW_SPST; SW_PUSH_6mm_H13mm
U1: ESP32-WROOM-32D; ESP32-WROOM-32; LCSC C529577
U2: DS18B20; TO-92_HandSolder
U3: OLED_I2C; Display_128x64_096_I2C_3Hole

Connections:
+3V3: C1.1, C2.1, C7.1, D2.1 (K), D3.1 (K), J9.4, Q4.1 (G), Q5.1 (G), R2.1, R3.1, R6.1, R12.1, R14.1, R16.1, R18.1, R19.1, RV1.1, U1.2 (VDD), U2.3 (VDD), U3.2 (VCC); also elsewhere on the board
+5V: BZ1.1 (-), D1.1 (K), J9.5, R7.1, R17.1; also elsewhere on the board
/COLD_PWM: U1.28 (IO17); also elsewhere on the board
/LED_Drivers/LED_TEMP: Q5.3 (D), R7.2; also elsewhere on the board
/LED_Drivers/WS2812_DATA: Q4.3 (D), R17.2; also elsewhere on the board
/LED_TEMP_3V3: Q5.2 (S), R6.2, U1.30 (IO18)
/USB+Power/ESP_GPIO0: U1.25 (IO0); also elsewhere on the board
/USB+Power/ESP_RST: C3.2, R2.2, RESET1.2 (B), U1.3 (EN); also elsewhere on the board
/USB+Power/ESP_RX: U1.34 (RXD0/IO3); also elsewhere on the board
/USB+Power/ESP_TX: U1.35 (TXD0/IO1); also elsewhere on the board
/USB+Power/FUSB_INT: U1.31 (IO19); also elsewhere on the board
/WARM_PWM: U1.29 (IO5); also elsewhere on the board
/WS2812_3V3: Q4.2 (S), R16.2, U1.27 (IO16)
BUTTON1: C4.2, SW1.2 (B), U1.9 (IO33)
BUTTON2: C5.2, SW2.2 (B), U1.10 (IO25)
BUTTON3: C6.2, SW3.2 (B), U1.11 (IO26)
BUZZER: Q1.1 (G), R1.1, U1.16 (IO13)
GND: C1.2, C2.2, C3.1, C4.1, C5.1, C6.1, C7.2, C15.1, C17.1, D2.2 (A), D3.2 (A), J9.1, Q1.2 (S), R1.2, R13.2, R15.2, RESET1.1 (A), RV1.3, SW1.1 (A), SW2.1 (A), SW3.1 (A), U1.1 (GND), U1.15 (GND), U1.38 (GND), U1.39 (GND), U2.1 (GND), U3.1 (GND); also elsewhere on the board
I2C_SCL: J9.2, R18.2, U1.36 (IO22), U3.3 (SCL); also elsewhere on the board
I2C_SDA: J9.3, R19.2, U1.33 (IO21), U3.4 (SDA); also elsewhere on the board
LIGHT1: C15.2, R21.2, U1.7 (IO35)
LIGHT2: C17.2, R22.2, U1.6 (IO34)
unnamed: BZ1.2 (+), D1.2 (A), Q1.3 (D)
unnamed: R12.2, R13.1, R21.1
unnamed: R14.2, R15.1, R22.1
POTENTIOMETER: RV1.2, U1.4 (SENSOR_VP)
TEMPERATURE: R3.2, U1.23 (IO15), U2.2 (DQ)
TOUCH5: J3.2, U1.14 (IO12)
TOUCH6: J3.1, U1.13 (IO14)

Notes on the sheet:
• MTDI/GPIO12: internal pull-down • GPIO0: internal pull-up • GPIO2: internal pull-down • GPIO4: internal pull-down • MTDO/GPIO15: internal pull-up • GPIO5: internal pull-up

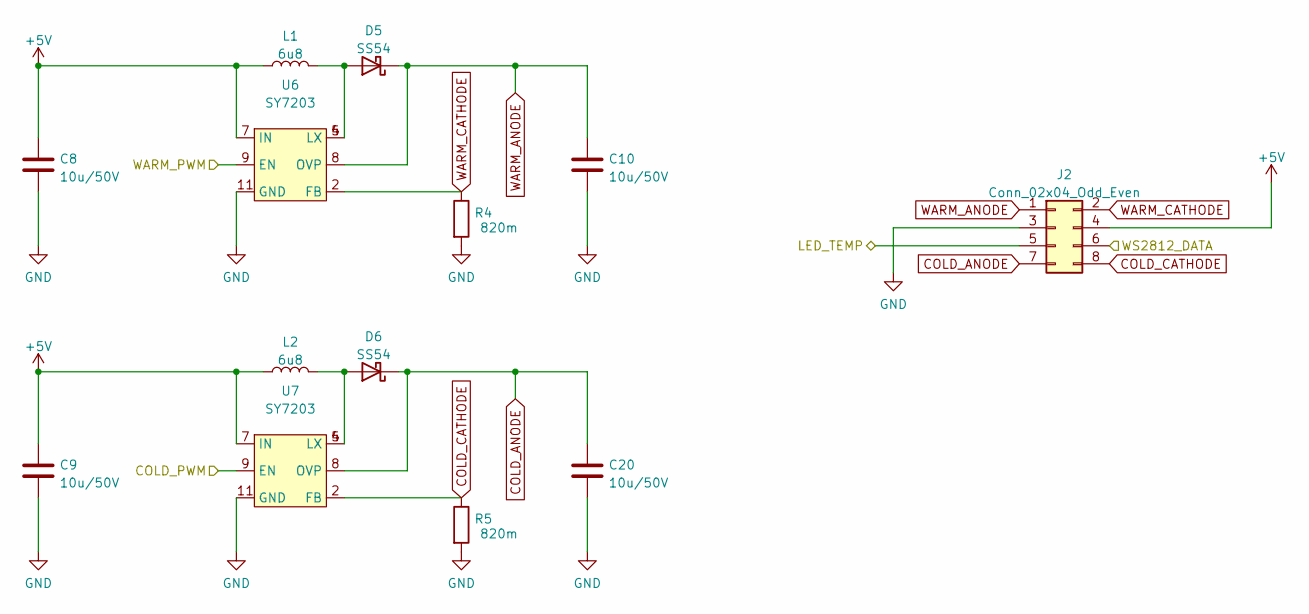
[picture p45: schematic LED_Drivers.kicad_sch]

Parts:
C8, C9, C10, C20: 10u/50V; C_1206_3216Metric; LCSC C13585
D5, D6: SS54; D_SMA; LCSC C22452
J2: Conn_02x04_Odd_Even; IDC-Header_2x04_P2.54mm_Vertical
L1, L2: 6u8; L_Cenker_CKCS5040; LCSC C354608
R4, R5: 820m; R_1206_3216Metric; LCSC C175854
U6, U7: SY7203; DFN-10-1EP_3x3mm_P0.5mm_EP1.75x2.6mm; LCSC C125894

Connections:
+5V: C8.1, C9.1, J2.4, L1.1, L2.1, U6.7 (IN), U7.7 (IN); also elsewhere on the board
/COLD_PWM: U7.9 (EN); also elsewhere on the board
/LED_Drivers/LED_TEMP: J2.5; also elsewhere on the board
/LED_Drivers/WS2812_DATA: J2.6; also elsewhere on the board
/WARM_PWM: U6.9 (EN); also elsewhere on the board
COLD_ANODE: C20.1, D6.1 (K), J2.7, U7.8 (OVP)
COLD_CATHODE: J2.8, R5.1, U7.2 (FB)
GND: C8.2, C9.2, C10.2, C20.2, J2.3, R4.2, R5.2, U6.11 (GND), U7.11 (GND); also elsewhere on the board
unnamed: D5.2 (A), L1.2, U6.4 (LX), U6.5 (LX)
unnamed: D6.2 (A), L2.2, U7.4 (LX), U7.5 (LX)
WARM_ANODE: C10.1, D5.1 (K), J2.1, U6.8 (OVP)
WARM_CATHODE: J2.2, R4.1, U6.2 (FB)

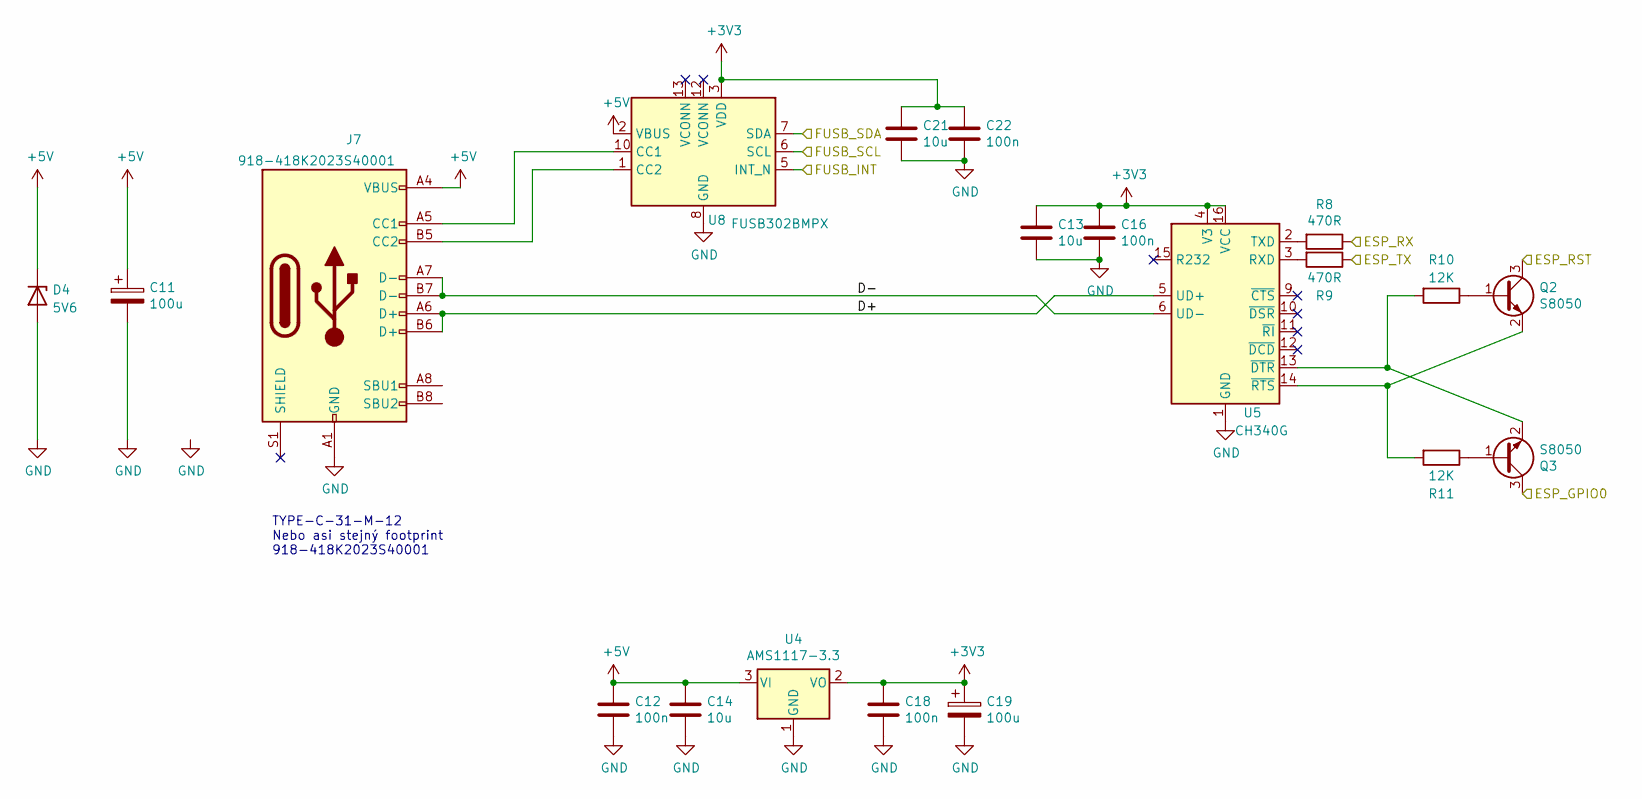
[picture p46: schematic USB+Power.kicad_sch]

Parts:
C11, C19: 100u; CP_Radial_D5.0mm_P2.00mm; LCSC C43348
C12, C16, C18, C22: 100n; C_0603_1608Metric; LCSC C14663
C13, C21: 10u; C_0603_1608Metric; LCSC C19702
C14: 10u; C_0805_2012Metric; LCSC C15850
D4: 5V6; D_MiniMELF; LCSC C8062
J7: 918-418K2023S40001; USB_C_Receptacle_HRO_TYPE-C-31-M-12; LCSC C167321
Q2, Q3: S8050; SOT-23; LCSC C2146
R8, R9: 470R; R_0603_1608Metric; LCSC C23179
R10, R11: 12K; R_0603_1608Metric; LCSC C22790
U4: AMS1117-3.3; SOT-223-3_TabPin2; LCSC C6186
U5: CH340G; SOIC-16_3.9x9.9mm_P1.27mm; LCSC C84681
U8: FUSB302BMPX; WQFN-14-1EP_2.5x2.5mm_P0.5mm_EP1.45x1.45mm; LCSC C132291

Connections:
+3V3: C13.1, C16.1, C18.1, C19.1, C21.1, C22.1, U4.2 (VO), U5.4 (V3), U5.16 (VCC), U8.3 (VDD), U8.4 (VDD); also elsewhere on the board
+5V: C11.1, C12.1, C14.1, D4.1 (K), J7.A4 (VBUS), J7.A9 (VBUS), J7.B4 (VBUS), J7.B9 (VBUS), U4.3 (VI), U8.2 (VBUS); also elsewhere on the board
/USB+Power/D+: J7.A6 (D+), J7.B6 (D+), U5.5 (UD+)
/USB+Power/D-: J7.A7 (D-), J7.B7 (D-), U5.6 (UD-)
/USB+Power/ESP_GPIO0: Q3.3 (C); also elsewhere on the board
/USB+Power/ESP_RST: Q2.3 (C); also elsewhere on the board
/USB+Power/ESP_RX: R8.1; also elsewhere on the board
/USB+Power/ESP_TX: R9.1; also elsewhere on the board
/USB+Power/FUSB_INT: U8.5 (INT_N); also elsewhere on the board
GND: C11.2, C12.2, C13.2, C14.2, C16.2, C18.2, C19.2, C21.2, C22.2, D4.2 (A), J7.A1 (GND), J7.A12 (GND), J7.B1 (GND), J7.B12 (GND), U4.1 (GND), U5.1 (GND), U8.8 (GND), U8.9 (GND), U8.15 (GND); also elsewhere on the board
I2C_SCL: U8.6 (SCL); also elsewhere on the board
I2C_SDA: U8.7 (SDA); also elsewhere on the board
unnamed: J7.A5 (CC1), U8.10 (CC1), U8.11 (CC1)
unnamed: J7.B5 (CC2), U8.1 (CC2), U8.14 (CC2)
unnamed: Q2.1 (B), R10.1
unnamed: Q2.2 (E), R11.2, U5.14 (~RTS)
unnamed: Q3.1 (B), R11.1
unnamed: Q3.2 (E), R10.2, U5.13 (~DTR)
unnamed: R9.2, U5.3 (RXD)
unnamed: R8.2, U5.2 (TXD)

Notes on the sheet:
TYPE-C-31-M-12 Nebo asi stejný footprint 918-418K2023S40001

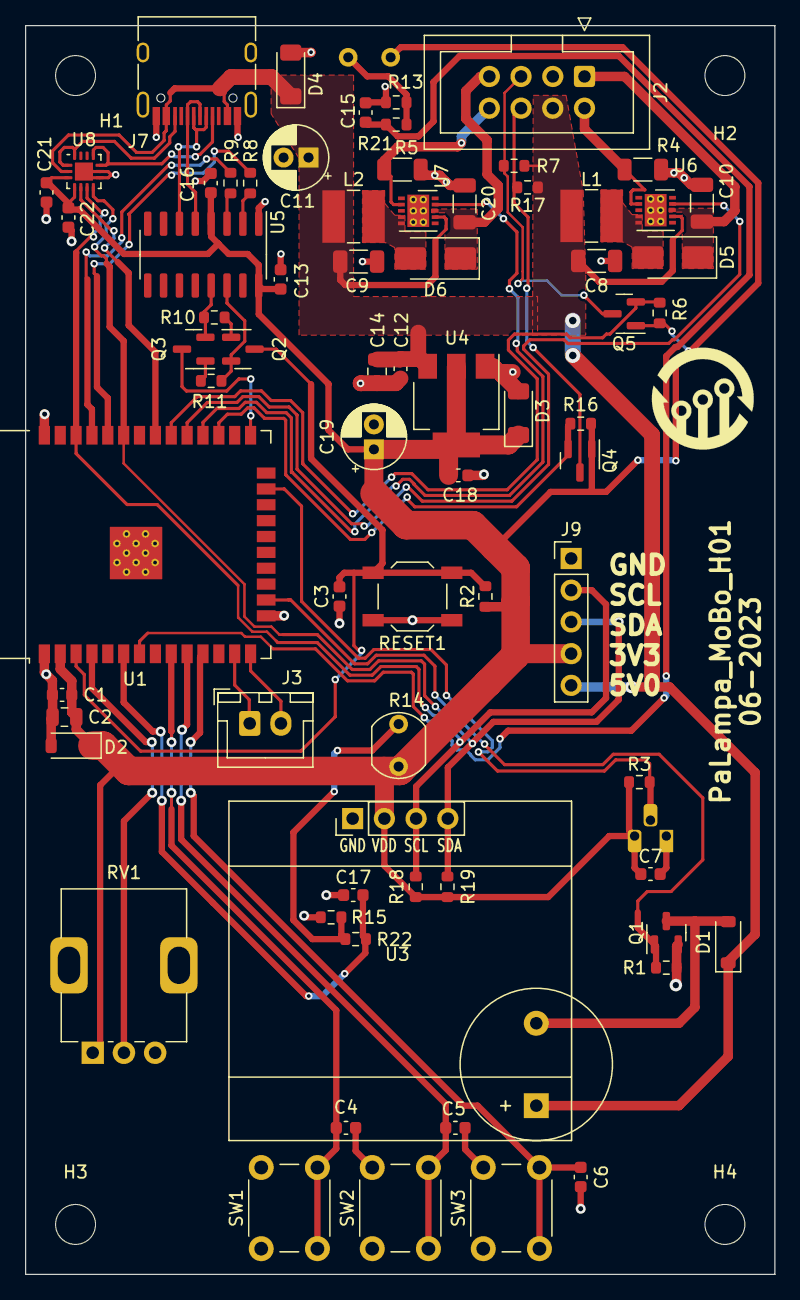
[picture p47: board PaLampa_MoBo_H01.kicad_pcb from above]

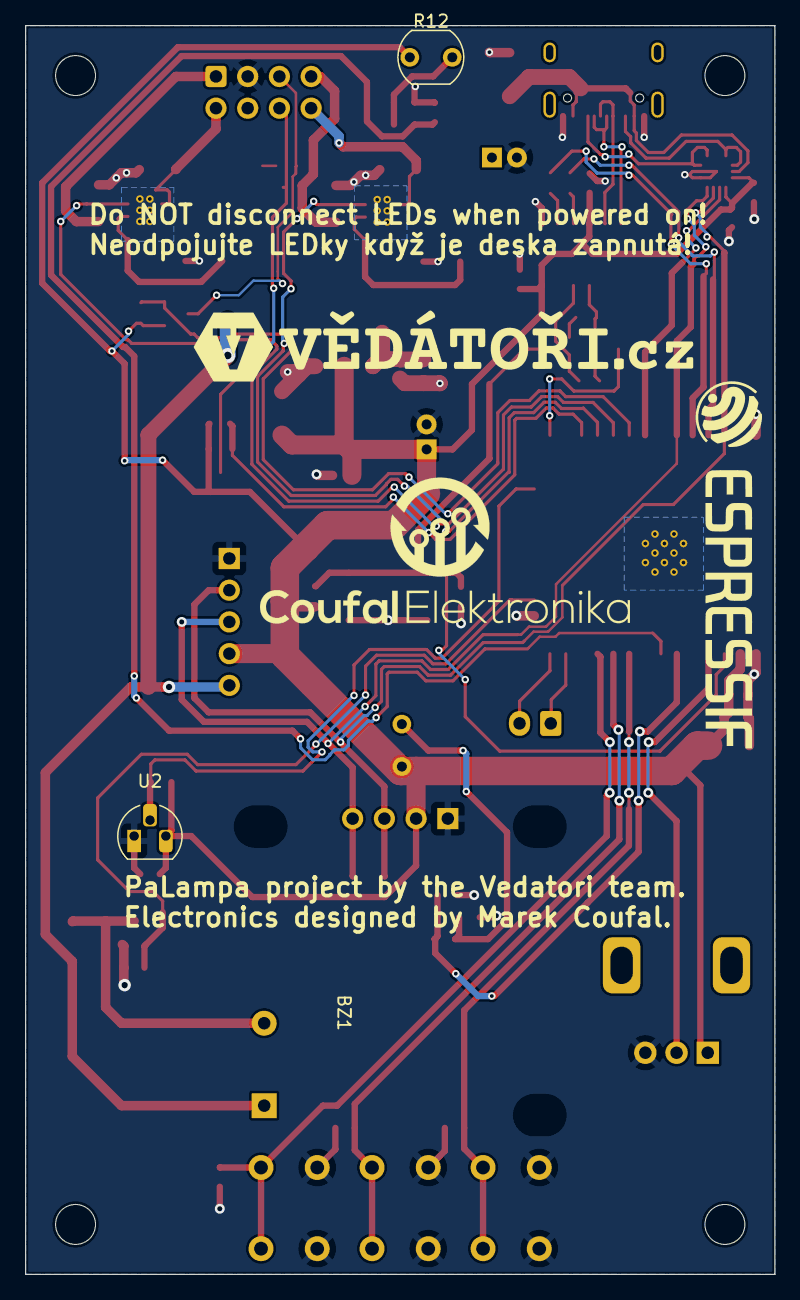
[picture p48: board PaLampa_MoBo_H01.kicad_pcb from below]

Board: 2 copper layers, 60.0 x 100.0 mm, 82 parts (5 on the bottom side), 45 nets.

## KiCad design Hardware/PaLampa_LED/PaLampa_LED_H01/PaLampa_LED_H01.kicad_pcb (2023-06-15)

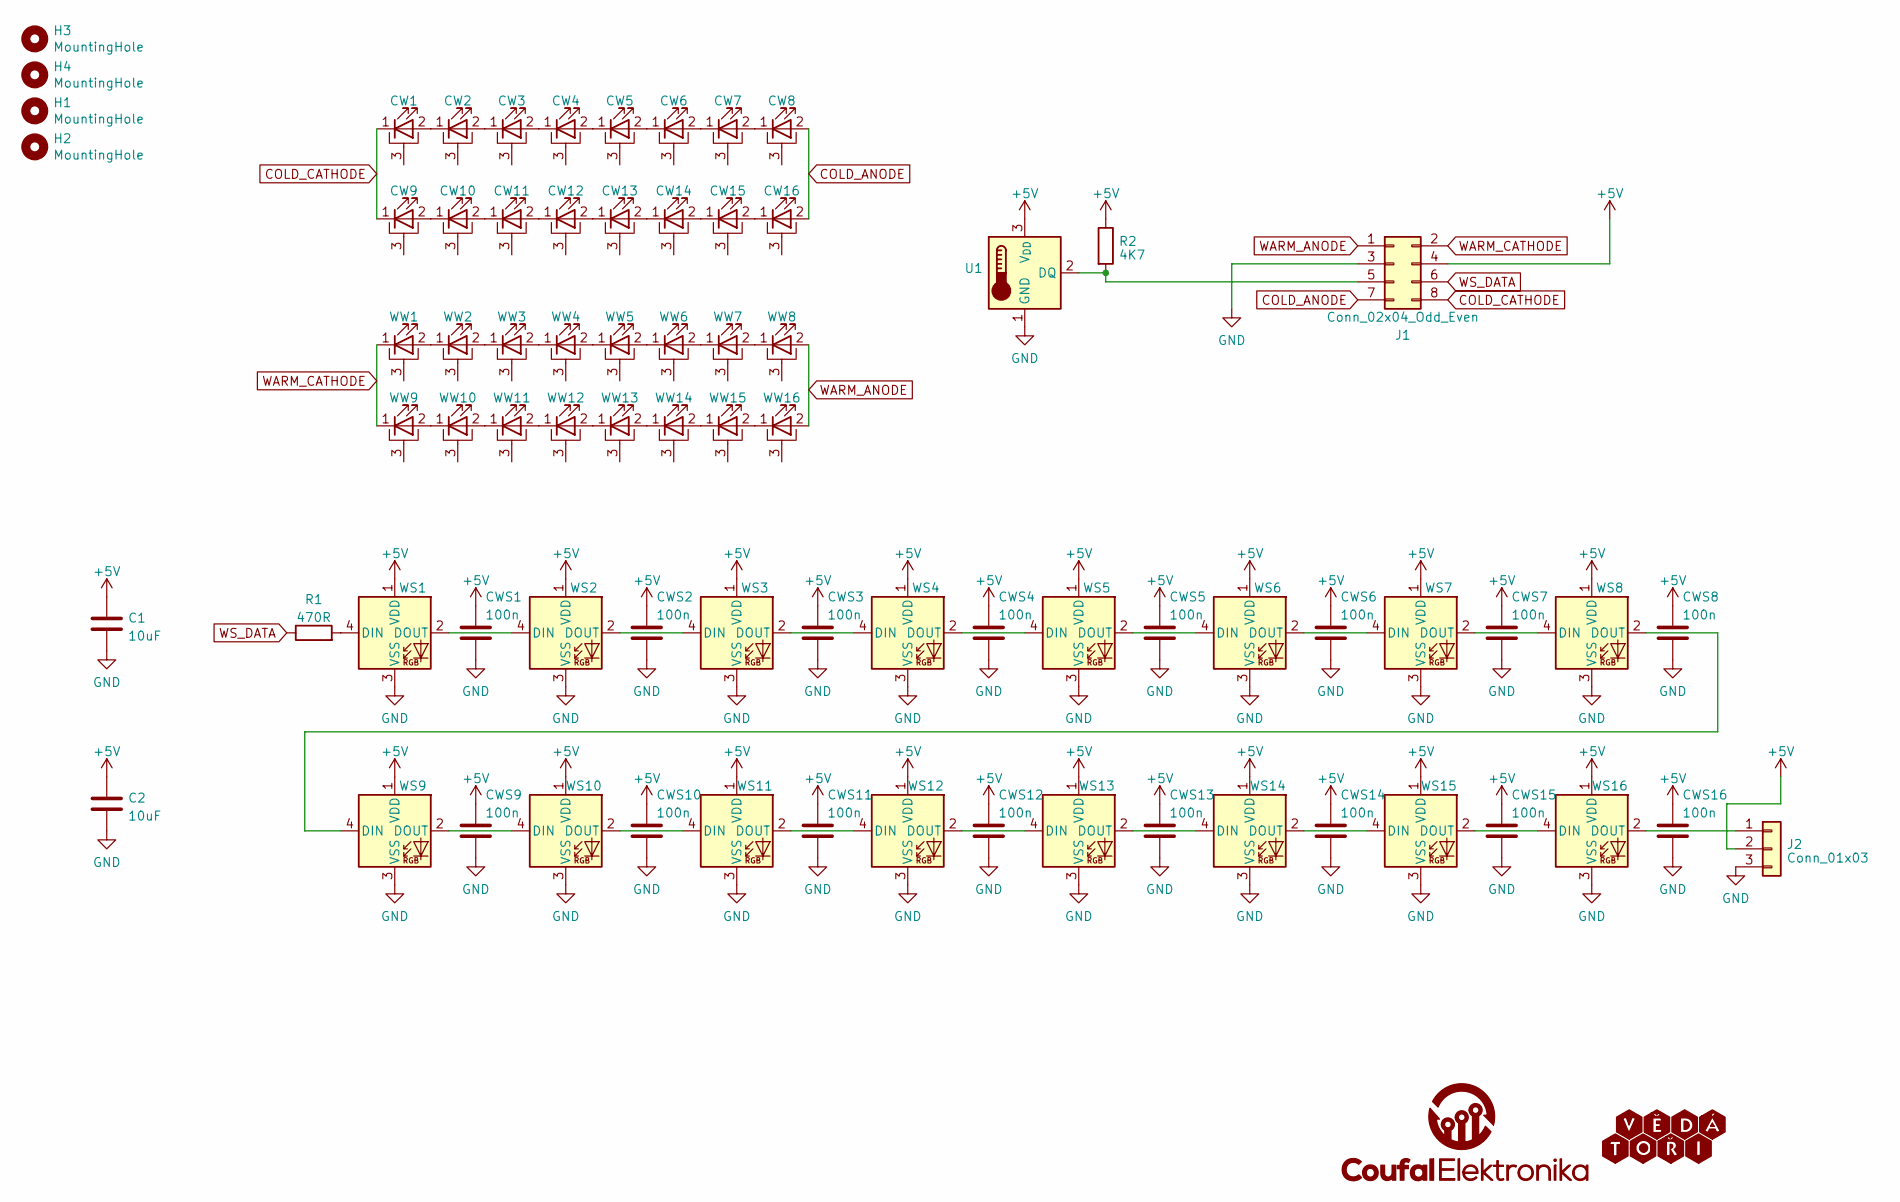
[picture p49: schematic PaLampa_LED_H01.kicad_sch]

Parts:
C1, C2: 10uF; C_0603_1608Metric; LCSC C19702
CW1, CW2, CW3, CW4, CW5, CW6, CW7, CW8, CW9, CW10, CW11, CW12, CW13, CW14, CW15, CW16: HL-A-5730D1W-S1-08-HR3(LY); HL-A-5730; LCSC C210348
CWS1, CWS2, CWS3, CWS4, CWS5, CWS6, CWS7, CWS8, CWS9, CWS10, CWS11, CWS12, CWS13, CWS14, CWS15, CWS16: 100n; C_0402_1005Metric; LCSC C1525
G1: CoufalElektronika_logo; Coufal_elektronika_notext_10mm
G2: Vedatori_logo; VedatoriNew_40x5,7mm
H1, H2, H3, H4: MountingHole; MountingHole_3.2mm_M3
J1: Conn_02x04_Odd_Even; IDC-Header_2x04_P2.54mm_Horizontal
J2: Conn_01x03; JST_XH_S3B-XH-A_1x03_P2.50mm_Horizontal
R1: 470R; R_0402_1005Metric; LCSC C25117
R2: 4K7; R_0402_1005Metric; LCSC C25900
U1: DS18B20; TO-92_Inline
WS1, WS2, WS3, WS4, WS5, WS6, WS7, WS8, WS9, WS10, WS11, WS12, WS13, WS14, WS15, WS16: XL-5050RGBC-WS2812B; LED_WS2812B_PLCC4_5.0x5.0mm_P3.2mm; LCSC C2843785
WW1, WW2, WW3, WW4, WW5, WW6, WW7, WW8, WW9, WW10, WW11, WW12, WW13, WW14, WW15, WW16: HL-A-5730D34W-S1-08-HR3(LY); HL-A-5730; LCSC C210345

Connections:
+5V: C1.1, C2.1, CWS1.1, CWS2.1, CWS3.1, CWS4.1, CWS5.1, CWS6.1, CWS7.1, CWS8.1, CWS9.1, CWS10.1, CWS11.1, CWS12.1, CWS13.1, CWS14.1, CWS15.1, CWS16.1, J1.4, J2.2, R2.1, U1.3 (V_{DD}), WS1.1 (VDD), WS2.1 (VDD), WS3.1 (VDD), WS4.1 (VDD), WS5.1 (VDD), WS6.1 (VDD), WS7.1 (VDD), WS8.1 (VDD), WS9.1 (VDD), WS10.1 (VDD), WS11.1 (VDD), WS12.1 (VDD), WS13.1 (VDD), WS14.1 (VDD), WS15.1 (VDD), WS16.1 (VDD)
COLD_ANODE: CW8.2 (A), CW16.2 (A), J1.7
COLD_CATHODE: CW1.1 (K), CW9.1 (K), J1.8
GND: C1.2, C2.2, CWS1.2, CWS2.2, CWS3.2, CWS4.2, CWS5.2, CWS6.2, CWS7.2, CWS8.2, CWS9.2, CWS10.2, CWS11.2, CWS12.2, CWS13.2, CWS14.2, CWS15.2, CWS16.2, J1.3, J2.3, U1.1 (GND), WS1.3 (VSS), WS2.3 (VSS), WS3.3 (VSS), WS4.3 (VSS), WS5.3 (VSS), WS6.3 (VSS), WS7.3 (VSS), WS8.3 (VSS), WS9.3 (VSS), WS10.3 (VSS), WS11.3 (VSS), WS12.3 (VSS), WS13.3 (VSS), WS14.3 (VSS), WS15.3 (VSS), WS16.3 (VSS)
unnamed: CW1.2 (A), CW2.1 (K)
unnamed: CW2.2 (A), CW3.1 (K)
unnamed: CW3.2 (A), CW4.1 (K)
unnamed: CW4.2 (A), CW5.1 (K)
unnamed: CW5.2 (A), CW6.1 (K)
unnamed: CW6.2 (A), CW7.1 (K)
unnamed: CW7.2 (A), CW8.1 (K)
unnamed: CW10.2 (A), CW11.1 (K)
unnamed: CW9.2 (A), CW10.1 (K)
unnamed: CW11.2 (A), CW12.1 (K)
unnamed: CW12.2 (A), CW13.1 (K)
unnamed: CW13.2 (A), CW14.1 (K)
unnamed: CW14.2 (A), CW15.1 (K)
unnamed: CW15.2 (A), CW16.1 (K)
unnamed: J1.5, R2.2, U1.2 (DQ)
unnamed: J2.1, WS16.2 (DOUT)
unnamed: R1.2, WS1.4 (DIN)
unnamed: WS1.2 (DOUT), WS2.4 (DIN)
unnamed: WS2.2 (DOUT), WS3.4 (DIN)
unnamed: WS3.2 (DOUT), WS4.4 (DIN)
unnamed: WS4.2 (DOUT), WS5.4 (DIN)
unnamed: WS5.2 (DOUT), WS6.4 (DIN)
unnamed: WS6.2 (DOUT), WS7.4 (DIN)
unnamed: WS7.2 (DOUT), WS8.4 (DIN)
unnamed: WS8.2 (DOUT), WS9.4 (DIN)
unnamed: WS9.2 (DOUT), WS10.4 (DIN)
unnamed: WS10.2 (DOUT), WS11.4 (DIN)
unnamed: WS11.2 (DOUT), WS12.4 (DIN)
unnamed: WS12.2 (DOUT), WS13.4 (DIN)
unnamed: WS13.2 (DOUT), WS14.4 (DIN)
unnamed: WS14.2 (DOUT), WS15.4 (DIN)
unnamed: WS15.2 (DOUT), WS16.4 (DIN)
unnamed: WW1.2 (A), WW2.1 (K)
unnamed: WW2.2 (A), WW3.1 (K)
unnamed: WW3.2 (A), WW4.1 (K)
unnamed: WW4.2 (A), WW5.1 (K)
unnamed: WW5.2 (A), WW6.1 (K)
unnamed: WW6.2 (A), WW7.1 (K)
unnamed: WW7.2 (A), WW8.1 (K)
unnamed: WW10.2 (A), WW11.1 (K)
unnamed: WW9.2 (A), WW10.1 (K)
unnamed: WW11.2 (A), WW12.1 (K)
unnamed: WW12.2 (A), WW13.1 (K)
unnamed: WW13.2 (A), WW14.1 (K)
unnamed: WW14.2 (A), WW15.1 (K)
unnamed: WW15.2 (A), WW16.1 (K)
WARM_ANODE: J1.1, WW8.2 (A), WW16.2 (A)
WARM_CATHODE: J1.2, WW1.1 (K), WW9.1 (K)
WS_DATA: J1.6, R1.1

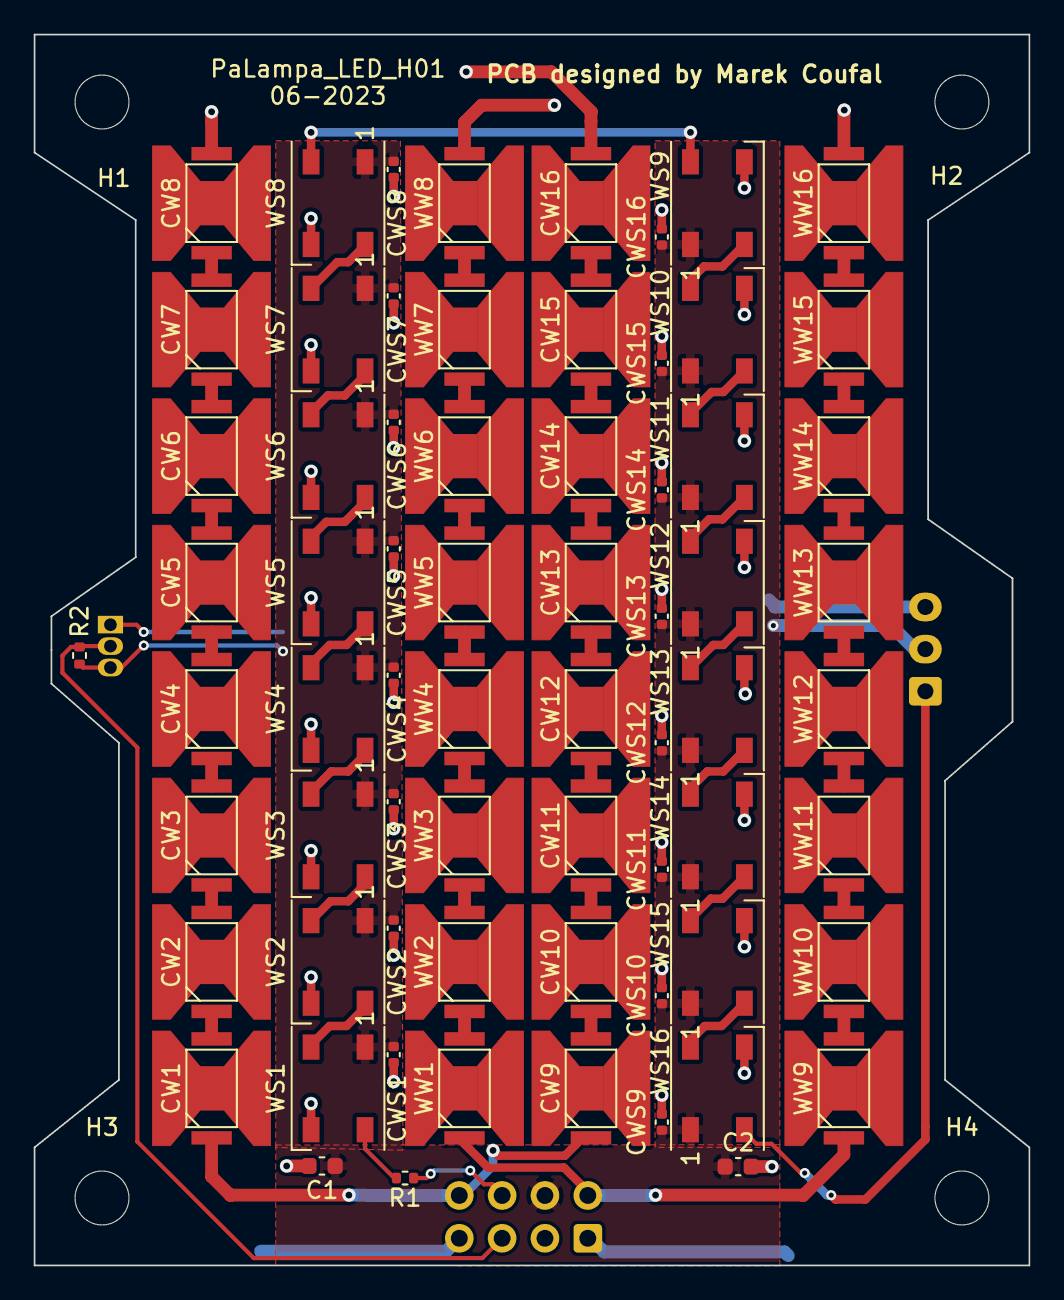
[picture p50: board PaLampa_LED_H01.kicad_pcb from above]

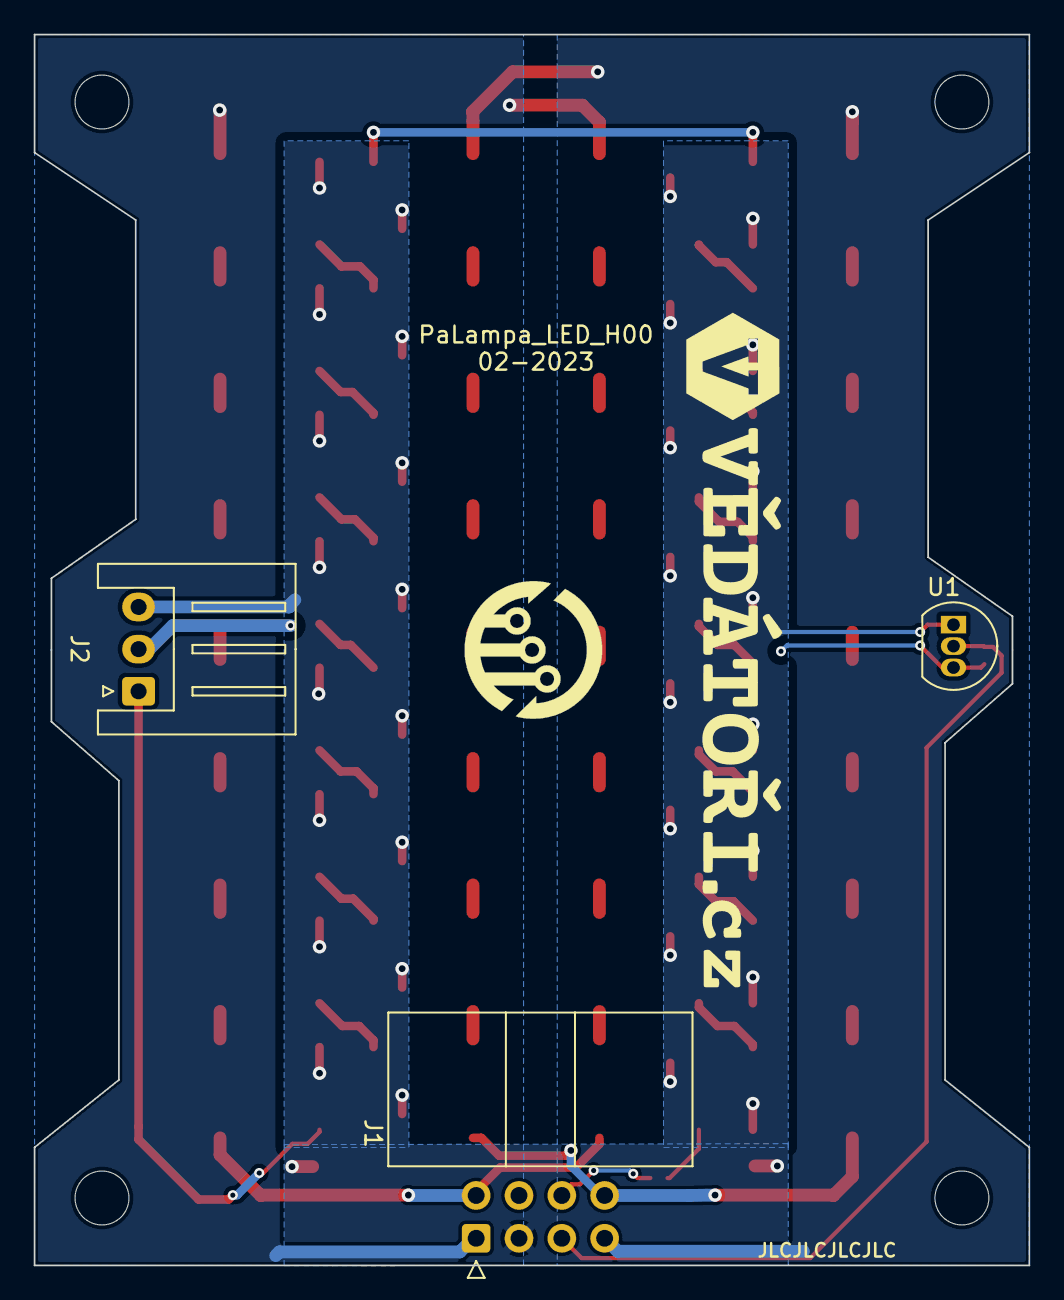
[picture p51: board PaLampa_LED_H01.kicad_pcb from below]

Board: 2 copper layers, 59.0 x 73.0 mm, 77 parts (5 on the bottom side), 53 nets.

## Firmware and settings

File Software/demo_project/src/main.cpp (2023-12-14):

#include "PaLampa/PaLampa.h"
#include "Arduino.h"

bool prevCapBtnState = false;
bool whiteOn = false;
float whiteBrightness = 0.0;
float whiteMix = 0.0;
float colorRed, colorGreen, colorBlue;
ColorRGB color = black;

void setup() {
    paLampa.begin();
    paLampa.startWiFiCaptain("<your_name>");
    paLampa.oled.sendClear();
    paLampa.lights.setColorTransition(all, Exponential, 2.0);
    paLampa.lights.setWhiteTransition({1, 1}, Exponential, 2.0);
}

void loop() {
    float potVal = paLampa.potentiometerRead();
    if(paLampa.buttonRead(0) && paLampa.buttonRead(1)){
        paLampa.piezo.playMelody(themeMelody);
    }
    else if(paLampa.buttonRead(0) && paLampa.buttonRead(2)) {
        ESP.restart();
    }
    else if(paLampa.buttonRead(1) && paLampa.buttonRead(2)) {
        color.blue = potVal;
    }
    else if (paLampa.buttonRead(0)) {
        whiteMix = potVal;
    }
    else if(paLampa.buttonRead(1)) {
        color.red = potVal;
    }
    else if(paLampa.buttonRead(2)) {
        color.green = potVal;
    }
    else {
        whiteBrightness = potVal;
    }

    bool newCapBtnState = paLampa.capButton.get(0);
    if(newCapBtnState != prevCapBtnState) {
        prevCapBtnState = newCapBtnState;
        if(newCapBtnState) {
            whiteOn = !whiteOn;
        }
    }
    if(whiteOn == false) {
        whiteBrightness = 0.0;
    }

    paLampa.lights.setWhiteMix(whiteBrightness, whiteMix);
    paLampa.lights.setColorPanels(all, color);

    static uint prevDiagTime = 0;
    if(millis() > prevDiagTime + 1000) {
        prevDiagTime = millis();
        paLampa.printDiagnostics();

        paLampa.oled.getDisplay().clearDisplay();
        paLampa.oled.getDisplay().setTextSize(4);
        paLampa.oled.getDisplay().setTextColor(WHITE);
        paLampa.oled.getDisplay().setCursor(6, 0);
        paLampa.oled.getDisplay().println(paLampa.timeModule.getClockText());
        paLampa.oled.getDisplay().display();
    }

    delay(100);
}

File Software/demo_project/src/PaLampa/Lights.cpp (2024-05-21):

#include "Lights.h"

ColorRGB red = {1, 0, 0};
ColorRGB green = {0, 1, 0};
ColorRGB blue = {0, 0, 1};
ColorRGB cyan = {0, 1, 1};
ColorRGB magenta = {1, 0, 1};
ColorRGB yellow = {1, 1, 0};
ColorRGB black = {0, 0, 0};
ColorRGB white = {1, 1, 1};
ColorRGB pink = {1, 0.75, 0.80};
ColorRGB brown = {0.65, 0.16, 0.16};
ColorRGB salmon = {0.98, 0.50, 0.45};
ColorRGB orange = {1, 0.65, 0};
ColorRGB gold = {1, 0.84, 0};

PanelSelector all = {1, 1};
PanelSelector top = {1, 0};
PanelSelector back = {0, 1};

ColorRGB dimColor(ColorRGB color, float brightness) {
    brightness = constrain(brightness, 0.0, 1.0);

    float * colorPtr = (float *)&color;
    for(int i = 0; i < 3; ++i) {
        colorPtr[i] = constrain(colorPtr[i] * brightness, 0, 1);
    }
    return color;
}

ColorRGB shiftColor(ColorRGB color, float red, float green, float blue) {
    color.red = constrain(color.red + red, 0, 1);
    color.green = constrain(color.green + green, 0, 1);
    color.blue = constrain(color.blue + blue, 0, 1);
    return color;
}

ColorRGB HSVtoRGB(ColorHSV color) {
    float H = color.hue;
    while(H < 0) {
        H += 360;
    }
    while(H > 360) {
        H -= 360;
    }
    float s = constrain(color.saturation, 0, 1);
    float v = constrain(color.value, 0, 1);

    float C = s*v;
    float X = C* (1- fabs(fmod(H / 60, 2)- 1));
    float m = v-C;
    float r, g, b;

    if(H > 300) {
        r = C;
        g = 0;
        b = X;
    }
    else if(H > 240) {
        r = X;
        g = 0;
        b = C;
    }
    else if(H > 180) {
        r = 0;
        g = X;
        b = C;
    }
    else if(H > 120) {
        r = 0;
        g = C;
        b = X;
    }
    else if(H > 60) {
        r = X;
        g = C;
        b = 0;
    }
    else {
        r = C;
        g = X;
        b = 0;
    }
    
    ColorRGB colorRGB;
    colorRGB.red = constrain((r+m), 0, 1);
    colorRGB.green = constrain((g+m), 0, 1);
    colorRGB.blue = constrain((b+m), 0, 1);
    return colorRGB;
}

ColorHSV RGBtoHSV(ColorRGB color) {
    float * colorPtr = (float *)&color;
    float colorNorm[3];
    for(int colorID = 0; colorID < 3; ++colorID) {
        colorNorm[colorID] = constrain(colorPtr[colorID], 0, 1);
    }

    int maxID = 0, minID = 0;  // 0-red, 1-green, 2-blue
    float mMax = 0, mMin = 0;
    if(colorNorm[0] >= colorNorm[1] && colorNorm[0] >= colorNorm[2]) {
        mMax = colorNorm[0];
        maxID = 0;
    }
    else if(colorNorm[1] >= colorNorm[0] && colorNorm[1] >= colorNorm[2]) {
        mMax = colorNorm[1];
        maxID = 1;
    }
    else {
        mMax = colorNorm[2];
        maxID = 2;
    }
    if(colorNorm[0] <= colorNorm[1] && colorNorm[0] <= colorNorm[2]) {
        mMin = colorNorm[0];
        minID = 0;
    }
    else if(colorNorm[1] <= colorNorm[0] && colorNorm[1] <= colorNorm[2]) {
        mMin = colorNorm[1];
        minID = 1;
    }
    else {
        mMin = colorNorm[2];
        minID = 2;
    }

    float c = mMax - mMin;
    float colorTemp[3];
    for(int colorID = 0; colorID < 3; ++colorID) {
        colorTemp[colorID] = (mMax - colorNorm[colorID]) / c;
    }
    float hTemp = 0;
    if(maxID == minID) {
        hTemp = 0;
    }
    else if (maxID == 0) {
        hTemp = colorTemp[2] - colorTemp[1];
    }
    else if (maxID == 1) {
        hTemp = 2 + colorTemp[0] - colorTemp[2];
    }
    else if (maxID == 2) {
        hTemp = 4 + colorTemp[1] - colorTemp[0];
    }
    while(hTemp < 0) {
        hTemp += 6.0;
    }
    while(hTemp > 6.0) {
        hTemp -= 6.0;
    }

    float hue = hTemp / 6 * 360;
    float saturation = c / mMax;
    float value = mMax;

    ColorHSV colorHSV;
    colorHSV.hue = constrain(hue, 0, 360);
    colorHSV.saturation = constrain(saturation, 0, 1);
    colorHSV.value = constrain(value, 0, 1);
    return colorHSV;
}

bool Lights::isPanelSelected(PanelSelector selector, int panelID) {
    switch(panelID) {
        case 0:
            return selector.top;
        case 1:
            return selector.back;
        default:
            return false;
    }
}

int Lights::getPanelID(int ledID) {
    if(ledID < 0)
        return -1;
    if(ledID < 16)
        return 0;
    if(ledID < 23)
        return 1;
    else
        return -1;
}

int Lights::getLedAbsID(int panelID, int ledID) {
    if(panelID < 0 || panelID > 1)
        return -1;
    if(ledID < 0 || ledID > 15)
        return -1;
    
    int ledAbsoluteID = 0;

    // Top LEDs
    if(panelID == 0)
        ledAbsoluteID = ledID;

    // Back LEDs
    else if(panelID == 1) {
        if(ledID > 6)
            return -1;
        ledAbsoluteID = 16 + ledID;
    }

    if(ledAbsoluteID < 0 || ledAbsoluteID > PL::LED_RGB_COUNT) {
        return -1;
    }
    return ledAbsoluteID;
}

ColorRGB Lights::updateLedColorState(LedColorState& state, int timeStep) {
    ColorRGB targetColorDim = dimColor(state.targetColor, state.brightness);
    float * targetColorDimPtr = (float *)&targetColorDim;
    float * currentColorPtr = (float *)&state.currentColor;

    float deviation[3];
    for(int ledID = 0; ledID < 3; ++ledID) {
        deviation[ledID] = targetColorDimPtr[ledID] - currentColorPtr[ledID];
    }

    float step = 0;
    switch(state.transitionType) {
        case Linear: {
            step = timeStep / 1000.0 * 1.732 / state.transitionTime;
        } break;
        case Exponential: {
            float currentColorSize = pow(pow(currentColorPtr[0], 2) + pow(currentColorPtr[1], 2) + pow(currentColorPtr[2], 2), 0.5);
            float beginStep = 0.00006 * timeStep;
            step = beginStep + currentColorSize * (pow(1.732 / beginStep, timeStep / 1000.0 / state.transitionTime) - 1.0);
        } break;
        case None:
        default:
            step = 1.732;    // Maximal step to cover full diagonal at once
    }

    float devSize = pow(pow(deviation[0], 2) + pow(deviation[1], 2) + pow(deviation[2], 2), 0.5);
    float newColor[3];
    float * newColorPtr = (float *)&newColor;
    for(int ledID = 0; ledID < 3; ++ledID) {
        if(devSize < (step + PL::TRANS_END_THR)) {
            newColorPtr[ledID] = targetColorDimPtr[ledID];
        }
        else {
            newColorPtr[ledID] = currentColorPtr[ledID] + deviation[ledID] / devSize * step;
        }
    }
    state.updateNeeded = devSize > PL::TRANS_END_THR;

    for(int ledID = 0; ledID < 3; ++ledID) {
        currentColorPtr[ledID] = constrain(newColorPtr[ledID], 0, 1);
    }

    return state.currentColor;
}
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

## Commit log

2023-01-30 First HW commit
    [LED 5730.stp, LED_Drivers.kicad_sch, OLED-128x64-0.96.step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]
2023-02-09 HW updates
    [LED_Drivers.kicad_sch, PaLampa_MoBo_H00.kicad_pcb, PaLampa_MoBo_H00.kicad_sch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]
2023-03-19 MoBo changes, exported LED step
    [PaLampa_LED_H00.step]
2023-03-19 Updated projects to KiCad 7.0
    [LED_Drivers.kicad_sch, PaLampa_LED_H00.kicad_pcb, PaLampa_LED_H00.kicad_sch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]
2023-04-13 Completed H00 revision. Added production data.
    [PaLampa_LED_H00.kicad_pcb, PaLampa_MoBo_H00.kicad_pcb, PaLampa_MoBo_H00.kicad_sch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]
2023-04-14 changed electrolytic capacitor part number
    [USB+Power.kicad_sch]
2023-06-12 Cloned boards for H01 revisions.
    [LED_Drivers.kicad_sch, PaLampa_LED_H01.kicad_pcb, PaLampa_LED_H01.kicad_sch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]
2023-06-15 H01 changes
    [LED_Drivers.kicad_sch, PaLampa_LED_H01.kicad_pcb, PaLampa_LED_H01.kicad_sch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]
2023-06-15 LED board H01 update
    [PaLampa_LED_H01.kicad_pcb, PaLampa_LED_H01.step]
2023-06-15 H01 update
    [LED_Drivers.kicad_sch, PaLampa_LED_H01.kicad_pcb, PaLampa_MoBo_H01.kicad_pcb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]
2023-06-15 H01 updates
    [PaLampa_MoBo_H01.kicad_pcb, bom.csv, designators.csv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]
2023-08-13 Fixed capacitive Cu strip info.
2023-08-13 Light module power limit.
2023-08-14 Mechanical manual LED stripe orientation fix.
2023-08-15 Fixed LED exponential transition and LED refreshing.
    [Lights.cpp, Lights.h, main.cpp]
2023-08-16 Transitions for white LEDs.
2023-08-16 Fixed ledc channels and button modes setup.
    [Lights.h, PaLampa.cpp, PaLampa.h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]
2023-08-17 Capacitive button library added
2023-08-17 Time module (#5)
    * Time module initial commit
    * Implemented additional time.h functions
    * Added Time_module features
    * Improved time module
    * Time-module bugfix
    [PaLampa.cpp, PaLampa.h]
2023-08-17 Capacitive button library added to programming manual
2023-08-17 Limiting light current to control temperature.
2023-08-18 Fixed cap button lections
2023-08-18 White lights temperature functions
2023-08-18 Fix touch sensor update.
    [PaLampa.cpp]
2023-08-18 Power module basics.
2023-08-22 Czech readme text draft. Updated CapacitiveButton module.
2023-11-09 Mechnics manual fixes and screws list.
